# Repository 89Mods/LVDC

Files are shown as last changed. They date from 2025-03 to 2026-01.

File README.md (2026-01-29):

# LVDC
Replica of the [Launch Vehicle Digital Computer](https://www.ibiblio.org/apollo/LVDC.html) using 74-series logic. This projects only aims to keep the CPU Architecture binary-compatible with the original. Implementation details, IO Peripherals and Software are all originally created by me. This is party due to the fact that detailed hardware descriptions (i.e. schematics) are not as abundant for the LVDC as for the AGC, but also because this project doubled as a challenge to myself to implement such an odd instruction set, but using every trick I’ve learned from my years of engineering integrated circuit layouts. It turns out that applying nanoscale engineering tricks to a macroscale discrete logic build can work out quite well. The clock speed of this computer is 2.5MHz, but it can probably go faster.

This LVDC is accurate to the original in the sense that it executes the same instructions that function the exact same, has the same memory layout (including special locations like HOP save and MQ) and can execute snippets of original LVDC code.

The differences are:
  - This computer is parallel and not bit-serial, and is also microcoded
  - It is implemented using 74-series logic and not discrete transistors (I wish to be able to take it with me to events, so it couldn’t get too big)
  - Everything hooked up to the PIO (IO read/write) instruction is my own invention, with the exception of the the interrupt latch clear IO location, which it shares with the original LVDC
  - Instruction cycles times are much faster, probably on an order of magnitude or more
  - The hardware multiply/divide circuitry (as designed so far) does NOT share the inacuracies in low-order bits as the original LVDC, instead always producing the 100% correct result

Infact, I took the most liberties with the IO Card, which contains various modern components hooked into the CPU’s IO Bus. Its mostly a random mashup of things I thought would be cool (there is even a Commodore SID replica in there) to demonstrate the computer with.

The most significant addition is that of a front panel (the original LVDC was an embedded device with no user interface) which is a bit like a DSKY, but stripped down and only capable of displaying in hexadecimal. The panel is optional. I can be safely removed and the computer used as a true embedded device.

Software wise, things are still WiP. Two ROMs provide just enough storage for a small bootloader to initialize the entire SRAM from a flash IC. Sadly, core memory is far too bulky and expensive, so this will have to do. I created a mini-OS for this system that allows a user to control the computer by typing in commands consisting of a Noun and Verb into the keypad.

**Known Issues:**
  - The HOP Save feature is bugged. The Instruction Pointer in the stored value is off by one. Trying to return with it will return execution to the transfer or HOP instruction that started the subroutine call, not the one following it, triggering an infinite loop. Fixed for now in software by modifying the saved value before return.
  - While all schematic files have been updated with fixes to additional problems discovered post-production, the schematic layout for the Control board still need to be redone.
  - The EXM instruction has only been minimally tested because I don’t understand how it is useful (thing takes up half a dozen ICs just to handle weird edge cases caused by it and I’m still left scratching my head on how I’m supposed to use it).
  - The hardware multiply/divide functionality has yet to be physically implemented. In `LVDC.circ` you can see that I have designed it, but I’ve yet to translate this to a PCB design because I couldn’t get it made yet anyways (its the most expensive part of the whole computer).
  - The interrupt logic sometimes does not reset properly and I don’t understand why

# Repository Structure

`LVDC.circ` is where I prototyped the logic design using Logisim Evolution, but it is quite bugged and now far outdated.

`microcode_gen.c` is the C program that spits out the raw binary images for the microcode ROMs from a more high-level description.

`KiCad` is where the schematics and PCB layouts live. Related to this is `CPLD`, which holds the HDL code for the CPLD on the GPIO PCB.

`Bench` is the result of using [KiCadVerilog](https://github.com/89Mods/KiCadVerilog) to automatically extract Verilog netlists out of the KiCad schematic files and using them to build a simulation of the computer for verification purposes before starting physical production. This is quite a novel approach and I used it here for the first time.

`behavioral` contains a Behavioral Verilog model of the LVDC I used as a starting point. It is incredibly inaccurate as I have not updated it in same time.

`Programs` contains the software I’m writing for this computer. Currently just the Bootloader source and the WiP mini-OS mentioned earlier. [My fork of the AS Macroassembler](https://github.com/AvalonSemiconductors/asl-avalonsemi/) has support for the LVDC, and this is used to assemble all LVDC code in this directory.

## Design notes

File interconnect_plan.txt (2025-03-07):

AS2650-2 on FP

Required backplane signals

Bus (26)
INSTR (13)
NC
CLK
RST
VCC
GND

Total: 44

On dedicated ribbon connectors:
From Register to Memory:
INSTR_SECTOR (4)
INSTR_MODULE (3)
INSTR_ADD (8)
DATA_SECTOR (4)
DATA_MODULE (3)
Total: 22

From Registers to ALU:
Accum (26)

Total: 26

Ctrl to ALU:
IS_RSU
ALU_R
ALU_ISS

Total: 3

Ctrl to Registers:
ACCW
R_A
CDS
TRA
INCPC
R_H
HOPW
H_CYC_1
CSYLLABLE
ACCUM_ZERO
ACCUM_NEGATIVE

Total: 11

Ctrl to Memory:
FETCH_CYC
MEM_WR
MEM_RD
irupt
EXM_EXEC_I
EXM_SECTOR (3)
RESIDUAL_I
IS_EXM_I
PQ_ADDR
HOP_INSTE

Total: 12

Ctrl to muldiv:
OUTPUT_PQ
MUL_RST
LDX
LDY
IS_DIV
LDZ
START
IS_ACTIVE

Total: 8

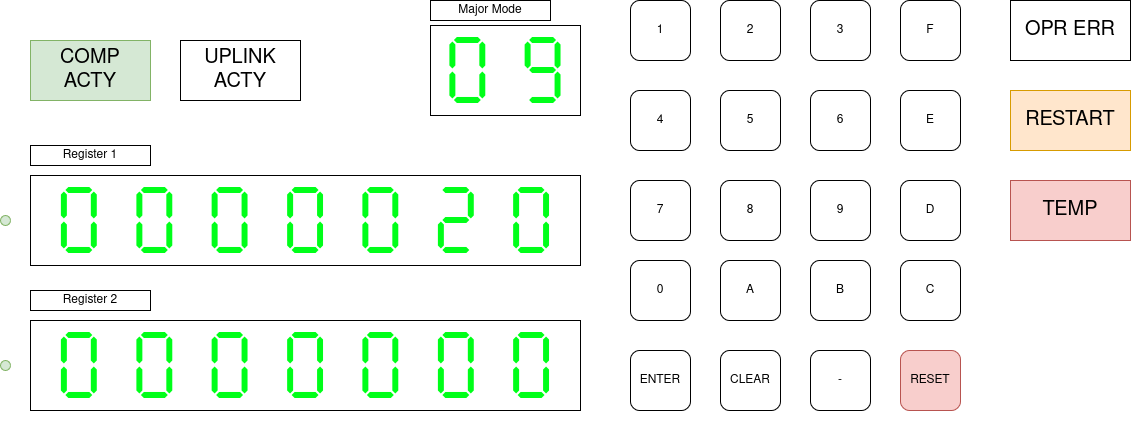
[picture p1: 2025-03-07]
FP_DESIGN.png

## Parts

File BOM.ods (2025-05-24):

Value | Qty | Mouser | Unit Price | Total Price | Comment
74HCT04 | 10 | 771-74HCT04D-Q100118 | 0.386 | 3.86
74HCT157 | 60 | 771-74HCT157D-T | 0.219 | 13.14
74HCT08 | 18 | 771-74HCT08D-T | 0.168 | 3.024
74HCT32 | 15 | 771-74HCT32D-T | 0.168 | 2.52
74HCT153 | 16 | 771-74HCT153D-T | 0.295 | 4.72
74HCT574 | 25 | 771-74HCT574D-T | 0.295 | 7.375
Terminal Block 01x02 | 3 | 651-1548128 | 1.02 | 3.06
Resistor Network | 10 | 652-4609M-1LF-10K | 0.363 | 3.63
74HCT244 | 22 | 771-74HCT244D-Q100 | 0.34 | 7.48
74HCT163 (DIP) | 1 | 595-CD74HCT163E | 0.855 | 0.855
74HCT00 | 5 | 771-74HCT00D-Q100118 | 0.352 | 1.76
74HCT74 | 15 | 771-74HCT74D-Q100118 | 0.217 | 3.255
74HCT138 | 10 | 771-74HCT138D-T | 0.177 | 1.77
MCP1319MT-29LE | 3 | 579-MCP1319MT29LE/OT | 0.817 | 2.451
74LV1T34DCK | 31 | 595-SN74LV1T34DCKR | 0.135 | 4.185
74ALVC164245 | 1 | 972-74ALVC164245PVG | 1.28 | 1.28
LM358 | 1 | 595-LM358P | 0.219 | 0.219
74AHC1G86 | 10 | 621-74AHC1G86W5-7 | 0.141 | 1.41
8MHz can Osc | 1 | 520-TCH800-X | 2.99 | 2.99
74HCT11 | 5 | 771-74HCT11D-Q100J | 0.371 | 1.855
74HCT02 | 5 | 771-74HCT02D-T | 0.228 | 1.14
74HCT245 | 5 | 771-74HCT245DQ100J | 0.713 | 3.565
74HC86 | 10 | 771-74HC86D-Q100118 | 0.144 | 1.44
LM35-LP | 5 | 926-LM35DZ/LFT4 | 1.27 | 6.35
LM397 | 5 | 926-LM397MF/NOPB | 1.14 | 5.7
74LVC573 | 5 | 771-74LVC573APW-T | 0.333 | 1.665
65LV256AL | 3 | 870-65LV256AL-45TLA3 | 3.35 | 10.05
1µF Caps | Many | 810-CGA4J3X7R1H105MS
 |  |  |  | 100.749
Value | Qty |  |  | Total Price | Link
2x15 2.54mm Male | 3 |  |  | 4.19 | https://de.aliexpress.com/item/1005004266492521.html
2x22 2.54mm Male | 6 |  |  | 2.35 | https://de.aliexpress.com/item/1005006240551154.html
2x04 2.54mm Male | 3 |  |  | 2.95 | https://de.aliexpress.com/item/1005004266492521.html
2x06 2.54mm Male | 4 |  |  | 3.05 | https://de.aliexpress.com/item/1005004266492521.html
28C16 | 5 |  |  | 12.99 | https://de.aliexpress.com/item/4001115719545.html
2x25 2.54mm Male | 2 |  |  | 0 | Covered by earlier entry
SM420561 | 16 |  |  | 6.38 | https://de.aliexpress.com/item/1005004362200093.html
2x05 2.54mm Male | 1 |  |  | 2.89 | https://de.aliexpress.com/item/1005004266492521.html
1x04 2.54mm Male | 3 |  |  | 1.59 | https://de.aliexpress.com/item/4000988113226.html
1x04 2.54mm Female | 2 |  |  | 1.35 | https://de.aliexpress.com/item/4001198421663.html
2x22 2.54mm Female | 6 |  |  | 3.19 | https://de.aliexpress.com/item/1005005884302067.html
02x12 2.54mm Male | 2 | N/A | N/A | 0 | Covered by earlier entry
01x03 2.54mm Male | 5 | N/A | N/A | 0 | Covered by earlier entry
2x15 Ribbon Band | 1 |  |  | 3.59 | https://de.aliexpress.com/item/1005004762590129.html
2x04 Ribbon Band | 2 |  |  | 4.78 | https://de.aliexpress.com/item/1005004762590129.html
2x06 Ribbon Band | 2 |  |  | 5.18 | https://de.aliexpress.com/item/1005004762590129.html
2x12 Ribbon Band | 1 |  |  | 3.19 | https://de.aliexpress.com/item/1005004762590129.html
2x25 Ribbon Band (long) | 1 |  |  | 8.49 | https://de.aliexpress.com/item/1005004762590129.html
Shrinkwrap | 1 |  |  | 1.85 | https://de.aliexpress.com/item/1005008146302901.html
65LV256AL |  |  |  | 68.01
 |  |  |  | 168.759
 | 1 |  |  |  | https://de.aliexpress.com/item/32979408725.html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

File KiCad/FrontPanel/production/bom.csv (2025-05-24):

Designator | Footprint | Quantity | Value | LCSC Part #
_6, _5, _4, _3, _2, |  | 6
C1, C3, C4 | 0805 | 3 | 1µF
C2 | 0805 | 1 | 100nF
C5 | CP_Radial_D6.3mm_P2.50mm | 1 | 1000µF
D1, D10, D11, D12, D13, D14, D15, D16, D17, D18, D19, D2, D20, D3, D4, D5, D6, D7, D8, D9 | 1206 | 20 | LED
D21, D22 | LED_D5.0mm | 2 | LED
J1 | PinHeader_2x25_P2.54mm_Vertical | 1 | TO_FP
Q1, Q2, Q3, Q4, Q5 | SOT-23 | 5 | 2N7002
R1, R10, R11, R12, R13, R14, R15, R16, R17, R18, R19, R2, R3, R4, R5, R6, R7, R8, R9 | 1206 | 19 | 1K
R20, R21, R22, R23, R24, R25, R26, R27, R28, R29, R30, R31, R32, R33, R34, R35 | 1206 | 16 | 470
R36, R37, R38, R39, R40, R41, R42 | 1206 | 7 | 330
R43 | 1206 | 1 | 200K
SW1, SW10, SW11, SW12, SW13, SW14, SW15, SW16, SW17, SW18, SW19, SW2, SW20, SW3, SW4, SW5, SW6, SW7, SW8, SW9 | SW_Cherry_MX_1.00u_PCB | 20 | SW_Push
U1, U4, U5 | SO-20_12.8x7.5mm_P1.27mm | 3 | 74HC244
U10, U11, U12, U13, U14, U15, U16, U17, U18, U19, U20, U21, U6, U7, U8, U9 | 7SegmentLED_LTS6760_LTS6780 | 16 | SM420561N
U2, U3 | SO-16_3.9x9.9mm_P1.27mm | 2 | 74HCT138
U22 | SOIC-8_3.9x4.9mm_P1.27mm | 1 | NE555D

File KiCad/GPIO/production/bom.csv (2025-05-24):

Designator | Footprint | Quantity | Value | LCSC Part #
C1 | CP_Radial_D4.0mm_P2.00mm | 1 | 10µF
C10, C11, C12, C13, C14, C15, C16, C17, C18, C2, C3, C4, C5, C6, C7, C8, C9 | 0805 | 17 | 1µF
D1, D2 | 1206 | 2 | LED
J1 | PinHeader_2x05_P2.54mm_Vertical | 1 | JTAG
J10, J3, J4, J5 | PinHeader_1x01_P2.54mm_Vertical | 4 | Conn_01x01
J11 | PinHeader_2x25_P2.54mm_Vertical | 1 | TO_FP
J12, J16, J7, J8 | PinHeader_1x04_P2.54mm_Vertical | 4 | Conn_01x04
J13, J14 | PinHeader_1x08_P2.54mm_Vertical | 2 | Conn_01x08
J15, J9 | PinSocket_1x04_P2.54mm_Vertical | 2 | RADIO_MODULE
J2 | PinHeader_2x22_P2.54mm_Vertical | 1 | TO_BACKPLANE
J6 | TerminalBlock_bornier-2_P5.08mm | 1 | AUDIO_OUT
R1, R10, R11, R13, R14, R16, R17, R2, R20, R21, R22, R23, R24, R25, R26, R27, R28, R29, R3, R30, R31, R32, R33, R34, R35, R36, R37, R39, R4, R5, R6, R7, R8, R9 | 1206 | 34 | 10K
R12 | 1206 | 1 | 330
R15, R18 | 1206 | 2 | 1K
R19 | 1206 | 1 | 33K
R38 | 1206 | 1 | 2K
R40 | 1206 | 1 | 1M
RV1 | Potentiometer_ACP_CA9-V10_Vertical | 1 | 10K
U1 | LQFP-100_14x14mm_P0.5mm | 1 | EPM240T100
U10 | TSSOP-48_6.1x12.5mm_P0.5mm | 1 | SN74ALVC164245DGG
U11, U12, U13, U14, U20, U21, U22, U24, U27, U28, U33, U34, U35, U8, U9 | SOT-23-5 | 15 | SN74LV1T34DCK
U15 | SO-14_3.9x8.65mm_P1.27mm | 1 | 74HC74
U16 | DIP-40_W15.24mm_Socket | 1 | gfmpw1-multi
U17, U18 | DIP-8_W7.62mm | 2 | DAC7611
U19 | DIP-8_W7.62mm | 1 | LM358
U2 | SOT-23-5_HandSoldering | 1 | MCP1319MT-29LE-OT
U23 | DIP-18_W7.62mm | 1 | HT12D
U25, U26, U6 | SO-20_12.8x7.5mm_P1.27mm | 3 | 74HCT244
U29 | SO-14_3.9x8.65mm_P1.27mm | 1 | 74HC32
U3 | DIP-8_W7.62mm_Socket | 1 | W25Q32FVSS
U30, U5 | SO-20_12.8x7.5mm_P1.27mm | 2 | 74HC574
U31 | SOT-23-5_HandSoldering | 1 | 74AHC1G86
U32 | DIP-18_W7.62mm | 1 | HT12E
U4 | SOT-223-3_TabPin2 | 1 | AMS1117-3.3
U7 | SO-14_3.9x8.65mm_P1.27mm | 1 | 74HCT74
X1 | Oscillator_DIP-8 | 1 | CXO_DIP8

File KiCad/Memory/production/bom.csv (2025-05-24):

Designator | Footprint | Quantity | Value | LCSC Part #
C1, C3, C5, C7 | CP_Radial_D4.0mm_P2.00mm | 4 | 10µF
C10, C11, C12, C13, C14, C2, C4, C6, C8, C9 | 0805 | 10 | 100nF
D1 | 1206 | 1 | LED
J1 | PinHeader_2x06_P2.54mm_Vertical | 1 | FROM_CTRL
J2 | PinHeader_2x12_P2.54mm_Vertical | 1 | FROM_REGS
J3 | PinHeader_2x22_P2.54mm_Vertical | 1 | TO_BACKPLANE
R1 | 1206 | 1 | 1K
R10, R2, R3, R4, R5, R6, R7, R8, R9 | 1206 | 9 | 10K
RN1, RN2, RN3 | R_Array_SIP9 | 3 | R_Network08
U1, U5 | SO-14_3.9x8.65mm_P1.27mm | 2 | 74HCT32
U10, U11, U12, U4, U9 | SO-16_3.9x9.9mm_P1.27mm | 5 | 74HCT157
U13 | SO-20_12.8x7.5mm_P1.27mm | 1 | 74HC688
U14, U2, U8 | SO-14_3.9x8.65mm_P1.27mm | 3 | 74HCT08
U15 | SO-14_3.9x8.65mm_P1.27mm | 1 | 74HC32
U16, U17 | DIP-24_W15.24mm | 2 | 28C16
U18 | SO-14_3.9x8.65mm_P1.27mm | 1 | 74HCT00
U19 | SO-14_3.9x8.65mm_P1.27mm | 1 | 74HC02
U20, U21, U22, U23 | SO-20_12.8x7.5mm_P1.27mm | 4 | 74HCT245
U24, U25, U26, U27 | DIP-28_W7.62mm | 4 | IS61C256
U3 | SO-14_3.9x8.65mm_P1.27mm | 1 | 74HCT04
U6, U7 | SO-14_3.9x8.65mm_P1.27mm | 2 | 74HCT11

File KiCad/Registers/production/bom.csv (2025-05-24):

Designator | Footprint | Quantity | Value | LCSC Part #
C1, C10, C11, C13, C14, C15, C3, C6, C8, C9 | 0805 | 10 | 100nF
C12, C16, C17, C2, C4, C5, C7 | CP_Radial_D4.0mm_P2.00mm | 7 | 10µF
D1, D10, D11, D12, D13, D14, D15, D16, D2, D3, D4, D5, D6, D7, D8, D9 | 1206 | 16 | LED
J1 | PinHeader_2x22_P2.54mm_Vertical | 1 | TO_BACKPLANE
J2 | PinHeader_2x15_P2.54mm_Vertical | 1 | ACCUMULATOR_OUT
J3 | PinHeader_2x06_P2.54mm_Vertical | 1 | FROM_CTRL
J4 | PinHeader_2x12_P2.54mm_Vertical | 1 | TO_MEMORY
J5 | PinHeader_2x15_P2.54mm_Vertical | 1 | TO_FP
R1, R2, R3, R4, R5, R6, R8 | 1206 | 7 | 1K
R7, R9 | 1206 | 2 | 4.7K
U1, U11, U16, U17, U18, U33, U34, U35, U36, U7 | SO-20_12.8x7.5mm_P1.27mm | 10 | 74HC574
U10, U13, U2, U20, U21, U22, U23, U24, U25, U26, U3, U41, U42, U43, U44, U45, U5, U6, U9 | SO-16_3.9x9.9mm_P1.27mm | 19 | 74HCT157
U12, U15, U4, U46, U47, U48, U49, U8 | SO-20_12.8x7.5mm_P1.27mm | 8 | 74HC244
U14, U19, U31 | SO-14_3.9x8.65mm_P1.27mm | 3 | 74HC74
U27, U28 | SO-14_3.9x8.65mm_P1.27mm | 2 | 74HC86
U29, U30 | SO-14_3.9x8.65mm_P1.27mm | 2 | 74HC08
U32 | SO-14_3.9x8.65mm_P1.27mm | 1 | 74HCT32
U37, U38, U39, U40 | SO-20_12.8x7.5mm_P1.27mm | 4 | 74HC688
U50 | SOIC-6 | 1 | 74AHC1G04

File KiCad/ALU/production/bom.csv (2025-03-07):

Designator | Footprint | Quantity | Value | LCSC Part #
C1, C10, C11, C12, C13, C14, C15, C16, C17, C18, C19, C20, C4, C6, C8 | 0805 | 15 | 100nF
C2, C21, C22, C3, C5, C7, C9 | CP_Radial_D4.0mm_P2.00mm | 7 | 10µF
D1, D2, D3 | 1206 | 3 | LED
J1 | PinHeader_2x15_P2.54mm_Vertical | 1 | ACCUMULATOR
J2 | PinHeader_2x22_P2.54mm_Vertical | 1 | TO_BACKPLANE
J3 | PinHeader_2x04_P2.54mm_Vertical | 1 | FROM_CTRL
R1, R2, R3, R4 | 1206 | 4 | 1K
TP1 | TestPoint_Pad_1.5x1.5mm | 1 | TestPoint
U1 | SO-14_3.9x8.65mm_P1.27mm | 1 | 74HCT04
U10, U11, U12, U13, U14, U15, U2, U3, U4, U40, U41, U43, U44, U46, U47, U49, U5, U6, U7, U8, U9 | SO-16_3.9x9.9mm_P1.27mm | 21 | 74HCT157
U16, U17, U18, U19, U20, U21, U22 | DIP-24_W15.24mm | 7 | 74LS181
U23, U24 | SO-14_3.9x8.65mm_P1.27mm | 2 | 74HCT08
U25, U27 | SO-14_3.9x8.65mm_P1.27mm | 2 | 74HCT32
U26, U28, U29, U30, U31, U32, U33, U34, U35, U36, U37, U38, U39 | SO-16_3.9x9.9mm_P1.27mm | 13 | 74HCT153
U42, U45, U48, U50 | SO-20_12.8x7.5mm_P1.27mm | 4 | 74HCT574

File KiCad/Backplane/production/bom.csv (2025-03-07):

Designator | Footprint | Quantity | Value | LCSC Part #
_5, _4, _3, _2, |  | 5
C1 | 0805 | 1 | 100nF
C2 | CP_Radial_D4.0mm_P2.00mm | 1 | 10µF
C3 | 0805 | 1 | 1µF
D1, D2 | 1206 | 2 | LED
J1 | PinHeader_2x22_P2.54mm_Vertical | 1 | SLOT1
J2 | PinHeader_2x22_P2.54mm_Vertical | 1 | SLOT2
J3 | PinHeader_2x22_P2.54mm_Vertical | 1 | SLOT3
J4 | PinHeader_2x22_P2.54mm_Vertical | 1 | SLOT4
J5 | PinHeader_2x22_P2.54mm_Vertical | 1 | SLOT5
J6 | PinHeader_2x22_P2.54mm_Vertical | 1 | GPIO
J7, J8 | TerminalBlock_bornier-2_P5.08mm | 2 | Screw_Terminal_01x02
R1, R2, R3, R4, R5, R6, R7 | 1206 | 7 | 2K
RN1, RN2, RN3 | R_Array_SIP9 | 3 | R_Network08
U1 | DIP-14_W7.62mm | 1 | 74HCT04

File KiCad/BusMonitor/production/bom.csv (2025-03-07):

Designator | Footprint | Quantity | Value | LCSC Part #
C1 | 0805 | 1 | 100nF
C2 | CP_Radial_D4.0mm_P2.00mm | 1 | 10µF
D1, D10, D11, D12, D13, D14, D15, D16, D17, D18, D19, D2, D20, D21, D22, D23, D24, D25, D26, D27, D28, D29, D3, D30, D31, D32, D33, D34, D35, D36, D37, D38, D39, D4, D40, D5, D6, D7, D8, D9 | 1206 | 40 | LED
J1 | PinHeader_2x22_P2.54mm_Vertical | 1 | TO_BACKPLANE
R1, R2, R3, R4, R5 | 1206 | 5 | 330
U1, U2, U3, U4, U5 | SO-20_12.8x7.5mm_P1.27mm | 5 | 74HCT244

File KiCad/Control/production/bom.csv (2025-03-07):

Designator | Footprint | Quantity | Value | LCSC Part #
C1, C10, C11, C12, C13, C7, C8, C9 | 0805 | 8 | 100nF
C2, C3, C4, C5, C6 | CP_Radial_D4.0mm_P2.00mm | 5 | 10µF
D1, D2, D3, D4, D5, D6, D7, D8 | 1206 | 8 | LED
J1 | PinHeader_2x22_P2.54mm_Vertical | 1 | TO_BACKPLANE
J2 | PinHeader_2x04_P2.54mm_Vertical | 1 | TO_ALU
J3 | PinHeader_2x06_P2.54mm_Vertical | 1 | TO_MEMORY
J4 | PinHeader_2x06_P2.54mm_Vertical | 1 | TO_REGISTERS
J5 | PinHeader_2x04_P2.54mm_Vertical | 1 | TO_MULDIV
J6, J7, J8 | PinHeader_1x01_P2.54mm_Vertical | 3 | Conn_01x01
R1, R10, R11, R2, R6, R8, R9 | 1206 | 7 | 1K
R3 | 1206 | 1 | 4.7K
R4, R5, R7 | 1206 | 3 | 15K
U1, U7 | SO-20_12.8x7.5mm_P1.27mm | 2 | 74HC574
U10, U16, U22, U29 | SO-14_3.9x8.65mm_P1.27mm | 4 | 74HCT32
U11, U21, U24, U25, U28, U30, U9 | SO-14_3.9x8.65mm_P1.27mm | 7 | 74HCT08
U12, U13 | DIP-24_W15.24mm_Socket | 2 | 28C16
U14 | DIP-16_W7.62mm | 1 | 74HCT163
U15 | SO-14_3.9x8.65mm_P1.27mm | 1 | 74HCT00
U17, U2, U23 | SO-14_3.9x8.65mm_P1.27mm | 3 | 74HCT04
U18, U19, U26, U27 | SO-14_3.9x8.65mm_P1.27mm | 4 | 74HCT74
U20, U3, U36, U37, U38, U39, U4, U5, U6, U8 | SO-16_3.9x9.9mm_P1.27mm | 10 | 74HCT157
U31, U32 | DIP-16_W7.62mm | 2 | 74HC85
U33 | SO-14_3.9x8.65mm_P1.27mm | 1 | 74HC74
U34 | SO-20_12.8x7.5mm_P1.27mm | 1 | 74HC688
U35 | SO-14_3.9x8.65mm_P1.27mm | 1 | 74HC00

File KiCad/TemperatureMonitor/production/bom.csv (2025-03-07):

Designator | Footprint | Quantity | Value | LCSC Part #
C1 | 0805 | 1 | 1µF
D1 | 1206 | 1 | LED
J1 | PinHeader_1x03_P2.54mm_Vertical | 1 | Conn_01x03
R1 | 1206 | 1 | 620
R2 | 1206 | 1 | 2K
R3 | 1206 | 1 | 1K
R4 | 1206 | 1 | 4.7K
U1 | TO-92_Inline | 1 | LM35-LP
U2 | SOT-23-5 | 1 | LM397
U3 | SOT-23-5 | 1 | SN74LV1T34DCK

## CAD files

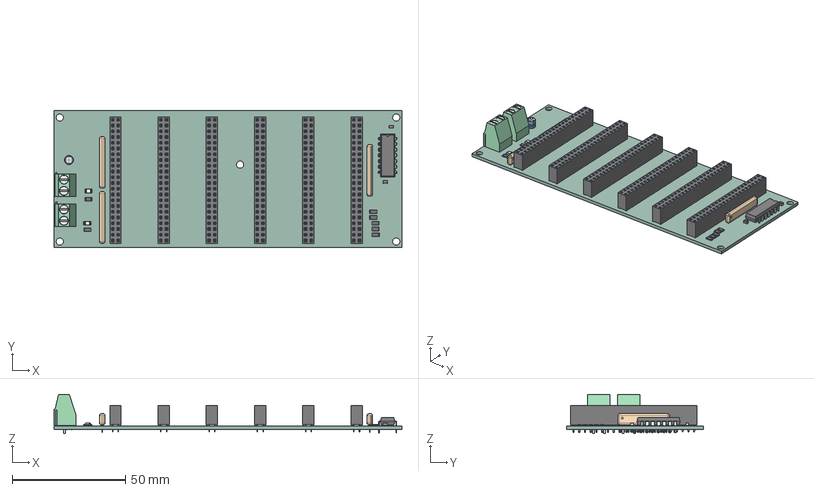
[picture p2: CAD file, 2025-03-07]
KiCad/Backplane/Backplane.step
154.0 x 60.5 x 17.3 mm
R_1206_3216Metric x 7
TerminalBlock_Phoenix_MKDS_15_2_1x02_P500mm_Horizontal x 2
LED_1206_3216Metric x 2
C_0805_2012Metric x 2
DIP-14_W7.62mm
R_Array_SIP9 x 3
CP_Radial_D40mm_P200mm
PinSocket_2x22_P2.54mm_Vertical x 6
Backplane_PCB

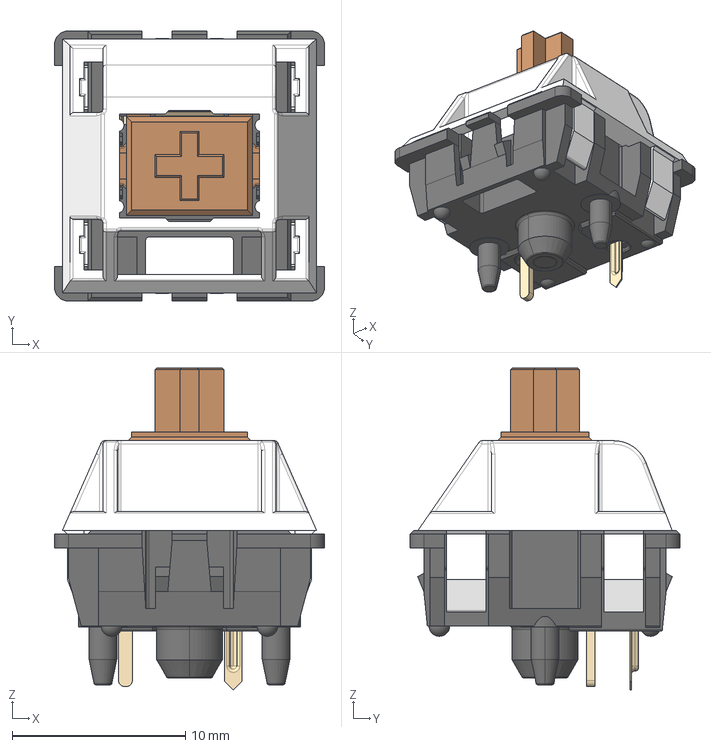
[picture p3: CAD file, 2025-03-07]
KiCad/FrontPanel/SW_Cherry_MX_PCB.stp
15.6 x 15.6 x 18.6 mm

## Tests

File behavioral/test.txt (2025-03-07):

0000006f
0000008f
00000008
00000000
00000001
00000000
00000000
00000000
00000000
00000000
00000000
00000000
00000000
00000000
00000000
00000000
00000000
00000000
00000000
00000000
00000000
00000000
00000000
00000000
00000000
00000000
00000000
00000000
00000000
00000000
00000000
00000000
00000000
00000000
00000000
00000000
00000000
00000000
00000000
00000000
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

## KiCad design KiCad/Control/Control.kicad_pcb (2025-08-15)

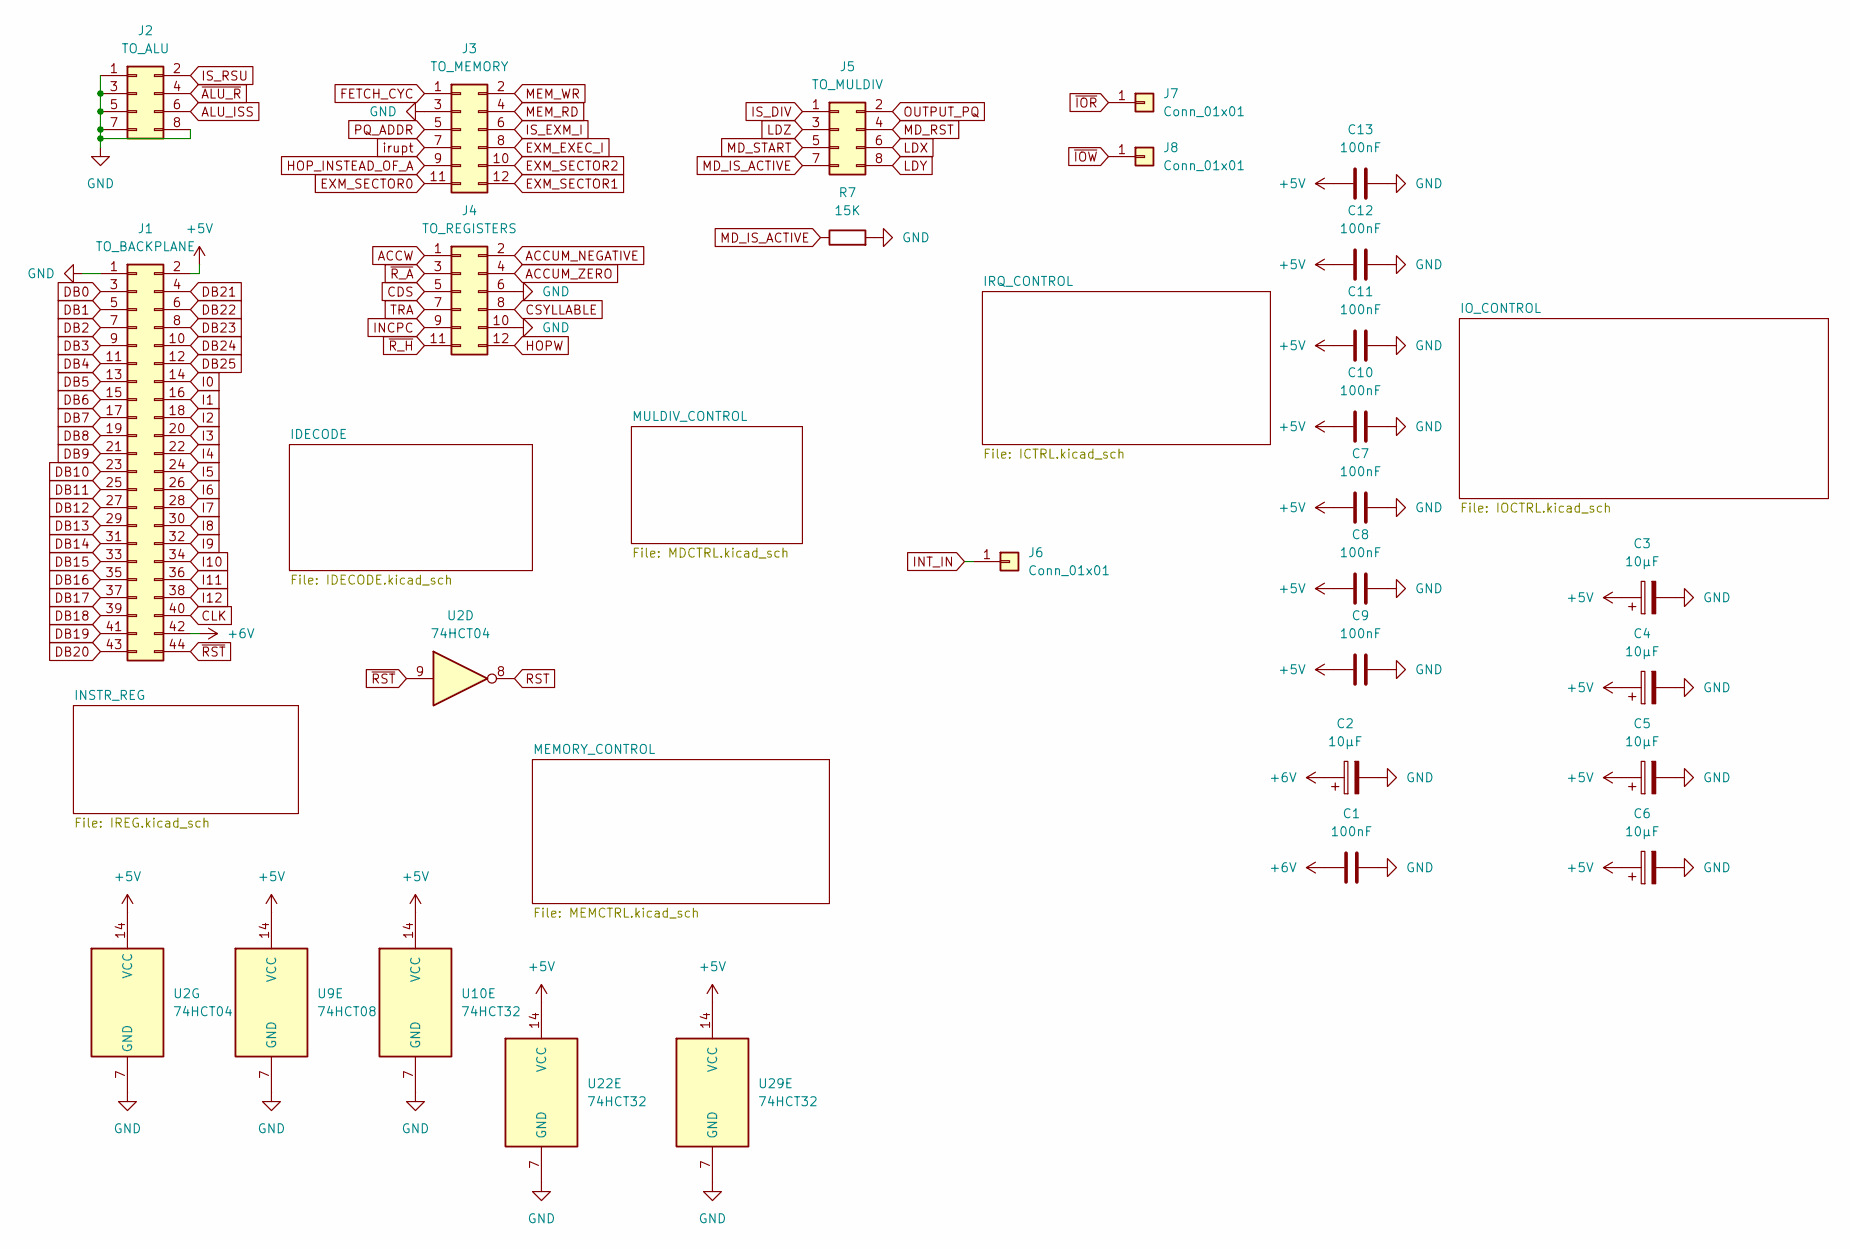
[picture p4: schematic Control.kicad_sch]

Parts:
C1, C7, C8, C9, C10, C11, C12, C13: 100nF; C_0805_2012Metric_Pad1.18x1.45mm_HandSolder
C2, C3, C4, C5, C6: 10µF; CP_Radial_D4.0mm_P2.00mm
J1: TO_BACKPLANE; PinHeader_2x22_P2.54mm_Vertical
J2: TO_ALU; PinHeader_2x04_P2.54mm_Vertical
J3: TO_MEMORY; PinHeader_2x06_P2.54mm_Vertical
J4: TO_REGISTERS; PinHeader_2x06_P2.54mm_Vertical
J5: TO_MULDIV; PinHeader_2x04_P2.54mm_Vertical
J6, J7, J8: Conn_01x01; PinHeader_1x01_P2.54mm_Vertical
R7: 15K; R_1206_3216Metric_Pad1.30x1.75mm_HandSolder
U2: 74HCT04; SO-14_3.9x8.65mm_P1.27mm
U9: 74HCT08; SO-14_3.9x8.65mm_P1.27mm
U10, U22, U29: 74HCT32; SO-14_3.9x8.65mm_P1.27mm

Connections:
+5V: C3.1, C4.1, C5.1, C6.1, C7.1, C8.1, C9.1, C10.1, C11.1, C12.1, C13.1, J1.2, U2.14 (VCC), U9.14 (VCC), U10.14 (VCC), U22.14 (VCC), U29.14 (VCC); also elsewhere on the board
+6V: C1.1, C2.1, J1.42; also elsewhere on the board
ACCUM_NEGATIVE: J4.2; also elsewhere on the board
ACCUM_ZERO: J4.4; also elsewhere on the board
ACCW: J4.1; also elsewhere on the board
ALU_ISS: J2.6; also elsewhere on the board
CDS: J4.5; also elsewhere on the board
CLK: J1.40; also elsewhere on the board
CSYLLABLE: J4.8; also elsewhere on the board
DB0: J1.3; also elsewhere on the board
DB1: J1.5; also elsewhere on the board
DB2: J1.7; also elsewhere on the board
DB3: J1.9; also elsewhere on the board
DB4: J1.11; also elsewhere on the board
DB5: J1.13; also elsewhere on the board
DB6: J1.15; also elsewhere on the board
DB7: J1.17; also elsewhere on the board
DB8: J1.19; also elsewhere on the board
DB9: J1.21; also elsewhere on the board
DB10: J1.23; also elsewhere on the board
DB11: J1.25; also elsewhere on the board
DB12: J1.27; also elsewhere on the board
DB13: J1.29; also elsewhere on the board
DB14: J1.31; also elsewhere on the board
DB15: J1.33; also elsewhere on the board
DB16: J1.35; also elsewhere on the board
DB17: J1.37; also elsewhere on the board
DB18: J1.39; also elsewhere on the board
DB19: J1.41; also elsewhere on the board
DB20: J1.43; also elsewhere on the board
DB21: J1.4; also elsewhere on the board
DB22: J1.6; also elsewhere on the board
DB23: J1.8; also elsewhere on the board
DB24: J1.10; also elsewhere on the board
DB25: J1.12; also elsewhere on the board
EXM_EXEC_I: J3.8; also elsewhere on the board
EXM_SECTOR0: J3.11; also elsewhere on the board
EXM_SECTOR1: J3.12; also elsewhere on the board
EXM_SECTOR2: J3.10; also elsewhere on the board
FETCH_CYC: J3.1; also elsewhere on the board
GND: C1.2, C2.2, C3.2, C4.2, C5.2, C6.2, C7.2, C8.2, C9.2, C10.2, C11.2, C12.2, C13.2, J1.1, J2.1, J2.3, J2.5, J2.7, J2.8, J3.3, J4.6, J4.10, R7.2, U2.7 (GND), U9.7 (GND), U10.7 (GND), U22.7 (GND), U29.7 (GND); also elsewhere on the board
HOPW: J4.12; also elsewhere on the board
HOP_INSTEAD_OF_A: J3.9; also elsewhere on the board
I0: J1.14; also elsewhere on the board
I1: J1.16; also elsewhere on the board
I2: J1.18; also elsewhere on the board
I3: J1.20; also elsewhere on the board
I4: J1.22; also elsewhere on the board
I5: J1.24; also elsewhere on the board
I6: J1.26; also elsewhere on the board
I7: J1.28; also elsewhere on the board
I8: J1.30; also elsewhere on the board
I9: J1.32; also elsewhere on the board
I10: J1.34; also elsewhere on the board
I11: J1.36; also elsewhere on the board
I12: J1.38; also elsewhere on the board
INCPC: J4.9; also elsewhere on the board
INT_IN: J6.1; also elsewhere on the board
IS_DIV: J5.1; also elsewhere on the board
IS_EXM_I: J3.6; also elsewhere on the board
IS_RSU: J2.2; also elsewhere on the board
LDX: J5.6; also elsewhere on the board
LDY: J5.8; also elsewhere on the board
LDZ: J5.3; also elsewhere on the board
MD_IS_ACTIVE: J5.7, R7.1; also elsewhere on the board
MD_RST: J5.4; also elsewhere on the board
MD_START: J5.5; also elsewhere on the board
MEM_RD: J3.4; also elsewhere on the board
MEM_WR: J3.2; also elsewhere on the board
OUTPUT_PQ: J5.2; also elsewhere on the board
PQ_ADDR: J3.5; also elsewhere on the board
RST: U2.8; also elsewhere on the board
TRA: J4.7; also elsewhere on the board
irupt: J3.7; also elsewhere on the board
~ALU_R: J2.4; also elsewhere on the board
~IOR: J7.1; also elsewhere on the board
~IOW: J8.1; also elsewhere on the board
~RST: J1.44, U2.9; also elsewhere on the board
~R_A: J4.3; also elsewhere on the board
~R_H: J4.11; also elsewhere on the board

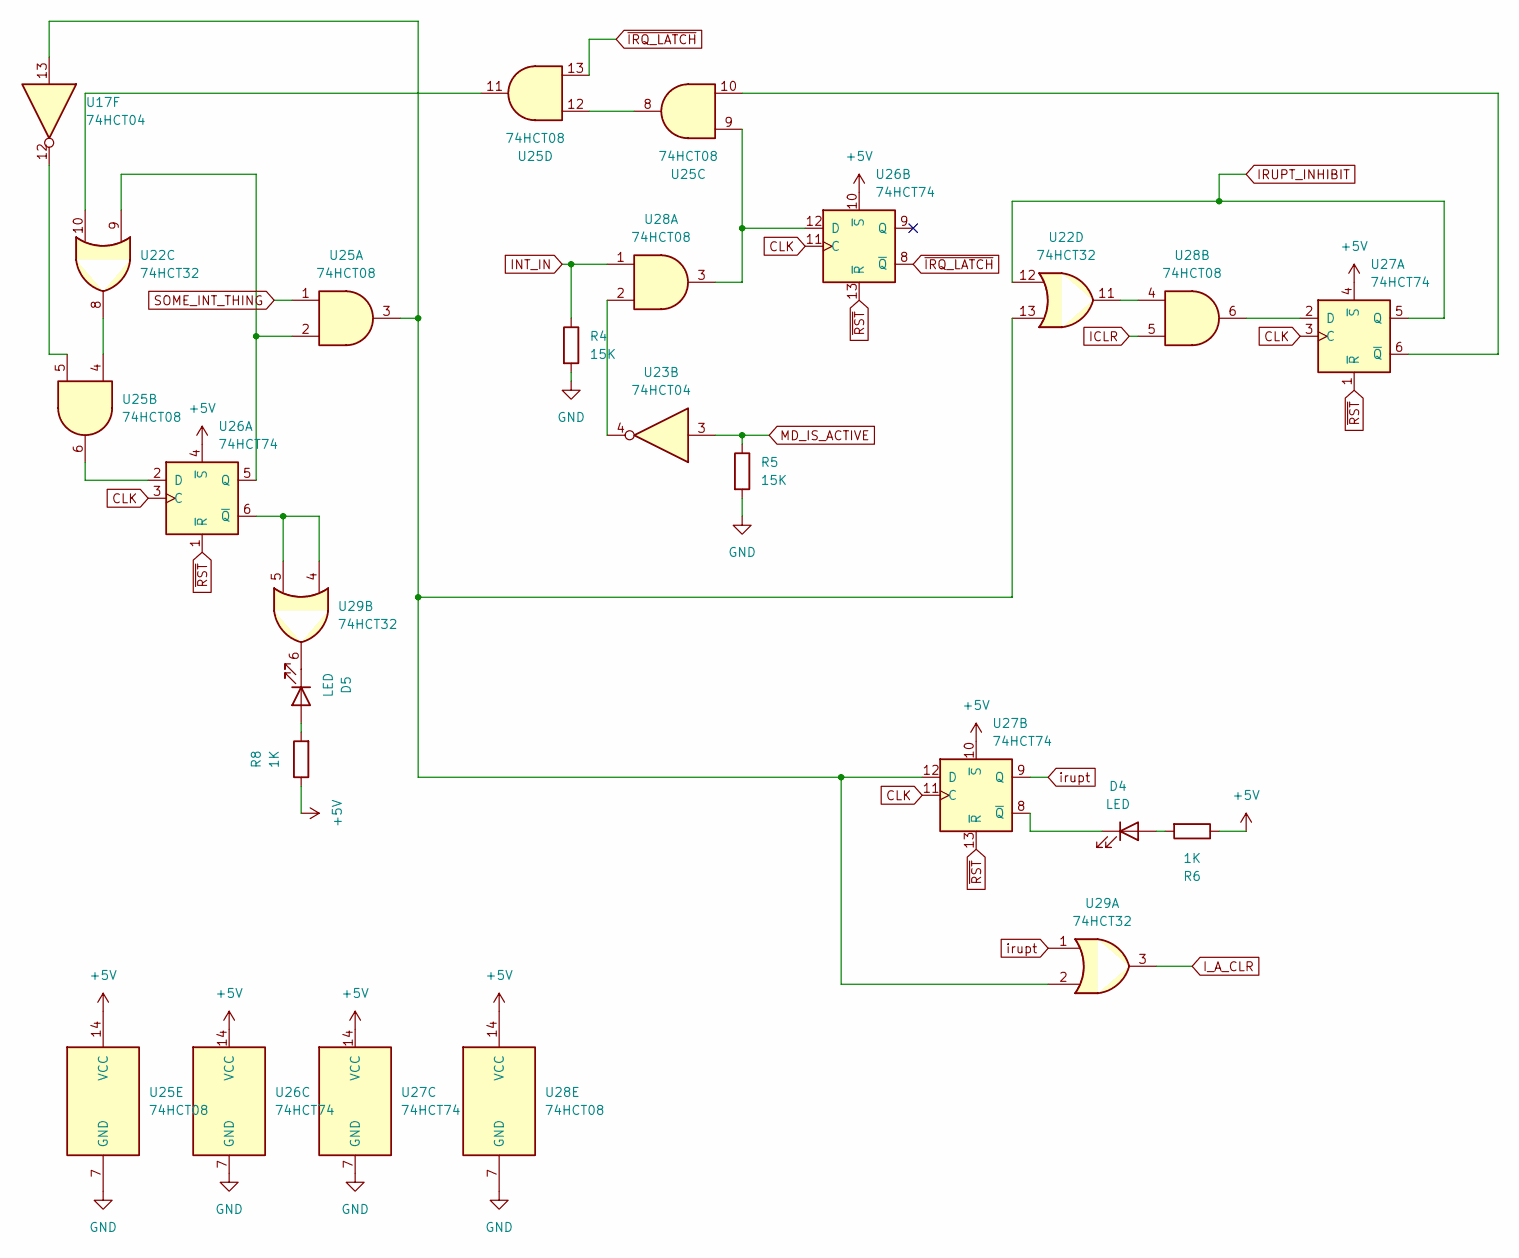
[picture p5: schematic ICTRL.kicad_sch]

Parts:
D4, D5: LED; LED_1206_3216Metric_Pad1.42x1.75mm_HandSolder
R4, R5: 15K; R_1206_3216Metric_Pad1.30x1.75mm_HandSolder
R6, R8: 1K; R_1206_3216Metric_Pad1.30x1.75mm_HandSolder
U17, U23: 74HCT04; SO-14_3.9x8.65mm_P1.27mm
U22, U29: 74HCT32; SO-14_3.9x8.65mm_P1.27mm
U25, U28: 74HCT08; SO-14_3.9x8.65mm_P1.27mm
U26, U27: 74HCT74; SO-14_3.9x8.65mm_P1.27mm

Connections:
+5V: R6.1, R8.1, U25.14 (VCC), U26.4 (~S), U26.10 (~S), U26.14 (VCC), U27.4 (~S), U27.10 (~S), U27.14 (VCC), U28.14 (VCC); also elsewhere on the board
CLK: U26.3 (C), U26.11 (C), U27.3 (C), U27.11 (C); also elsewhere on the board
GND: R4.2, R5.2, U25.7 (GND), U26.7 (GND), U27.7 (GND), U28.7 (GND); also elsewhere on the board
ICLR: U28.5; also elsewhere on the board
INT_IN: R4.1, U28.1; also elsewhere on the board
IRUPT_INHIBIT: U22.12, U27.5 (Q)
I_A_CLR: U29.3; also elsewhere on the board
MD_IS_ACTIVE: R5.1, U23.3; also elsewhere on the board
unnamed: D4.2 (A), R6.2
unnamed: D4.1 (K), U27.8 (~Q)
unnamed: D5.2 (A), R8.2
unnamed: D5.1 (K), U29.6
unnamed: U17.12, U25.5
unnamed: U22.8, U25.4
unnamed: U22.10, U25.11
unnamed: U22.11, U28.4
unnamed: U23.4, U28.2
unnamed: U25.8, U25.12
unnamed: U25.6, U26.2 (D)
unnamed: U22.9, U25.2, U26.5 (Q)
unnamed: U26.6 (~Q), U29.4, U29.5
unnamed: U25.9, U26.12 (D), U28.3
unnamed: U27.2 (D), U28.6
unnamed: U25.10, U27.6 (~Q)
unnamed: U17.13, U22.13, U25.3, U27.12 (D), U29.2
SOME_INT_THING: U25.1; also elsewhere on the board
irupt: U27.9 (Q), U29.1; also elsewhere on the board
~IRQ_LATCH: U25.13, U26.8 (~Q)
~RST: U26.1 (~R), U26.13 (~R), U27.1 (~R), U27.13 (~R); also elsewhere on the board

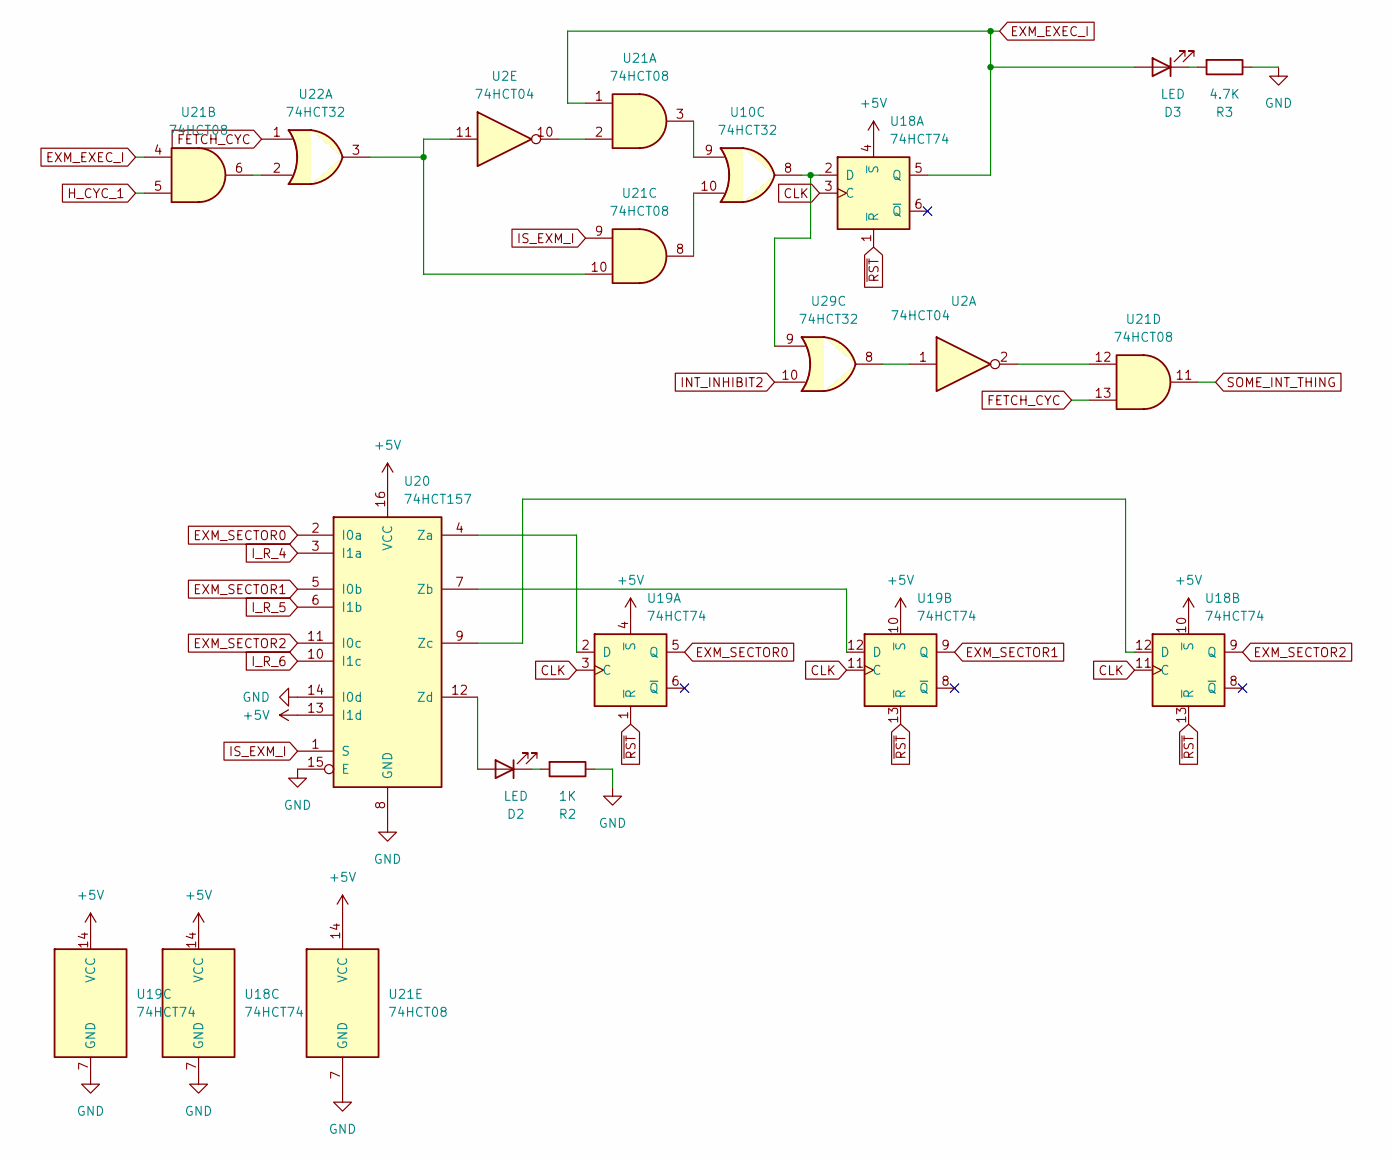
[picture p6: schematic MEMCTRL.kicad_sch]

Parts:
D2, D3: LED; LED_1206_3216Metric_Pad1.42x1.75mm_HandSolder
R2: 1K; R_1206_3216Metric_Pad1.30x1.75mm_HandSolder
R3: 4.7K; R_1206_3216Metric_Pad1.30x1.75mm_HandSolder
U2: 74HCT04; SO-14_3.9x8.65mm_P1.27mm
U10, U22, U29: 74HCT32; SO-14_3.9x8.65mm_P1.27mm
U18, U19: 74HCT74; SO-14_3.9x8.65mm_P1.27mm
U20: 74HCT157; SO-16_3.9x9.9mm_P1.27mm
U21: 74HCT08; SO-14_3.9x8.65mm_P1.27mm

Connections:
+5V: U18.4 (~S), U18.10 (~S), U18.14 (VCC), U19.4 (~S), U19.10 (~S), U19.14 (VCC), U20.13 (I1d), U20.16 (VCC), U21.14 (VCC); also elsewhere on the board
CLK: U18.3 (C), U18.11 (C), U19.3 (C), U19.11 (C); also elsewhere on the board
EXM_EXEC_I: D3.2 (A), U18.5 (Q), U21.1, U21.4; also elsewhere on the board
EXM_SECTOR0: U19.5 (Q), U20.2 (I0a); also elsewhere on the board
EXM_SECTOR1: U19.9 (Q), U20.5 (I0b); also elsewhere on the board
EXM_SECTOR2: U18.9 (Q), U20.11 (I0c); also elsewhere on the board
FETCH_CYC: U21.13, U22.1; also elsewhere on the board
GND: R2.1, R3.1, U18.7 (GND), U19.7 (GND), U20.8 (GND), U20.14 (I0d), U20.15 (E), U21.7 (GND); also elsewhere on the board
H_CYC_1: U21.5; also elsewhere on the board
INT_INHIBIT2: U29.10; also elsewhere on the board
IS_EXM_I: U20.1 (S), U21.9; also elsewhere on the board
I_R_4: U20.3 (I1a); also elsewhere on the board
I_R_5: U20.6 (I1b); also elsewhere on the board
I_R_6: U20.10 (I1c); also elsewhere on the board
unnamed: D2.2 (A), U20.12 (Zd)
unnamed: D2.1 (K), R2.2
unnamed: D3.1 (K), R3.2
unnamed: U2.1, U29.8
unnamed: U2.2, U21.12
unnamed: U2.10, U21.2
unnamed: U2.11, U21.10, U22.3
unnamed: U10.9, U21.3
unnamed: U10.10, U21.8
unnamed: U10.8, U18.2 (D), U29.9
unnamed: U18.12 (D), U20.9 (Zc)
unnamed: U19.2 (D), U20.4 (Za)
unnamed: U19.12 (D), U20.7 (Zb)
unnamed: U21.6, U22.2
SOME_INT_THING: U21.11; also elsewhere on the board
~RST: U18.1 (~R), U18.13 (~R), U19.1 (~R), U19.13 (~R); also elsewhere on the board

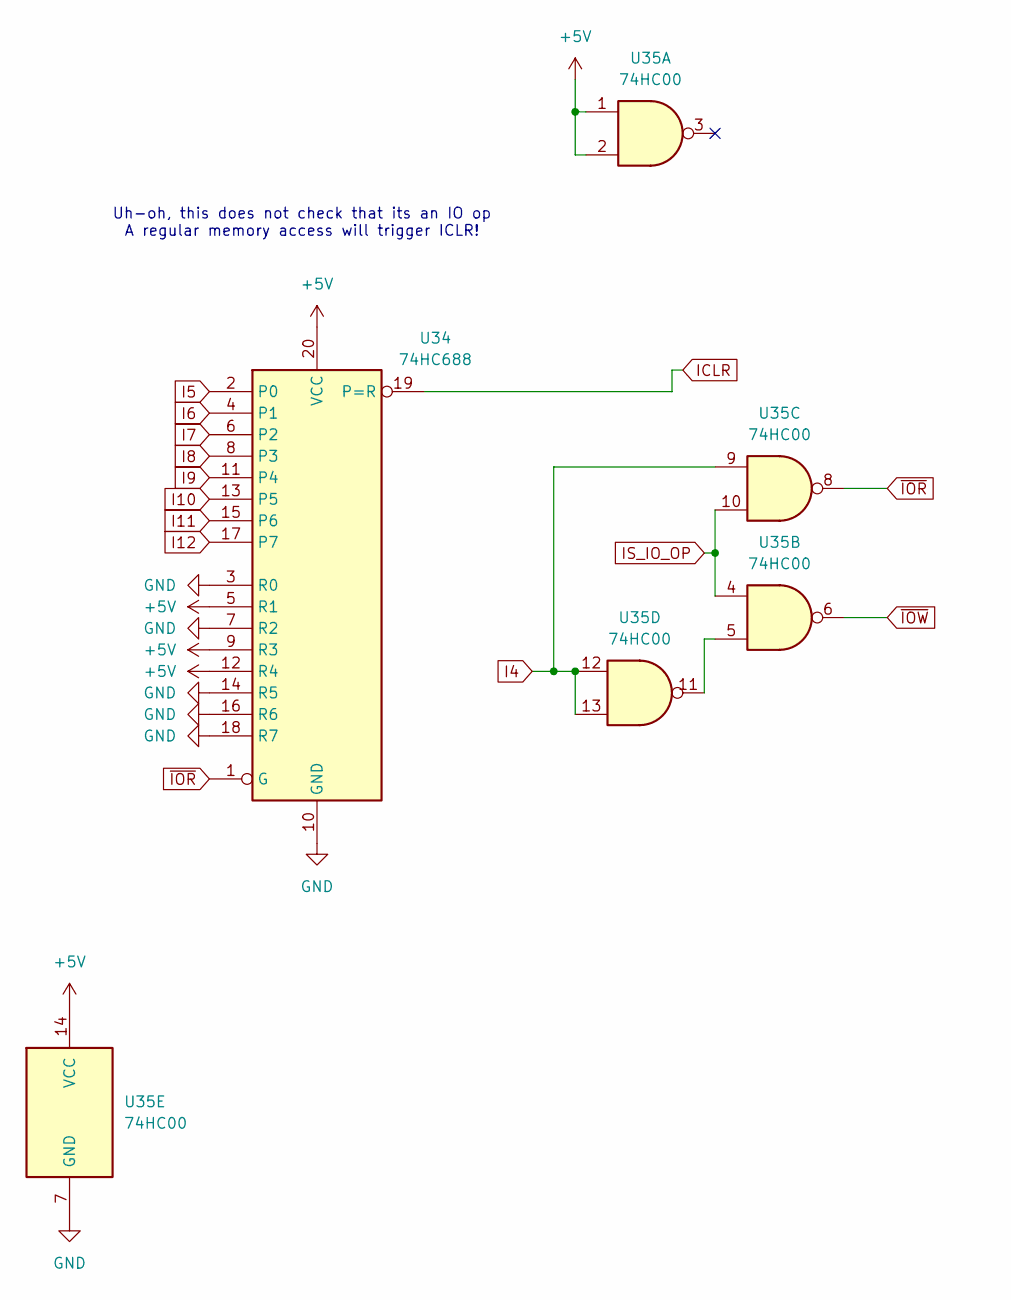
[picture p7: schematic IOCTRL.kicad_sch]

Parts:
U34: 74HC688; SO-20_12.8x7.5mm_P1.27mm
U35: 74HC00; SO-14_3.9x8.65mm_P1.27mm

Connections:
+5V: U34.5 (R1), U34.9 (R3), U34.12 (R4), U34.20 (VCC), U35.1, U35.2, U35.14 (VCC); also elsewhere on the board
GND: U34.3 (R0), U34.7 (R2), U34.10 (GND), U34.14 (R5), U34.16 (R6), U34.18 (R7), U35.7 (GND); also elsewhere on the board
I4: U35.9, U35.12, U35.13; also elsewhere on the board
I5: U34.2 (P0); also elsewhere on the board
I6: U34.4 (P1); also elsewhere on the board
I7: U34.6 (P2); also elsewhere on the board
I8: U34.8 (P3); also elsewhere on the board
I9: U34.11 (P4); also elsewhere on the board
I10: U34.13 (P5); also elsewhere on the board
I11: U34.15 (P6); also elsewhere on the board
I12: U34.17 (P7); also elsewhere on the board
ICLR: U34.19 (P=R); also elsewhere on the board
IS_IO_OP: U35.4, U35.10; also elsewhere on the board
unnamed: U35.5, U35.11
~IOR: U34.1 (G), U35.8; also elsewhere on the board
~IOW: U35.6; also elsewhere on the board

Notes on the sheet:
Uh-oh, this does not check that its an IO op A regular memory access will trigger ICLR!

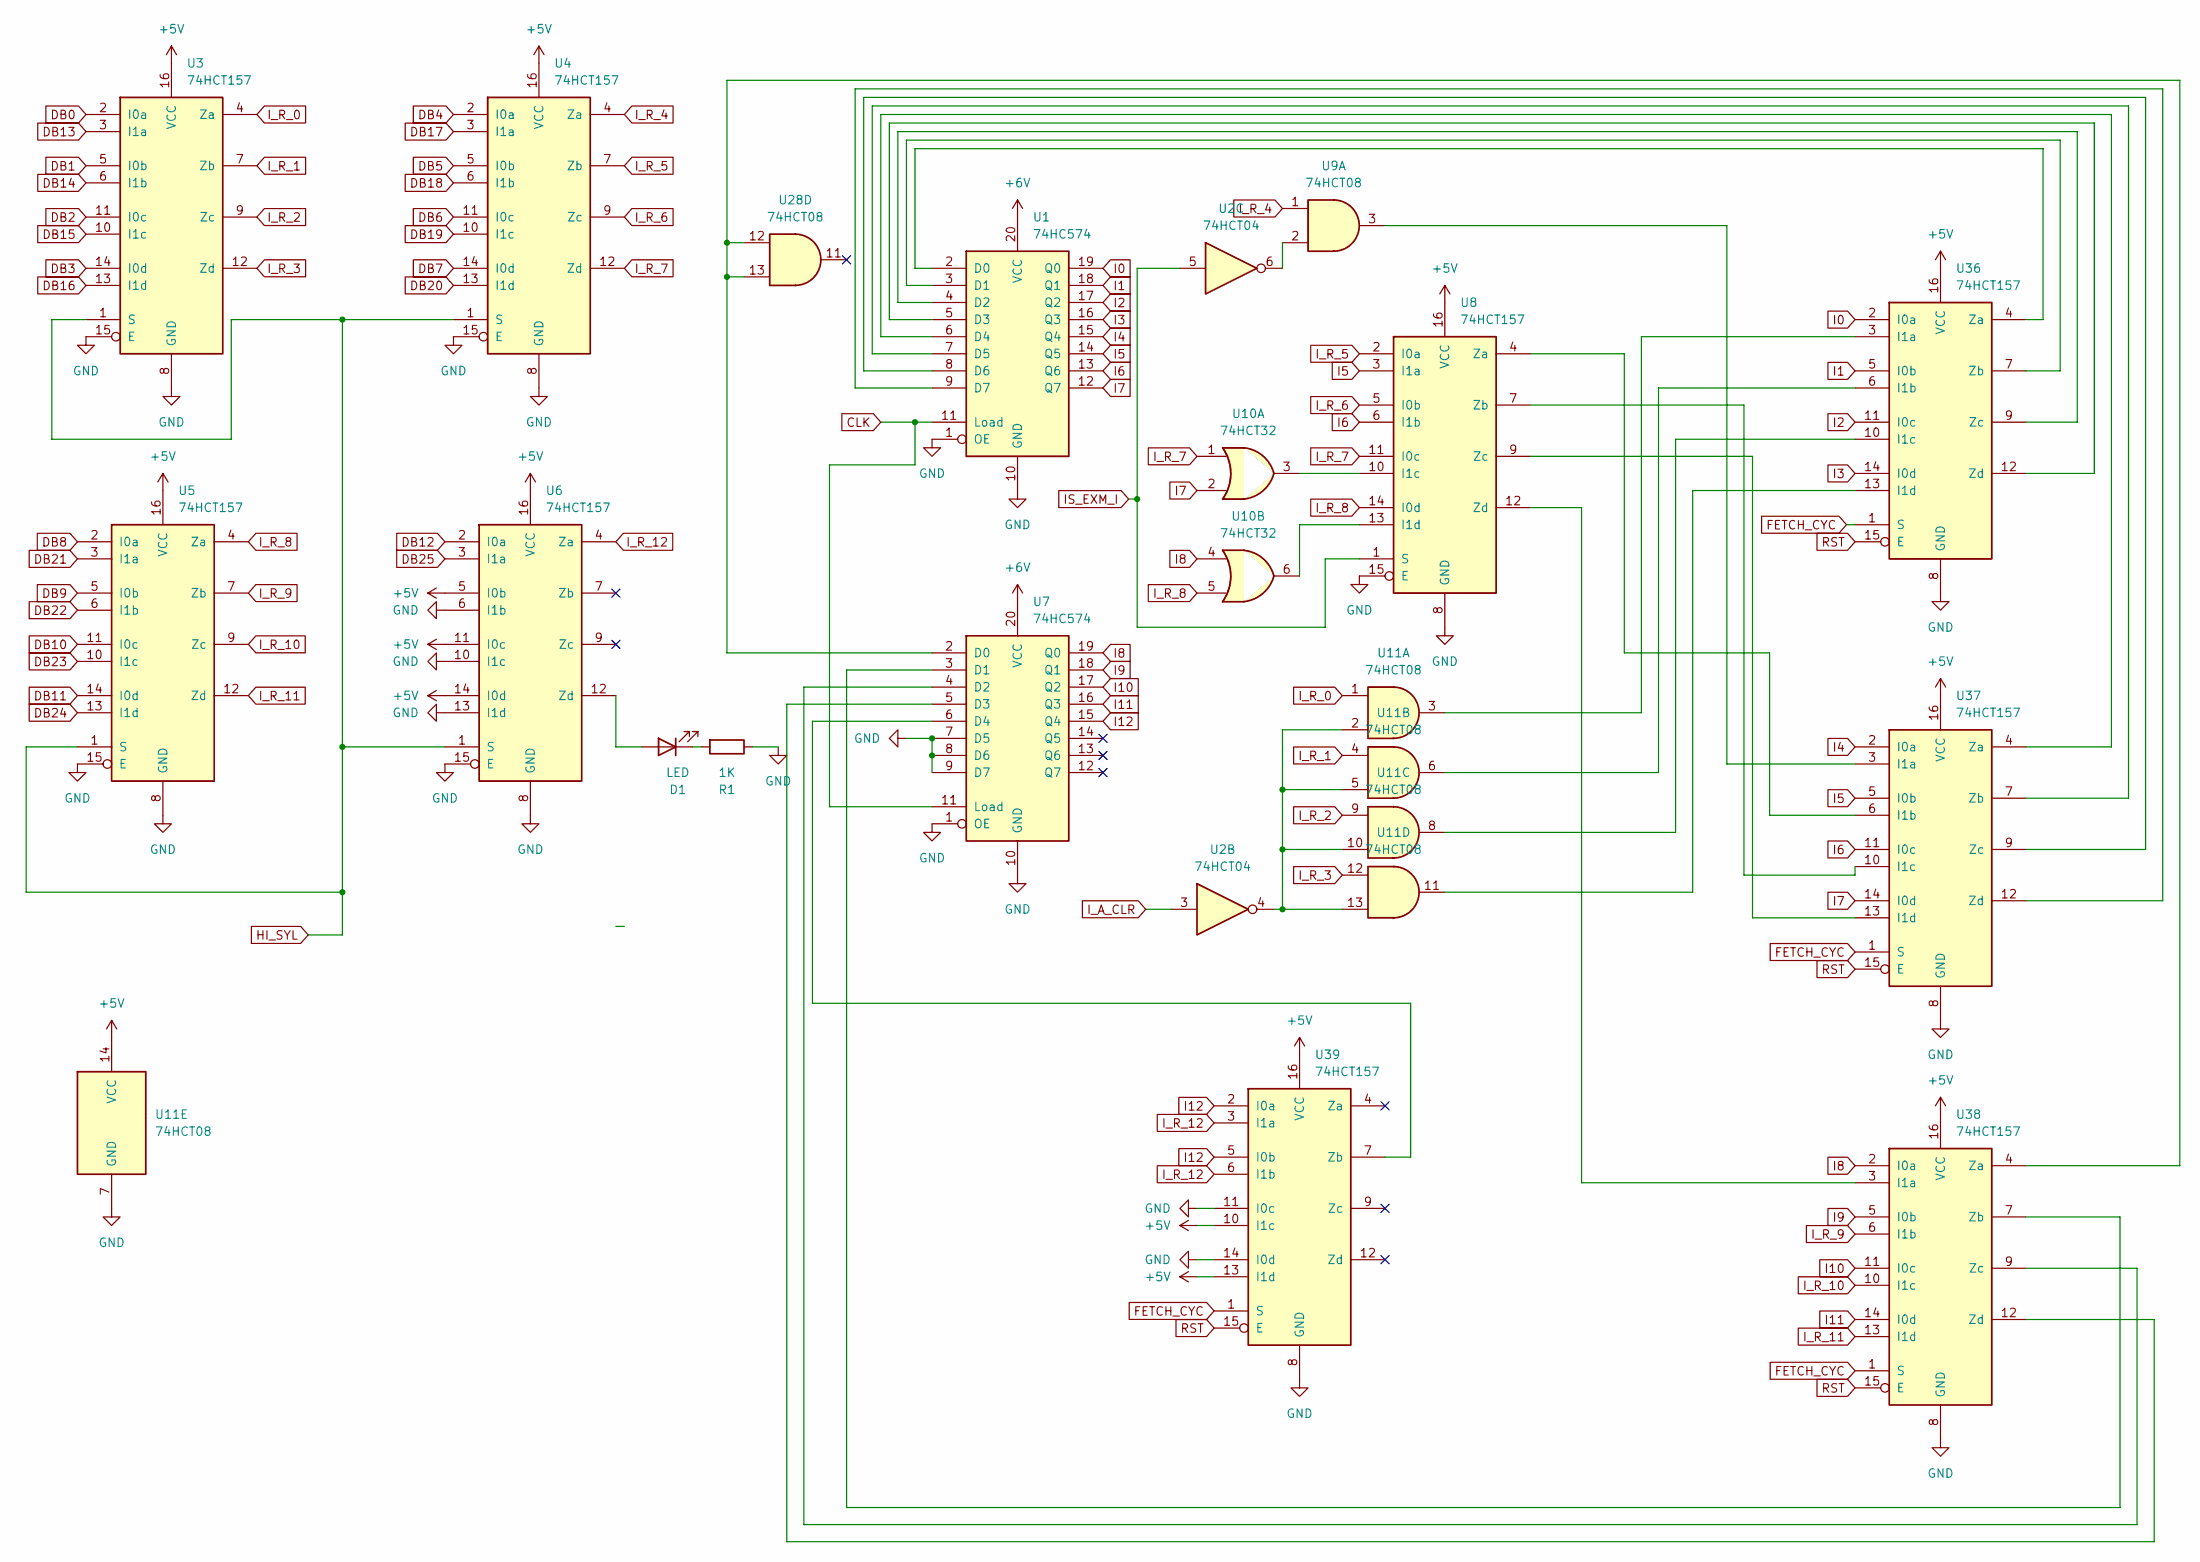
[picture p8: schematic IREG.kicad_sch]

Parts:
D1: LED; LED_1206_3216Metric_Pad1.42x1.75mm_HandSolder
R1: 1K; R_1206_3216Metric_Pad1.30x1.75mm_HandSolder
U1, U7: 74HC574; SO-20_12.8x7.5mm_P1.27mm
U2: 74HCT04; SO-14_3.9x8.65mm_P1.27mm
U3, U4, U5, U6, U8, U36, U37, U38, U39: 74HCT157; SO-16_3.9x9.9mm_P1.27mm
U9, U11, U28: 74HCT08; SO-14_3.9x8.65mm_P1.27mm
U10: 74HCT32; SO-14_3.9x8.65mm_P1.27mm

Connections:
+5V: U3.16 (VCC), U4.16 (VCC), U5.16 (VCC), U6.5 (I0b), U6.11 (I0c), U6.14 (I0d), U6.16 (VCC), U8.16 (VCC), U11.14 (VCC), U36.16 (VCC), U37.16 (VCC), U38.16 (VCC), U39.10 (I1c), U39.13 (I1d), U39.16 (VCC); also elsewhere on the board
+6V: U1.20 (VCC), U7.20 (VCC); also elsewhere on the board
CLK: U1.11 (Load), U7.11 (Load); also elsewhere on the board
DB0: U3.2 (I0a); also elsewhere on the board
DB1: U3.5 (I0b); also elsewhere on the board
DB2: U3.11 (I0c); also elsewhere on the board
DB3: U3.14 (I0d); also elsewhere on the board
DB4: U4.2 (I0a); also elsewhere on the board
DB5: U4.5 (I0b); also elsewhere on the board
DB6: U4.11 (I0c); also elsewhere on the board
DB7: U4.14 (I0d); also elsewhere on the board
DB8: U5.2 (I0a); also elsewhere on the board
DB9: U5.5 (I0b); also elsewhere on the board
DB10: U5.11 (I0c); also elsewhere on the board
DB11: U5.14 (I0d); also elsewhere on the board
DB12: U6.2 (I0a); also elsewhere on the board
DB13: U3.3 (I1a); also elsewhere on the board
DB14: U3.6 (I1b); also elsewhere on the board
DB15: U3.10 (I1c); also elsewhere on the board
DB16: U3.13 (I1d); also elsewhere on the board
DB17: U4.3 (I1a); also elsewhere on the board
DB18: U4.6 (I1b); also elsewhere on the board
DB19: U4.10 (I1c); also elsewhere on the board
DB20: U4.13 (I1d); also elsewhere on the board
DB21: U5.3 (I1a); also elsewhere on the board
DB22: U5.6 (I1b); also elsewhere on the board
DB23: U5.10 (I1c); also elsewhere on the board
DB24: U5.13 (I1d); also elsewhere on the board
DB25: U6.3 (I1a); also elsewhere on the board
FETCH_CYC: U36.1 (S), U37.1 (S), U38.1 (S), U39.1 (S); also elsewhere on the board
GND: R1.1, U1.1 (OE), U1.10 (GND), U3.8 (GND), U3.15 (E), U4.8 (GND), U4.15 (E), U5.8 (GND), U5.15 (E), U6.6 (I1b), U6.8 (GND), U6.10 (I1c), U6.13 (I1d), U6.15 (E), U7.1 (OE), U7.7 (D5), U7.8 (D6), U7.9 (D7), U7.10 (GND), U8.8 (GND), U8.15 (E), U11.7 (GND), U36.8 (GND), U37.8 (GND), U38.8 (GND), U39.8 (GND), U39.11 (I0c), U39.14 (I0d); also elsewhere on the board
HI_SYL: U3.1 (S), U4.1 (S), U5.1 (S), U6.1 (S); also elsewhere on the board
I0: U1.19 (Q0), U36.2 (I0a); also elsewhere on the board
I1: U1.18 (Q1), U36.5 (I0b); also elsewhere on the board
I2: U1.17 (Q2), U36.11 (I0c); also elsewhere on the board
I3: U1.16 (Q3), U36.14 (I0d); also elsewhere on the board
I4: U1.15 (Q4), U37.2 (I0a); also elsewhere on the board
I5: U1.14 (Q5), U8.3 (I1a), U37.5 (I0b); also elsewhere on the board
I6: U1.13 (Q6), U8.6 (I1b), U37.11 (I0c); also elsewhere on the board
I7: U1.12 (Q7), U10.2, U37.14 (I0d); also elsewhere on the board
I8: U7.19 (Q0), U10.4, U38.2 (I0a); also elsewhere on the board
I9: U7.18 (Q1), U38.5 (I0b); also elsewhere on the board
I10: U7.17 (Q2), U38.11 (I0c); also elsewhere on the board
I11: U7.16 (Q3), U38.14 (I0d); also elsewhere on the board
I12: U7.15 (Q4), U39.2 (I0a), U39.5 (I0b); also elsewhere on the board
IS_EXM_I: U2.5, U8.1 (S); also elsewhere on the board
I_A_CLR: U2.3; also elsewhere on the board
I_R_0: U3.4 (Za), U11.1
I_R_1: U3.7 (Zb), U11.4
I_R_2: U3.9 (Zc), U11.9
I_R_3: U3.12 (Zd), U11.12
I_R_4: U4.4 (Za), U9.1; also elsewhere on the board
I_R_5: U4.7 (Zb), U8.2 (I0a); also elsewhere on the board
I_R_6: U4.9 (Zc), U8.5 (I0b); also elsewhere on the board
I_R_7: U4.12 (Zd), U8.11 (I0c), U10.1
I_R_8: U5.4 (Za), U8.14 (I0d), U10.5
I_R_9: U5.7 (Zb), U38.6 (I1b)
I_R_10: U5.9 (Zc), U38.10 (I1c)
I_R_11: U5.12 (Zd), U38.13 (I1d)
I_R_12: U6.4 (Za), U39.3 (I1a), U39.6 (I1b)
unnamed: D1.2 (A), U6.12 (Zd)
unnamed: D1.1 (K), R1.2
unnamed: U1.2 (D0), U36.4 (Za)
unnamed: U1.3 (D1), U36.7 (Zb)
unnamed: U1.4 (D2), U36.9 (Zc)
unnamed: U1.5 (D3), U36.12 (Zd)
unnamed: U1.6 (D4), U37.4 (Za)
unnamed: U1.7 (D5), U37.7 (Zb)
unnamed: U1.8 (D6), U37.9 (Zc)
unnamed: U1.9 (D7), U37.12 (Zd)
unnamed: U2.6, U9.2
unnamed: U8.10 (I1c), U10.3
unnamed: U8.13 (I1d), U10.6
unnamed: U2.4, U11.2, U11.5, U11.10, U11.13
unnamed: U11.3, U36.3 (I1a)
unnamed: U11.6, U36.6 (I1b)
unnamed: U11.8, U36.10 (I1c)
unnamed: U11.11, U36.13 (I1d)
unnamed: U9.3, U37.3 (I1a)
unnamed: U8.4 (Za), U37.6 (I1b)
unnamed: U8.7 (Zb), U37.10 (I1c)
unnamed: U8.9 (Zc), U37.13 (I1d)
unnamed: U8.12 (Zd), U38.3 (I1a)
unnamed: U7.2 (D0), U28.12, U28.13, U38.4 (Za)
unnamed: U7.3 (D1), U38.7 (Zb)
unnamed: U7.4 (D2), U38.9 (Zc)
unnamed: U7.5 (D3), U38.12 (Zd)
unnamed: U7.6 (D4), U39.7 (Zb)
RST: U36.15 (E), U37.15 (E), U38.15 (E), U39.15 (E); also elsewhere on the board

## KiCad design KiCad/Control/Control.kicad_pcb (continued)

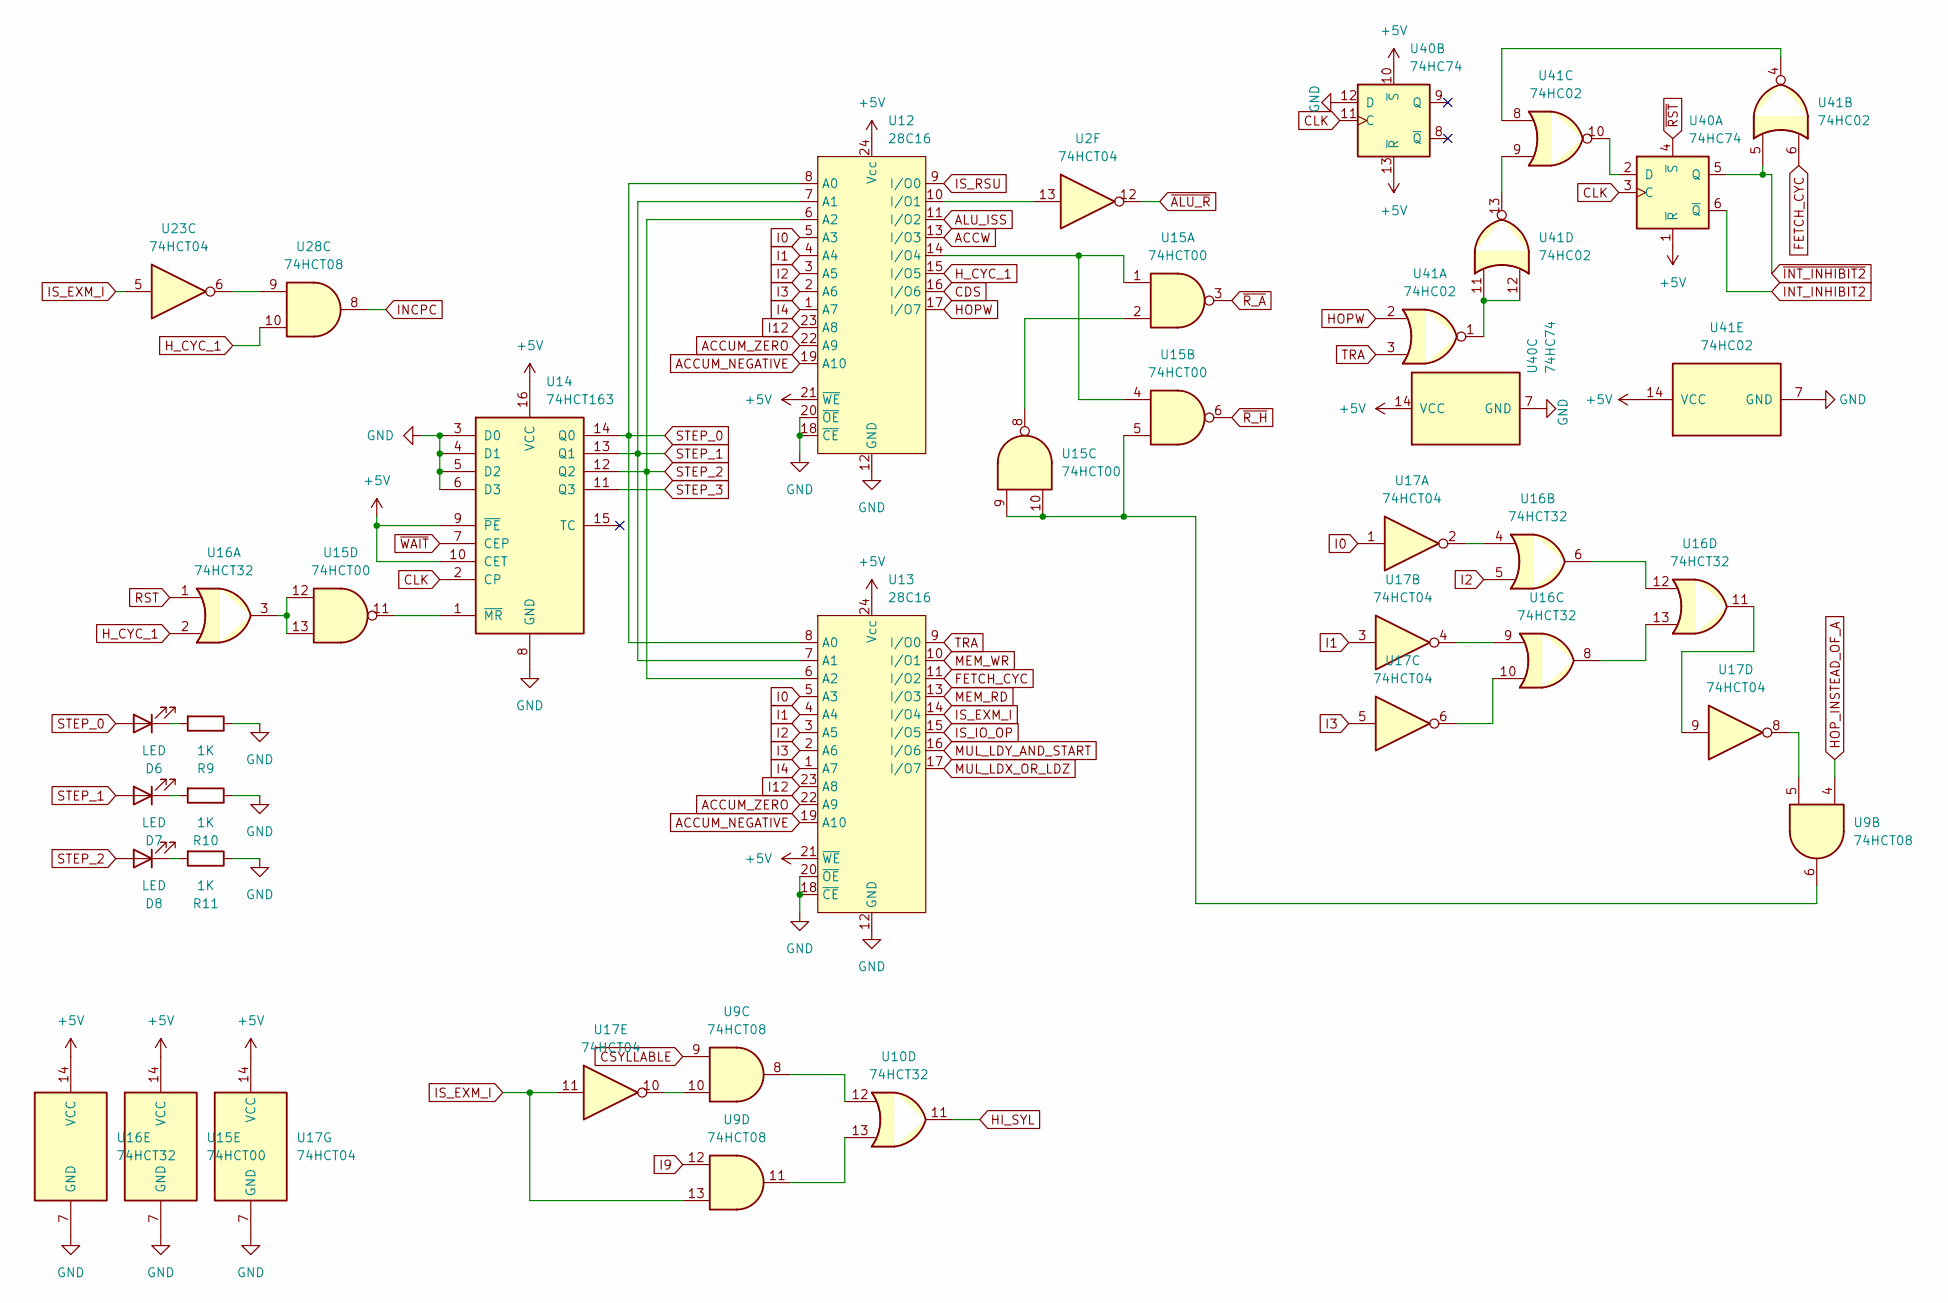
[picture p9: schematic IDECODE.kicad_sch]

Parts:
D6, D7, D8: LED; LED_1206_3216Metric_Pad1.42x1.75mm_HandSolder
R9, R10, R11: 1K; R_1206_3216Metric_Pad1.30x1.75mm_HandSolder
U2, U17, U23: 74HCT04; SO-14_3.9x8.65mm_P1.27mm
U9, U28: 74HCT08; SO-14_3.9x8.65mm_P1.27mm
U10, U16: 74HCT32; SO-14_3.9x8.65mm_P1.27mm
U12, U13: 28C16; DIP-24_W15.24mm_Socket
U14: 74HCT163; DIP-16_W7.62mm
U15: 74HCT00; SO-14_3.9x8.65mm_P1.27mm
U40: 74HC74; SO-14_3.9x8.65mm_P1.27mm
U41: 74HC02; SO-14_3.9x8.65mm_P1.27mm

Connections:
+5V: U12.21 (~WE), U12.24 (Vcc), U13.21 (~WE), U13.24 (Vcc), U14.9 (~PE), U14.10 (CET), U14.16 (VCC), U15.14 (VCC), U16.14 (VCC), U17.14 (VCC), U40.1 (~R), U40.10 (~S), U40.13 (~R), U40.14 (VCC), U41.14 (VCC); also elsewhere on the board
ACCUM_NEGATIVE: U12.19 (A10), U13.19 (A10); also elsewhere on the board
ACCUM_ZERO: U12.22 (A9), U13.22 (A9); also elsewhere on the board
ACCW: U12.13 (I/O3); also elsewhere on the board
ALU_ISS: U12.11 (I/O2); also elsewhere on the board
CDS: U12.16 (I/O6); also elsewhere on the board
CLK: U14.2 (CP), U40.3 (C), U40.11 (C); also elsewhere on the board
CSYLLABLE: U9.9; also elsewhere on the board
FETCH_CYC: U13.11 (I/O2), U41.6; also elsewhere on the board
GND: R9.1, R10.1, R11.1, U12.12 (GND), U12.18 (~CE), U12.20 (~OE), U13.12 (GND), U13.18 (~CE), U13.20 (~OE), U14.3 (D0), U14.4 (D1), U14.5 (D2), U14.6 (D3), U14.8 (GND), U15.7 (GND), U16.7 (GND), U17.7 (GND), U40.7 (GND), U40.12 (D), U41.7 (GND); also elsewhere on the board
HI_SYL: U10.11; also elsewhere on the board
HOPW: U12.17 (I/O7), U41.2; also elsewhere on the board
HOP_INSTEAD_OF_A: U9.4; also elsewhere on the board
H_CYC_1: U12.15 (I/O5), U16.2, U28.10; also elsewhere on the board
I0: U12.5 (A3), U13.5 (A3), U17.1; also elsewhere on the board
I1: U12.4 (A4), U13.4 (A4), U17.3; also elsewhere on the board
I2: U12.3 (A5), U13.3 (A5), U16.5; also elsewhere on the board
I3: U12.2 (A6), U13.2 (A6), U17.5; also elsewhere on the board
I4: U12.1 (A7), U13.1 (A7); also elsewhere on the board
I9: U9.12; also elsewhere on the board
I12: U12.23 (A8), U13.23 (A8); also elsewhere on the board
INCPC: U28.8; also elsewhere on the board
INT_INHIBIT2: U40.6 (~Q); also elsewhere on the board
IS_EXM_I: U9.13, U13.14 (I/O4), U17.11, U23.5; also elsewhere on the board
IS_IO_OP: U13.15 (I/O5); also elsewhere on the board
IS_RSU: U12.9 (I/O0); also elsewhere on the board
MEM_RD: U13.13 (I/O3); also elsewhere on the board
MEM_WR: U13.10 (I/O1); also elsewhere on the board
MUL_LDX_OR_LDZ: U13.17 (I/O7); also elsewhere on the board
MUL_LDY_AND_START: U13.16 (I/O6); also elsewhere on the board
unnamed: D6.1 (K), R9.2
unnamed: D7.1 (K), R10.2
unnamed: D8.1 (K), R11.2
unnamed: U9.8, U10.12
unnamed: U9.11, U10.13
unnamed: U2.13, U12.10 (I/O1)
unnamed: U12.14 (I/O4), U15.1, U15.4
unnamed: U14.1 (~MR), U15.11
unnamed: U15.2, U15.8
unnamed: U9.6, U15.5, U15.9, U15.10
unnamed: U15.12, U15.13, U16.3
unnamed: U16.4, U17.2
unnamed: U16.9, U17.4
unnamed: U16.10, U17.6
unnamed: U16.11, U17.9
unnamed: U16.6, U16.12
unnamed: U16.8, U16.13
unnamed: U9.5, U17.8
unnamed: U9.10, U17.10
unnamed: U23.6, U28.9
unnamed: U40.2 (D), U41.10
unnamed: U41.1, U41.11, U41.12
unnamed: U41.4, U41.8
unnamed: U41.9, U41.13
RST: U16.1; also elsewhere on the board
STEP_0: D6.2 (A), U12.8 (A0), U13.8 (A0), U14.14 (Q0)
STEP_1: D7.2 (A), U12.7 (A1), U13.7 (A1), U14.13 (Q1)
STEP_2: D8.2 (A), U12.6 (A2), U13.6 (A2), U14.12 (Q2); also elsewhere on the board
STEP_3: U14.11 (Q3)
TRA: U13.9 (I/O0), U41.3; also elsewhere on the board
~ALU_R: U2.12; also elsewhere on the board
~INT_INHIBIT2: U40.5 (Q), U41.5
~RST: U40.4 (~S); also elsewhere on the board
~R_A: U15.3; also elsewhere on the board
~R_H: U15.6; also elsewhere on the board
~WAIT: U14.7 (CEP); also elsewhere on the board

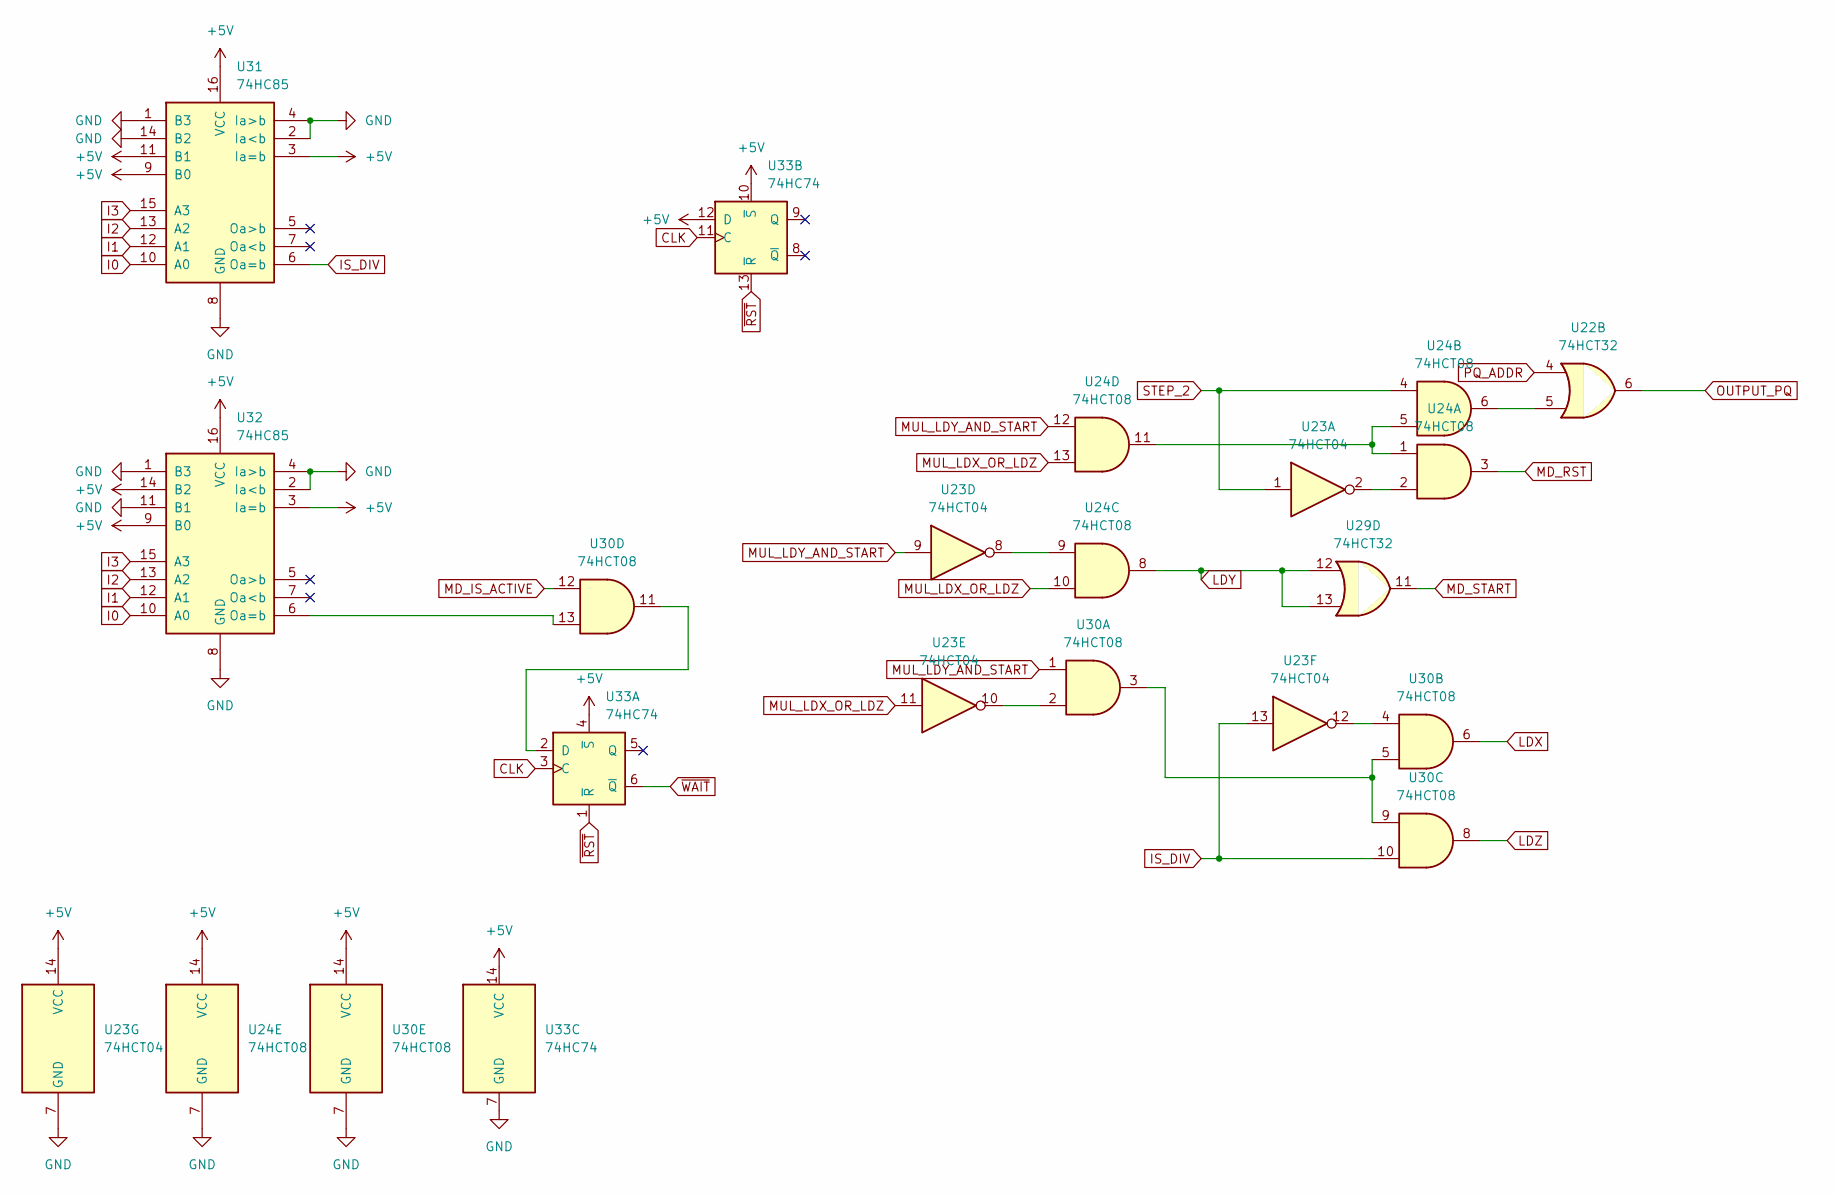
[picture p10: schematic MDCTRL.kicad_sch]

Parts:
U22, U29: 74HCT32; SO-14_3.9x8.65mm_P1.27mm
U23: 74HCT04; SO-14_3.9x8.65mm_P1.27mm
U24, U30: 74HCT08; SO-14_3.9x8.65mm_P1.27mm
U31, U32: 74HC85; DIP-16_W7.62mm
U33: 74HC74; SO-14_3.9x8.65mm_P1.27mm

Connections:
+5V: U23.14 (VCC), U24.14 (VCC), U30.14 (VCC), U31.3 (Ia=b), U31.9 (B0), U31.11 (B1), U31.16 (VCC), U32.3 (Ia=b), U32.9 (B0), U32.14 (B2), U32.16 (VCC), U33.4 (~S), U33.10 (~S), U33.12 (D), U33.14 (VCC); also elsewhere on the board
CLK: U33.3 (C), U33.11 (C); also elsewhere on the board
GND: U23.7 (GND), U24.7 (GND), U30.7 (GND), U31.1 (B3), U31.2 (Ia<b), U31.4 (Ia>b), U31.8 (GND), U31.14 (B2), U32.1 (B3), U32.2 (Ia<b), U32.4 (Ia>b), U32.8 (GND), U32.11 (B1), U33.7 (GND); also elsewhere on the board
I0: U31.10 (A0), U32.10 (A0); also elsewhere on the board
I1: U31.12 (A1), U32.12 (A1); also elsewhere on the board
I2: U31.13 (A2), U32.13 (A2); also elsewhere on the board
I3: U31.15 (A3), U32.15 (A3); also elsewhere on the board
IS_DIV: U23.13, U30.10, U31.6 (Oa=b); also elsewhere on the board
LDX: U30.6; also elsewhere on the board
LDY: U24.8, U29.12, U29.13; also elsewhere on the board
LDZ: U30.8; also elsewhere on the board
MD_IS_ACTIVE: U30.12; also elsewhere on the board
MD_RST: U24.3; also elsewhere on the board
MD_START: U29.11; also elsewhere on the board
MUL_LDX_OR_LDZ: U23.11, U24.10, U24.13; also elsewhere on the board
MUL_LDY_AND_START: U23.9, U24.12, U30.1; also elsewhere on the board
unnamed: U22.5, U24.6
unnamed: U23.2, U24.2
unnamed: U23.8, U24.9
unnamed: U23.10, U30.2
unnamed: U23.12, U30.4
unnamed: U24.1, U24.5, U24.11
unnamed: U30.3, U30.5, U30.9
unnamed: U30.13, U32.6 (Oa=b)
unnamed: U30.11, U33.2 (D)
OUTPUT_PQ: U22.6; also elsewhere on the board
PQ_ADDR: U22.4; also elsewhere on the board
STEP_2: U23.1, U24.4; also elsewhere on the board
~RST: U33.1 (~R), U33.13 (~R); also elsewhere on the board
~WAIT: U33.6 (~Q); also elsewhere on the board

Board: 4 copper layers, 81 parts (0 on the bottom side), 202 nets, no tracks yet.

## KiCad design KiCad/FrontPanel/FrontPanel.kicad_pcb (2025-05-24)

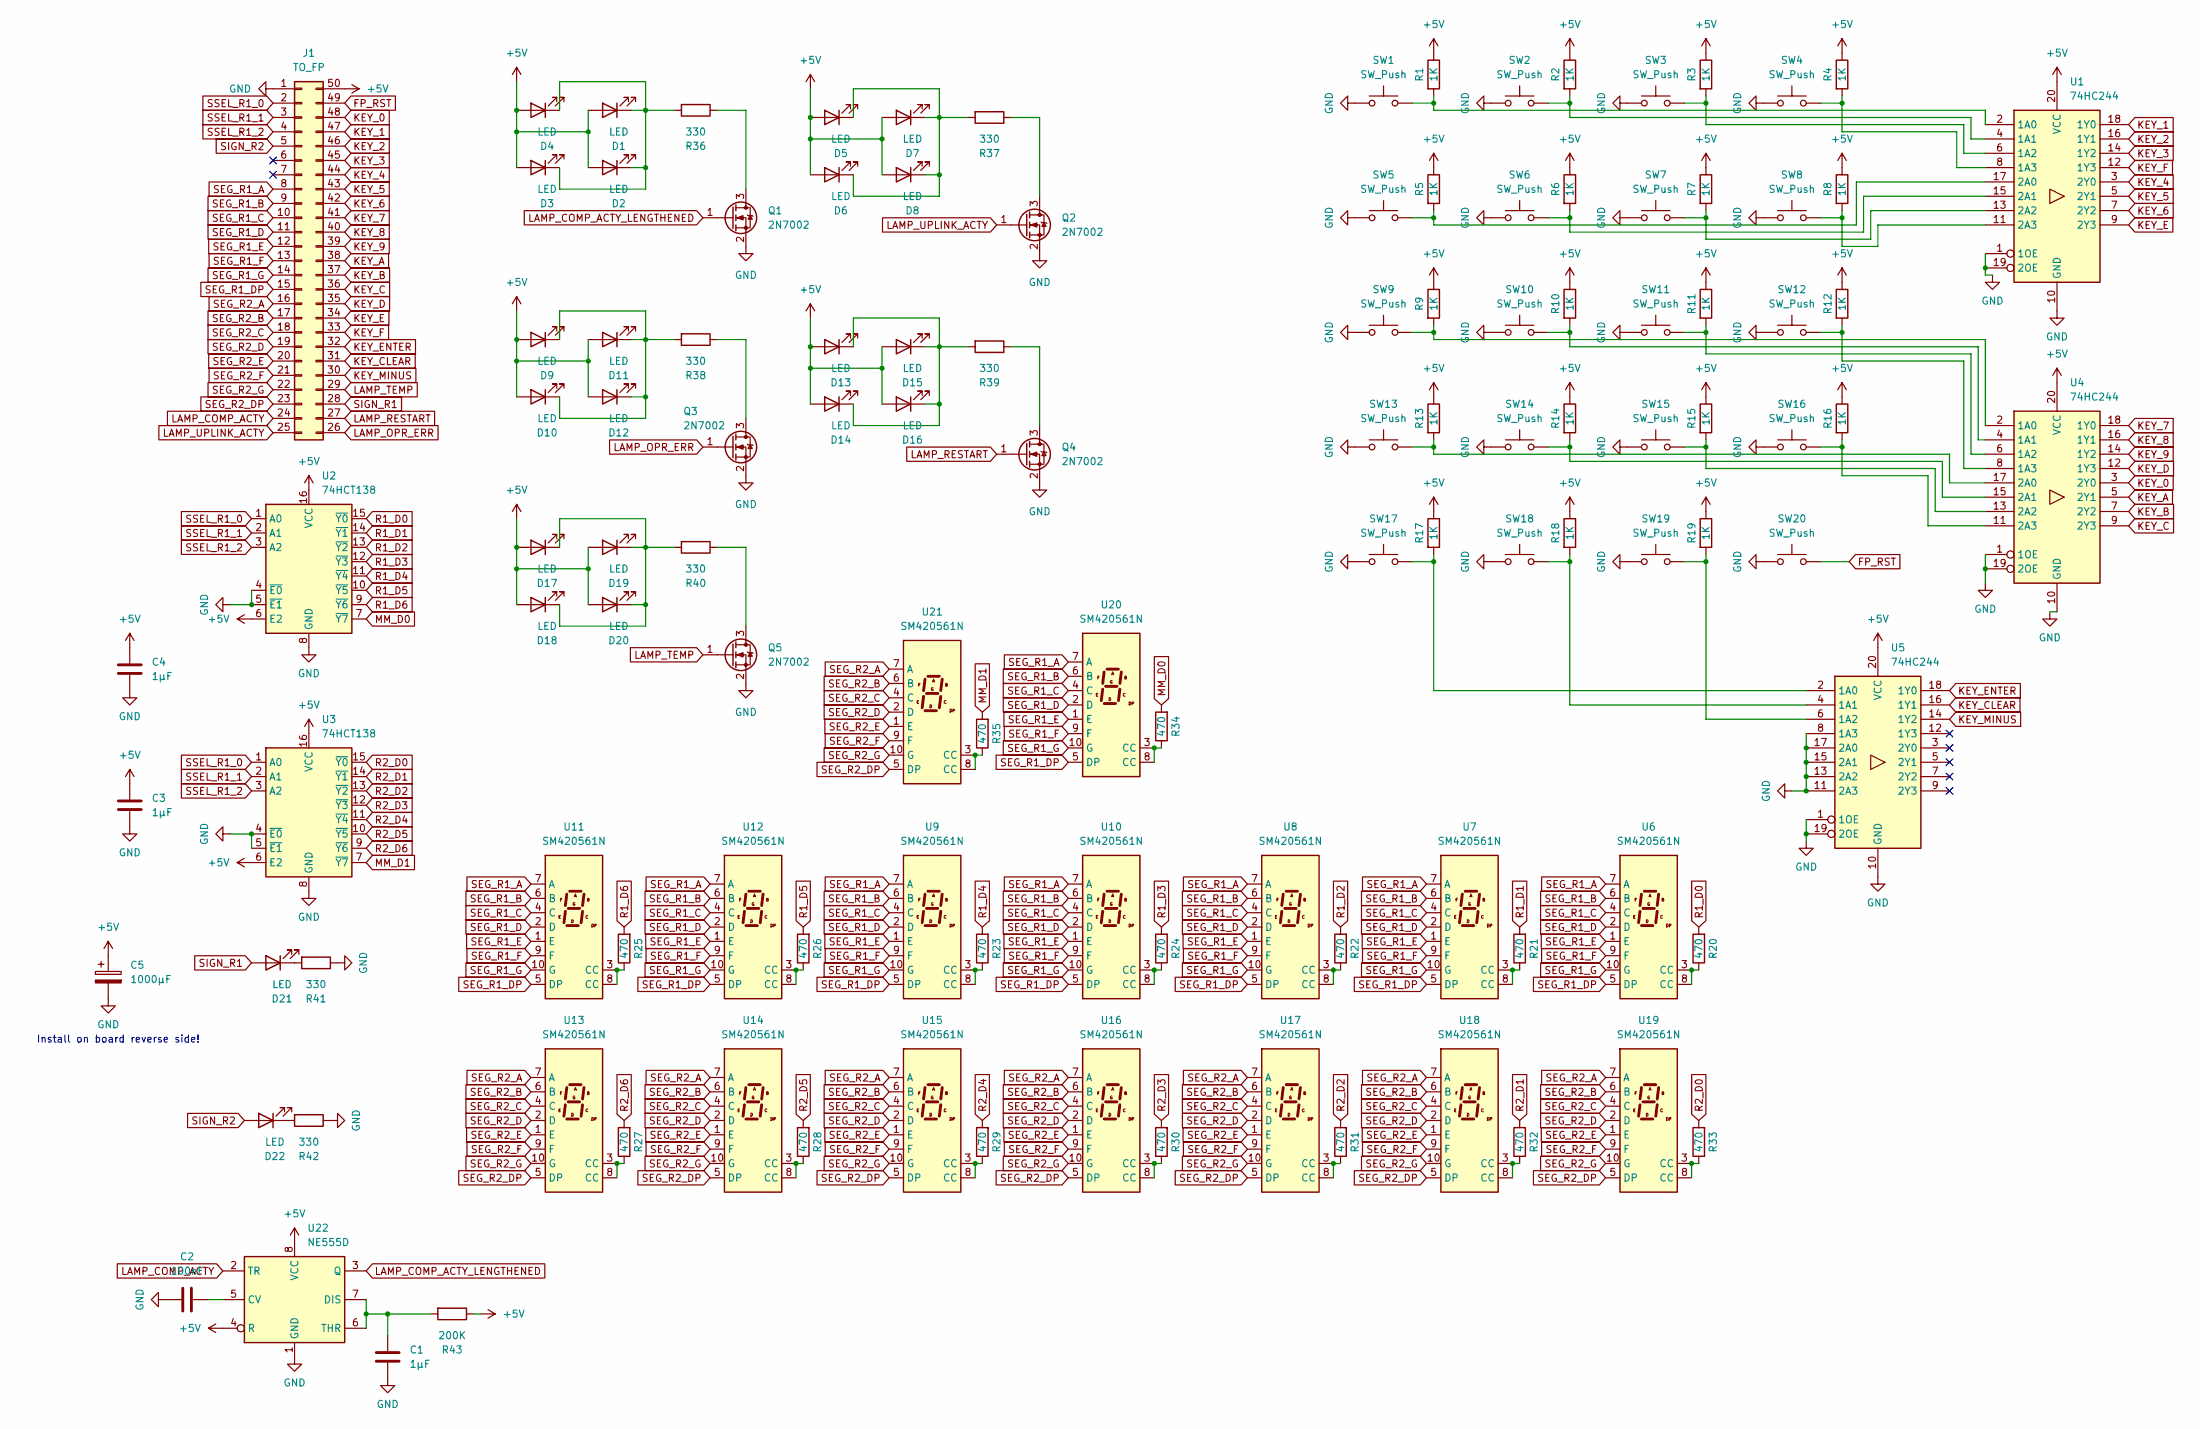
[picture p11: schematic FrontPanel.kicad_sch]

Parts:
C1, C3, C4: 1µF; C_0805_2012Metric_Pad1.18x1.45mm_HandSolder
C2: 100nF; C_0805_2012Metric_Pad1.18x1.45mm_HandSolder
C5: 1000µF; CP_Radial_D6.3mm_P2.50mm
D1, D2, D3, D4, D5, D6, D7, D8, D9, D10, D11, D12, D13, D14, D15, D16, D17, D18, D19, D20: LED; LED_1206_3216Metric_Pad1.42x1.75mm_HandSolder
D21, D22: LED; LED_D5.0mm
J1: TO_FP; PinHeader_2x25_P2.54mm_Vertical
Q1, Q2, Q3, Q4, Q5: 2N7002; SOT-23
R1, R2, R3, R4, R5, R6, R7, R8, R9, R10, R11, R12, R13, R14, R15, R16, R17, R18, R19: 1K; R_1206_3216Metric_Pad1.30x1.75mm_HandSolder
R20, R21, R22, R23, R24, R25, R26, R27, R28, R29, R30, R31, R32, R33, R34, R35: 470; R_1206_3216Metric_Pad1.30x1.75mm_HandSolder
R36, R37, R38, R39, R40, R41, R42: 330; R_1206_3216Metric_Pad1.30x1.75mm_HandSolder
R43: 200K; R_1206_3216Metric_Pad1.30x1.75mm_HandSolder
SW1, SW2, SW3, SW4, SW5, SW6, SW7, SW8, SW9, SW10, SW11, SW12, SW13, SW14, SW15, SW16, SW17, SW18, SW19, SW20: SW_Push; SW_Cherry_MX_1.00u_PCB
U1, U4, U5: 74HC244; SO-20_12.8x7.5mm_P1.27mm
U2, U3: 74HCT138; SO-16_3.9x9.9mm_P1.27mm
U6, U7, U8, U9, U10, U11, U12, U13, U14, U15, U16, U17, U18, U19, U20, U21: SM420561N; 7SegmentLED_LTS6760_LTS6780
U22: NE555D; SOIC-8_3.9x4.9mm_P1.27mm

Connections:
+5V: C3.2, C4.2, C5.1, D1.2 (A), D2.2 (A), D3.2 (A), D4.2 (A), D5.2 (A), D6.2 (A), D7.2 (A), D8.2 (A), D9.2 (A), D10.2 (A), D11.2 (A), D12.2 (A), D13.2 (A), D14.2 (A), D15.2 (A), D16.2 (A), D17.2 (A), D18.2 (A), D19.2 (A), D20.2 (A), J1.50, R1.1, R2.1, R3.1, R4.1, R5.1, R6.1, R7.1, R8.1, R9.1, R10.1, R11.1, R12.1, R13.1, R14.1, R15.1, R16.1, R17.1, R18.1, R19.1, R43.1, U1.20 (VCC), U2.6 (E2), U2.16 (VCC), U3.6 (E2), U3.16 (VCC), U4.20 (VCC), U5.20 (VCC), U22.4 (R), U22.8 (VCC)
FP_RST: J1.49, SW20.2
GND: C1.1, C2.2, C3.1, C4.1, C5.2, J1.1, Q1.2 (S), Q2.2 (S), Q3.2 (S), Q4.2 (S), Q5.2 (S), R41.1, R42.1, SW1.1, SW2.1, SW3.1, SW4.1, SW5.1, SW6.1, SW7.1, SW8.1, SW9.1, SW10.1, SW11.1, SW12.1, SW13.1, SW14.1, SW15.1, SW16.1, SW17.1, SW18.1, SW19.1, SW20.1, U1.1 (1OE), U1.10 (GND), U1.19 (2OE), U2.4 (~E0), U2.5 (~E1), U2.8 (GND), U3.4 (~E0), U3.5 (~E1), U3.8 (GND), U4.1 (1OE), U4.10 (GND), U4.19 (2OE), U5.1 (1OE), U5.8 (1A3), U5.10 (GND), U5.11 (2A3), U5.13 (2A2), U5.15 (2A1), U5.17 (2A0), U5.19 (2OE), U22.1 (GND)
KEY_0: J1.48, U4.3 (2Y0)
KEY_1: J1.47, U1.18 (1Y0)
KEY_2: J1.46, U1.16 (1Y1)
KEY_3: J1.45, U1.14 (1Y2)
KEY_4: J1.44, U1.3 (2Y0)
KEY_5: J1.43, U1.5 (2Y1)
KEY_6: J1.42, U1.7 (2Y2)
KEY_7: J1.41, U4.18 (1Y0)
KEY_8: J1.40, U4.16 (1Y1)
KEY_9: J1.39, U4.14 (1Y2)
KEY_A: J1.38, U4.5 (2Y1)
KEY_B: J1.37, U4.7 (2Y2)
KEY_C: J1.36, U4.9 (2Y3)
KEY_CLEAR: J1.31, U5.16 (1Y1)
KEY_D: J1.35, U4.12 (1Y3)
KEY_E: J1.34, U1.9 (2Y3)
KEY_ENTER: J1.32, U5.18 (1Y0)
KEY_F: J1.33, U1.12 (1Y3)
KEY_MINUS: J1.30, U5.14 (1Y2)
LAMP_COMP_ACTY: J1.24, U22.2 (TR)
LAMP_COMP_ACTY_LENGTHENED: Q1.1 (G), U22.3 (Q)
LAMP_OPR_ERR: J1.26, Q3.1 (G)
LAMP_RESTART: J1.27, Q4.1 (G)
LAMP_TEMP: J1.29, Q5.1 (G)
LAMP_UPLINK_ACTY: J1.25, Q2.1 (G)
MM_D0: R34.2, U2.7 (~Y7)
MM_D1: R35.2, U3.7 (~Y7)
unnamed: D1.1 (K), D2.1 (K), D3.1 (K), D4.1 (K), R36.2
unnamed: D5.1 (K), D6.1 (K), D7.1 (K), D8.1 (K), R37.2
unnamed: D9.1 (K), D10.1 (K), D11.1 (K), D12.1 (K), R38.2
unnamed: D13.1 (K), D14.1 (K), D15.1 (K), D16.1 (K), R39.2
unnamed: D17.1 (K), D18.1 (K), D19.1 (K), D20.1 (K), R40.2
unnamed: D21.1 (K), R41.2
unnamed: D22.1 (K), R42.2
unnamed: Q1.3 (D), R36.1
unnamed: Q2.3 (D), R37.1
unnamed: Q3.3 (D), R38.1
unnamed: Q4.3 (D), R39.1
unnamed: Q5.3 (D), R40.1
unnamed: R20.1, U6.3 (CC), U6.8 (CC)
unnamed: R21.1, U7.3 (CC), U7.8 (CC)
unnamed: R22.1, U8.3 (CC), U8.8 (CC)
unnamed: R23.1, U9.3 (CC), U9.8 (CC)
unnamed: R24.1, U10.3 (CC), U10.8 (CC)
unnamed: R25.1, U11.3 (CC), U11.8 (CC)
unnamed: R26.1, U12.3 (CC), U12.8 (CC)
unnamed: R27.1, U13.3 (CC), U13.8 (CC)
unnamed: R28.1, U14.3 (CC), U14.8 (CC)
unnamed: R29.1, U15.3 (CC), U15.8 (CC)
unnamed: R30.1, U16.3 (CC), U16.8 (CC)
unnamed: R31.1, U17.3 (CC), U17.8 (CC)
unnamed: R32.1, U18.3 (CC), U18.8 (CC)
unnamed: R33.1, U19.3 (CC), U19.8 (CC)
unnamed: R34.1, U20.3 (CC), U20.8 (CC)
unnamed: R35.1, U21.3 (CC), U21.8 (CC)
unnamed: R1.2, SW1.2, U1.2 (1A0)
unnamed: R2.2, SW2.2, U1.4 (1A1)
unnamed: R3.2, SW3.2, U1.6 (1A2)
unnamed: R4.2, SW4.2, U1.8 (1A3)
unnamed: R5.2, SW5.2, U1.17 (2A0)
unnamed: R6.2, SW6.2, U1.15 (2A1)
unnamed: R7.2, SW7.2, U1.13 (2A2)
unnamed: R8.2, SW8.2, U1.11 (2A3)
unnamed: R9.2, SW9.2, U4.2 (1A0)
unnamed: R10.2, SW10.2, U4.4 (1A1)
unnamed: R11.2, SW11.2, U4.6 (1A2)
unnamed: R12.2, SW12.2, U4.8 (1A3)
unnamed: R13.2, SW13.2, U4.17 (2A0)
unnamed: R14.2, SW14.2, U4.15 (2A1)
unnamed: R15.2, SW15.2, U4.13 (2A2)
unnamed: R16.2, SW16.2, U4.11 (2A3)
unnamed: R17.2, SW17.2, U5.2 (1A0)
unnamed: R18.2, SW18.2, U5.4 (1A1)
unnamed: R19.2, SW19.2, U5.6 (1A2)
unnamed: C2.1, U22.5 (CV)
unnamed: C1.2, R43.2, U22.6 (THR), U22.7 (DIS)
R1_D0: R20.2, U2.15 (~Y0)
R1_D1: R21.2, U2.14 (~Y1)
R1_D2: R22.2, U2.13 (~Y2)
R1_D3: R24.2, U2.12 (~Y3)
R1_D4: R23.2, U2.11 (~Y4)
R1_D5: R26.2, U2.10 (~Y5)
R1_D6: R25.2, U2.9 (~Y6)
R2_D0: R33.2, U3.15 (~Y0)
R2_D1: R32.2, U3.14 (~Y1)
R2_D2: R31.2, U3.13 (~Y2)
R2_D3: R30.2, U3.12 (~Y3)
R2_D4: R29.2, U3.11 (~Y4)
R2_D5: R28.2, U3.10 (~Y5)
R2_D6: R27.2, U3.9 (~Y6)
SEG_R1_A: J1.8, U6.7 (A), U7.7 (A), U8.7 (A), U9.7 (A), U10.7 (A), U11.7 (A), U12.7 (A), U20.7 (A)
SEG_R1_B: J1.9, U6.6 (B), U7.6 (B), U8.6 (B), U9.6 (B), U10.6 (B), U11.6 (B), U12.6 (B), U20.6 (B)
SEG_R1_C: J1.10, U6.4 (C), U7.4 (C), U8.4 (C), U9.4 (C), U10.4 (C), U11.4 (C), U12.4 (C), U20.4 (C)
SEG_R1_D: J1.11, U6.2 (D), U7.2 (D), U8.2 (D), U9.2 (D), U10.2 (D), U11.2 (D), U12.2 (D), U20.2 (D)
SEG_R1_DP: J1.15, U6.5 (DP), U7.5 (DP), U8.5 (DP), U9.5 (DP), U10.5 (DP), U11.5 (DP), U12.5 (DP), U20.5 (DP)
SEG_R1_E: J1.12, U6.1 (E), U7.1 (E), U8.1 (E), U9.1 (E), U10.1 (E), U11.1 (E), U12.1 (E), U20.1 (E)
SEG_R1_F: J1.13, U6.9 (F), U7.9 (F), U8.9 (F), U9.9 (F), U10.9 (F), U11.9 (F), U12.9 (F), U20.9 (F)
SEG_R1_G: J1.14, U6.10 (G), U7.10 (G), U8.10 (G), U9.10 (G), U10.10 (G), U11.10 (G), U12.10 (G), U20.10 (G)
SEG_R2_A: J1.16, U13.7 (A), U14.7 (A), U15.7 (A), U16.7 (A), U17.7 (A), U18.7 (A), U19.7 (A), U21.7 (A)
SEG_R2_B: J1.17, U13.6 (B), U14.6 (B), U15.6 (B), U16.6 (B), U17.6 (B), U18.6 (B), U19.6 (B), U21.6 (B)
SEG_R2_C: J1.18, U13.4 (C), U14.4 (C), U15.4 (C), U16.4 (C), U17.4 (C), U18.4 (C), U19.4 (C), U21.4 (C)
SEG_R2_D: J1.19, U13.2 (D), U14.2 (D), U15.2 (D), U16.2 (D), U17.2 (D), U18.2 (D), U19.2 (D), U21.2 (D)
SEG_R2_DP: J1.23, U13.5 (DP), U14.5 (DP), U15.5 (DP), U16.5 (DP), U17.5 (DP), U18.5 (DP), U19.5 (DP), U21.5 (DP)
SEG_R2_E: J1.20, U13.1 (E), U14.1 (E), U15.1 (E), U16.1 (E), U17.1 (E), U18.1 (E), U19.1 (E), U21.1 (E)
SEG_R2_F: J1.21, U13.9 (F), U14.9 (F), U15.9 (F), U16.9 (F), U17.9 (F), U18.9 (F), U19.9 (F), U21.9 (F)
SEG_R2_G: J1.22, U13.10 (G), U14.10 (G), U15.10 (G), U16.10 (G), U17.10 (G), U18.10 (G), U19.10 (G), U21.10 (G)
SIGN_R1: D21.2 (A), J1.28
SIGN_R2: D22.2 (A), J1.5
SSEL_R1_0: J1.2, U2.1 (A0), U3.1 (A0)
SSEL_R1_1: J1.3, U2.2 (A1), U3.2 (A1)
SSEL_R1_2: J1.4, U2.3 (A2), U3.3 (A2)

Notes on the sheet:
Install on board reverse side!

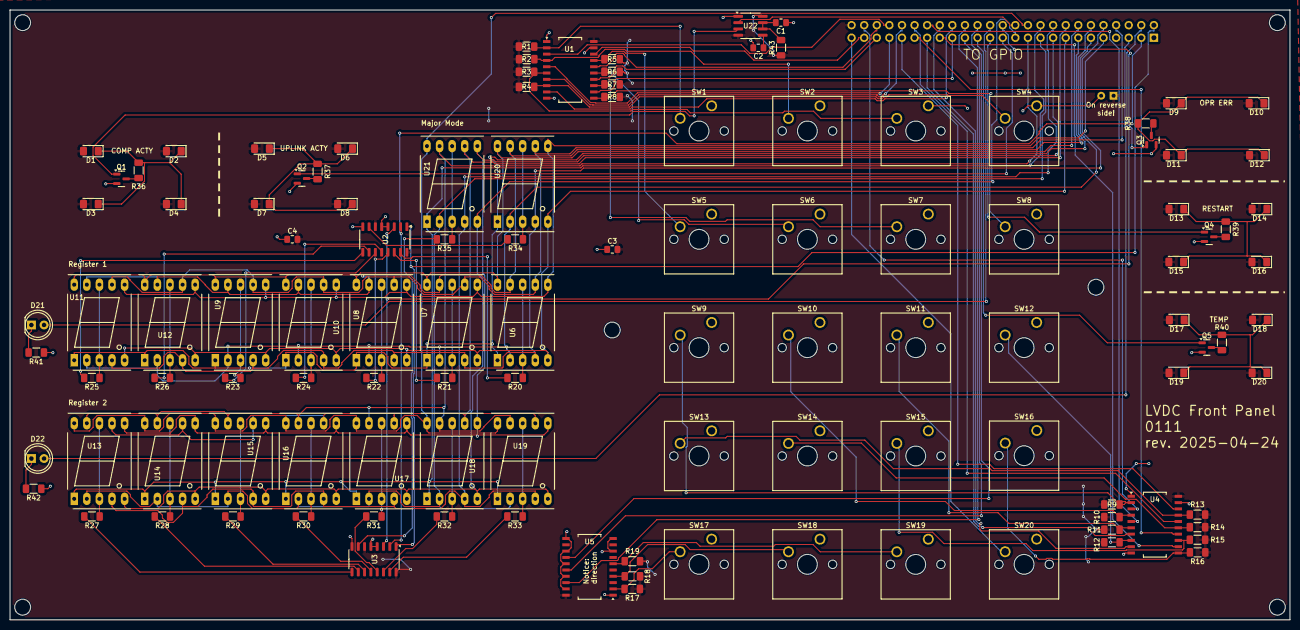
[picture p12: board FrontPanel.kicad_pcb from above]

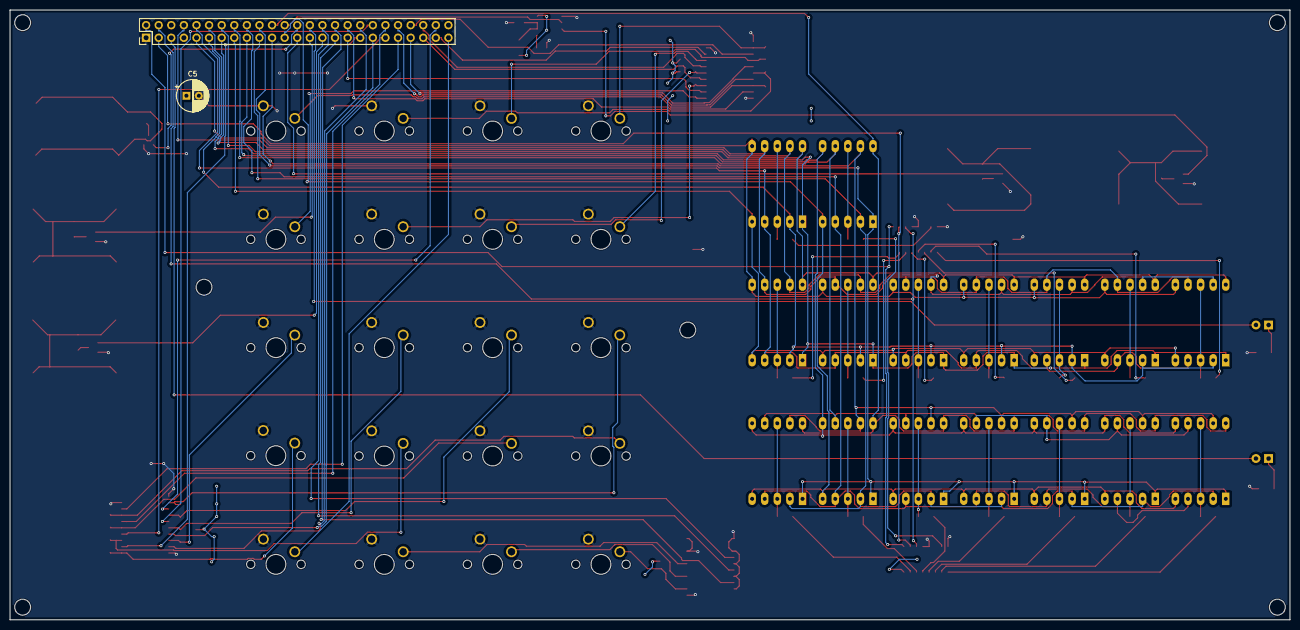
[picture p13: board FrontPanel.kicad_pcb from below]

Board: 2 copper layers, 258.1 x 122.9 mm, 118 parts (2 on the bottom side), 114 nets.

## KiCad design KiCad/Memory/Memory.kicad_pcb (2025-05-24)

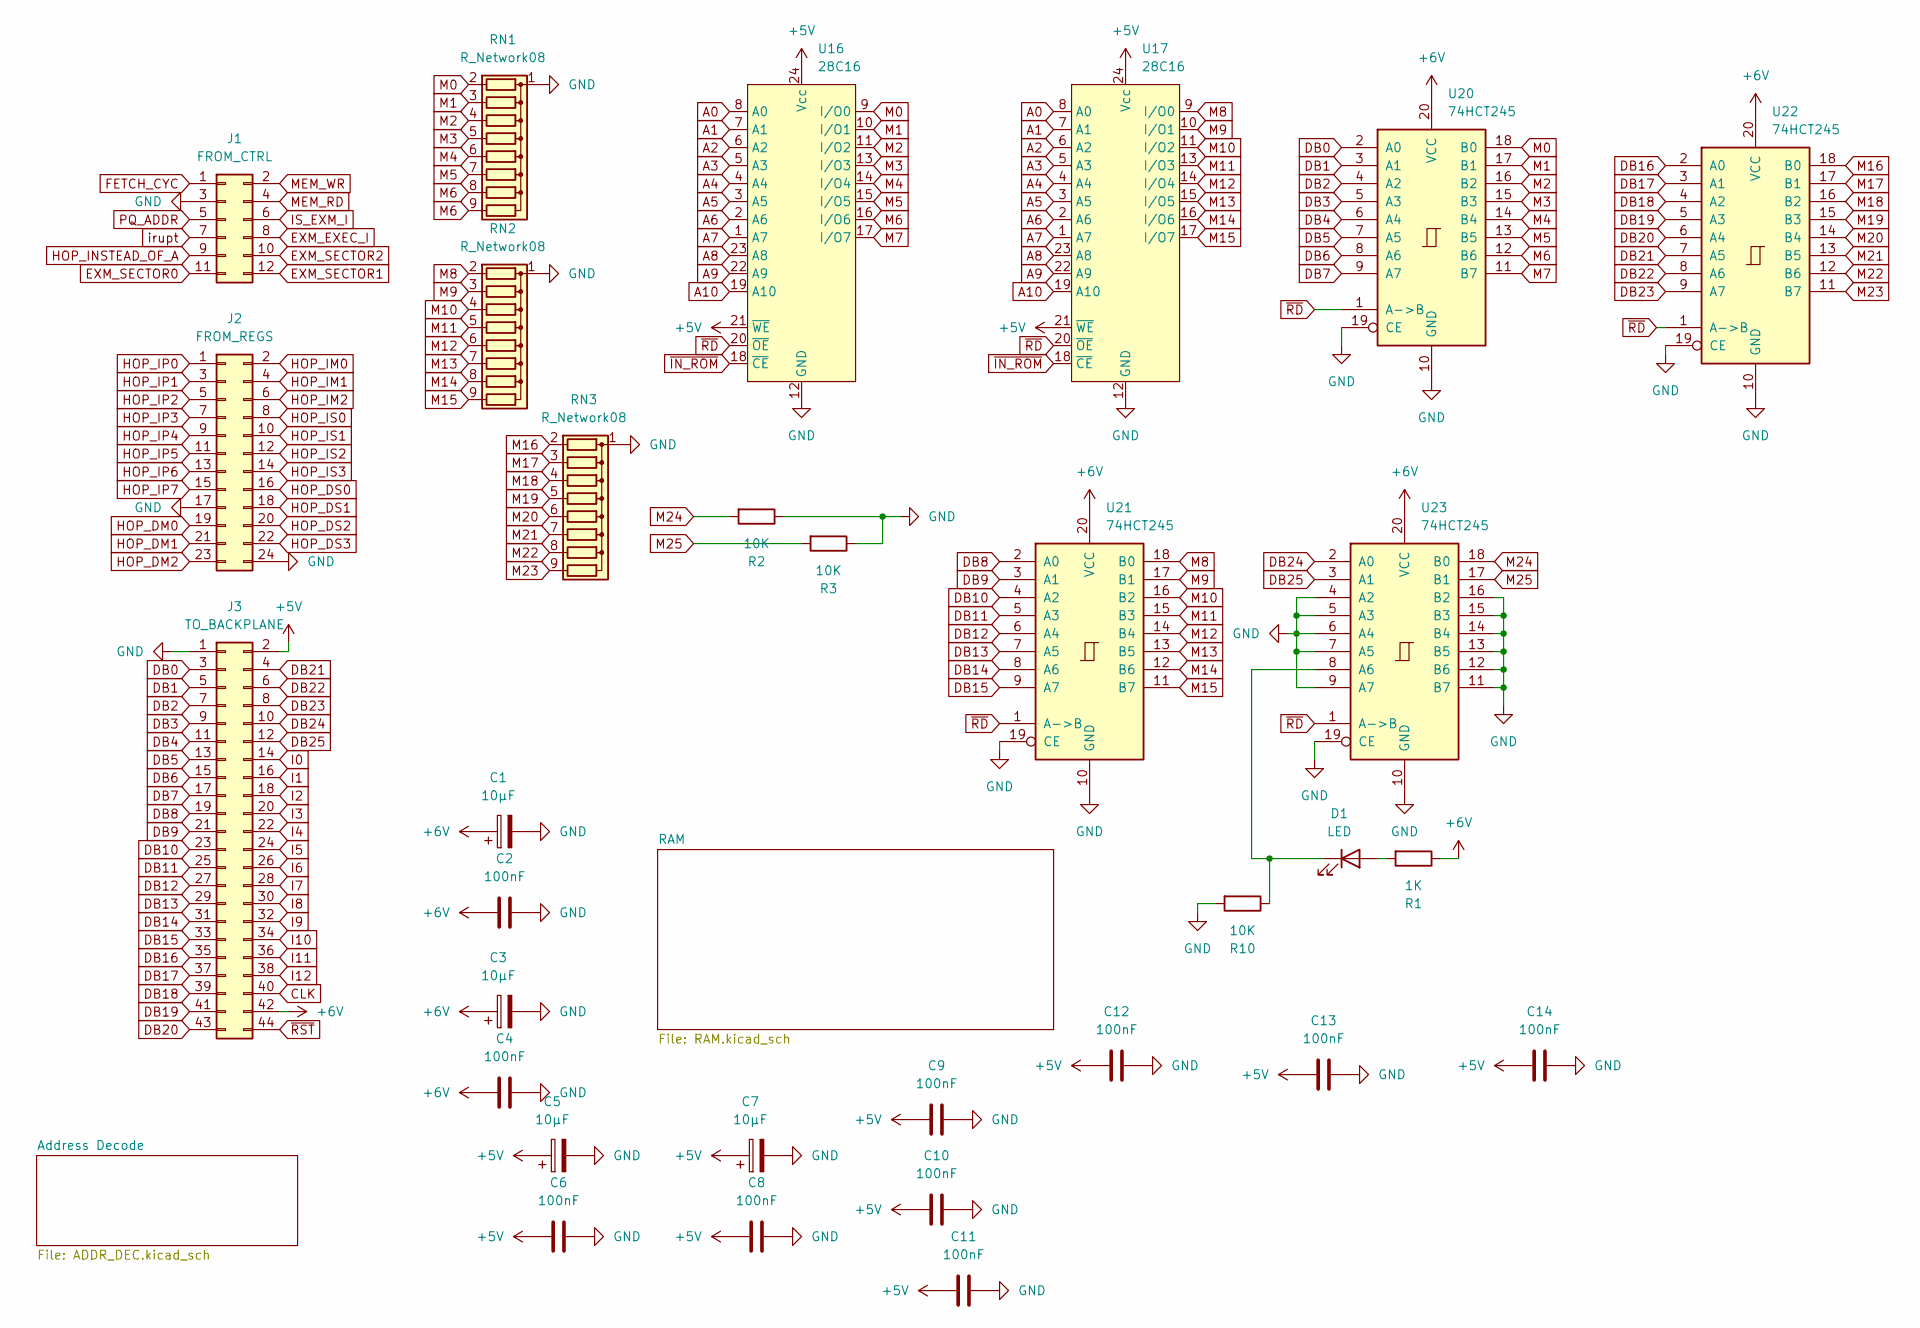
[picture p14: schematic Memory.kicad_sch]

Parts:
C1, C3, C5, C7: 10µF; CP_Radial_D4.0mm_P2.00mm
C2, C4, C6, C8, C9, C10, C11, C12, C13, C14: 100nF; C_0805_2012Metric_Pad1.18x1.45mm_HandSolder
D1: LED; LED_1206_3216Metric_Pad1.42x1.75mm_HandSolder
J1: FROM_CTRL; PinHeader_2x06_P2.54mm_Vertical
J2: FROM_REGS; PinHeader_2x12_P2.54mm_Vertical
J3: TO_BACKPLANE; PinHeader_2x22_P2.54mm_Vertical
R1: 1K; R_1206_3216Metric_Pad1.30x1.75mm_HandSolder
R2, R3, R10: 10K; R_1206_3216Metric_Pad1.30x1.75mm_HandSolder
RN1, RN2, RN3: R_Network08; R_Array_SIP9
U16, U17: 28C16; DIP-24_W15.24mm
U20, U21, U22, U23: 74HCT245; SO-20_12.8x7.5mm_P1.27mm

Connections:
+5V: C5.1, C6.1, C7.1, C8.1, C9.1, C10.1, C11.1, C12.1, C13.1, C14.1, J3.2, U16.21 (~WE), U16.24 (Vcc), U17.21 (~WE), U17.24 (Vcc); also elsewhere on the board
+6V: C1.1, C2.1, C3.1, C4.1, J3.42, R1.1, U20.20 (VCC), U21.20 (VCC), U22.20 (VCC), U23.20 (VCC)
A0: U16.8 (A0), U17.8 (A0); also elsewhere on the board
A1: U16.7 (A1), U17.7 (A1); also elsewhere on the board
A2: U16.6 (A2), U17.6 (A2); also elsewhere on the board
A3: U16.5 (A3), U17.5 (A3); also elsewhere on the board
A4: U16.4 (A4), U17.4 (A4); also elsewhere on the board
A5: U16.3 (A5), U17.3 (A5); also elsewhere on the board
A6: U16.2 (A6), U17.2 (A6); also elsewhere on the board
A7: U16.1 (A7), U17.1 (A7); also elsewhere on the board
A8: U16.23 (A8), U17.23 (A8); also elsewhere on the board
A9: U16.22 (A9), U17.22 (A9); also elsewhere on the board
A10: U16.19 (A10), U17.19 (A10); also elsewhere on the board
CLK: J3.40
DB0: J3.3, U20.2 (A0)
DB1: J3.5, U20.3 (A1)
DB2: J3.7, U20.4 (A2)
DB3: J3.9, U20.5 (A3)
DB4: J3.11, U20.6 (A4)
DB5: J3.13, U20.7 (A5)
DB6: J3.15, U20.8 (A6)
DB7: J3.17, U20.9 (A7)
DB8: J3.19, U21.2 (A0)
DB9: J3.21, U21.3 (A1)
DB10: J3.23, U21.4 (A2)
DB11: J3.25, U21.5 (A3)
DB12: J3.27, U21.6 (A4)
DB13: J3.29, U21.7 (A5)
DB14: J3.31, U21.8 (A6)
DB15: J3.33, U21.9 (A7)
DB16: J3.35, U22.2 (A0)
DB17: J3.37, U22.3 (A1)
DB18: J3.39, U22.4 (A2)
DB19: J3.41, U22.5 (A3)
DB20: J3.43, U22.6 (A4)
DB21: J3.4, U22.7 (A5)
DB22: J3.6, U22.8 (A6)
DB23: J3.8, U22.9 (A7)
DB24: J3.10, U23.2 (A0)
DB25: J3.12, U23.3 (A1)
EXM_EXEC_I: J1.8; also elsewhere on the board
EXM_SECTOR0: J1.11; also elsewhere on the board
EXM_SECTOR1: J1.12; also elsewhere on the board
EXM_SECTOR2: J1.10; also elsewhere on the board
FETCH_CYC: J1.1; also elsewhere on the board
GND: C1.2, C2.2, C3.2, C4.2, C5.2, C6.2, C7.2, C8.2, C9.2, C10.2, C11.2, C12.2, C13.2, C14.2, J1.3, J2.17, J2.24, J3.1, R2.1, R3.1, R10.2, RN1.1 (common), RN2.1 (common), RN3.1 (common), U16.12 (GND), U17.12 (GND), U20.10 (GND), U20.19 (CE), U21.10 (GND), U21.19 (CE), U22.10 (GND), U22.19 (CE), U23.4 (A2), U23.5 (A3), U23.6 (A4), U23.7 (A5), U23.9 (A7), U23.10 (GND), U23.11 (B7), U23.12 (B6), U23.13 (B5), U23.14 (B4), U23.15 (B3), U23.16 (B2), U23.19 (CE); also elsewhere on the board
HOP_DM0: J2.19; also elsewhere on the board
HOP_DM1: J2.21; also elsewhere on the board
HOP_DM2: J2.23; also elsewhere on the board
HOP_DS0: J2.16; also elsewhere on the board
HOP_DS1: J2.18; also elsewhere on the board
HOP_DS2: J2.20; also elsewhere on the board
HOP_DS3: J2.22; also elsewhere on the board
HOP_IM0: J2.2; also elsewhere on the board
HOP_IM1: J2.4; also elsewhere on the board
HOP_IM2: J2.6; also elsewhere on the board
HOP_INSTEAD_OF_A: J1.9; also elsewhere on the board
HOP_IP0: J2.1; also elsewhere on the board
HOP_IP1: J2.3; also elsewhere on the board
HOP_IP2: J2.5; also elsewhere on the board
HOP_IP3: J2.7; also elsewhere on the board
HOP_IP4: J2.9; also elsewhere on the board
HOP_IP5: J2.11; also elsewhere on the board
HOP_IP6: J2.13; also elsewhere on the board
HOP_IP7: J2.15; also elsewhere on the board
HOP_IS0: J2.8; also elsewhere on the board
HOP_IS1: J2.10; also elsewhere on the board
HOP_IS2: J2.12; also elsewhere on the board
HOP_IS3: J2.14; also elsewhere on the board
I0: J3.14
I1: J3.16
I2: J3.18
I3: J3.20
I4: J3.22; also elsewhere on the board
I5: J3.24; also elsewhere on the board
I6: J3.26; also elsewhere on the board
I7: J3.28; also elsewhere on the board
I8: J3.30; also elsewhere on the board
I9: J3.32; also elsewhere on the board
I10: J3.34; also elsewhere on the board
I11: J3.36; also elsewhere on the board
I12: J3.38; also elsewhere on the board
IS_EXM_I: J1.6; also elsewhere on the board
M0: RN1.2 (R1), U16.9 (I/O0), U20.18 (B0); also elsewhere on the board
M1: RN1.3 (R2), U16.10 (I/O1), U20.17 (B1); also elsewhere on the board
M2: RN1.4 (R3), U16.11 (I/O2), U20.16 (B2); also elsewhere on the board
M3: RN1.5 (R4), U16.13 (I/O3), U20.15 (B3); also elsewhere on the board
M4: RN1.6 (R5), U16.14 (I/O4), U20.14 (B4); also elsewhere on the board
M5: RN1.7 (R6), U16.15 (I/O5), U20.13 (B5); also elsewhere on the board
M6: RN1.8 (R7), RN1.9 (R8), U16.16 (I/O6), U20.12 (B6); also elsewhere on the board
M7: U16.17 (I/O7), U20.11 (B7); also elsewhere on the board
M8: RN2.2 (R1), U17.9 (I/O0), U21.18 (B0); also elsewhere on the board
M9: RN2.3 (R2), U17.10 (I/O1), U21.17 (B1); also elsewhere on the board
M10: RN2.4 (R3), U17.11 (I/O2), U21.16 (B2); also elsewhere on the board
M11: RN2.5 (R4), U17.13 (I/O3), U21.15 (B3); also elsewhere on the board
M12: RN2.6 (R5), U17.14 (I/O4), U21.14 (B4); also elsewhere on the board
M13: RN2.7 (R6), U17.15 (I/O5), U21.13 (B5); also elsewhere on the board
M14: RN2.8 (R7), U17.16 (I/O6), U21.12 (B6); also elsewhere on the board
M15: RN2.9 (R8), U17.17 (I/O7), U21.11 (B7); also elsewhere on the board
M16: RN3.2 (R1), U22.18 (B0); also elsewhere on the board
M17: RN3.3 (R2), U22.17 (B1); also elsewhere on the board
M18: RN3.4 (R3), U22.16 (B2); also elsewhere on the board
M19: RN3.5 (R4), U22.15 (B3); also elsewhere on the board
M20: RN3.6 (R5), U22.14 (B4); also elsewhere on the board
M21: RN3.7 (R6), U22.13 (B5); also elsewhere on the board
M22: RN3.8 (R7), U22.12 (B6); also elsewhere on the board
M23: RN3.9 (R8), U22.11 (B7); also elsewhere on the board
M24: R2.2, U23.18 (B0); also elsewhere on the board
M25: R3.2, U23.17 (B1); also elsewhere on the board
MEM_RD: J1.4; also elsewhere on the board
MEM_WR: J1.2; also elsewhere on the board
unnamed: D1.2 (A), R1.2
unnamed: D1.1 (K), R10.1, U23.8 (A6)
PQ_ADDR: J1.5; also elsewhere on the board
irupt: J1.7; also elsewhere on the board
~IN_ROM: U16.18 (~CE), U17.18 (~CE); also elsewhere on the board
~RD: U16.20 (~OE), U17.20 (~OE), U20.1 (A->B), U21.1 (A->B), U22.1 (A->B), U23.1 (A->B); also elsewhere on the board
~RST: J3.44

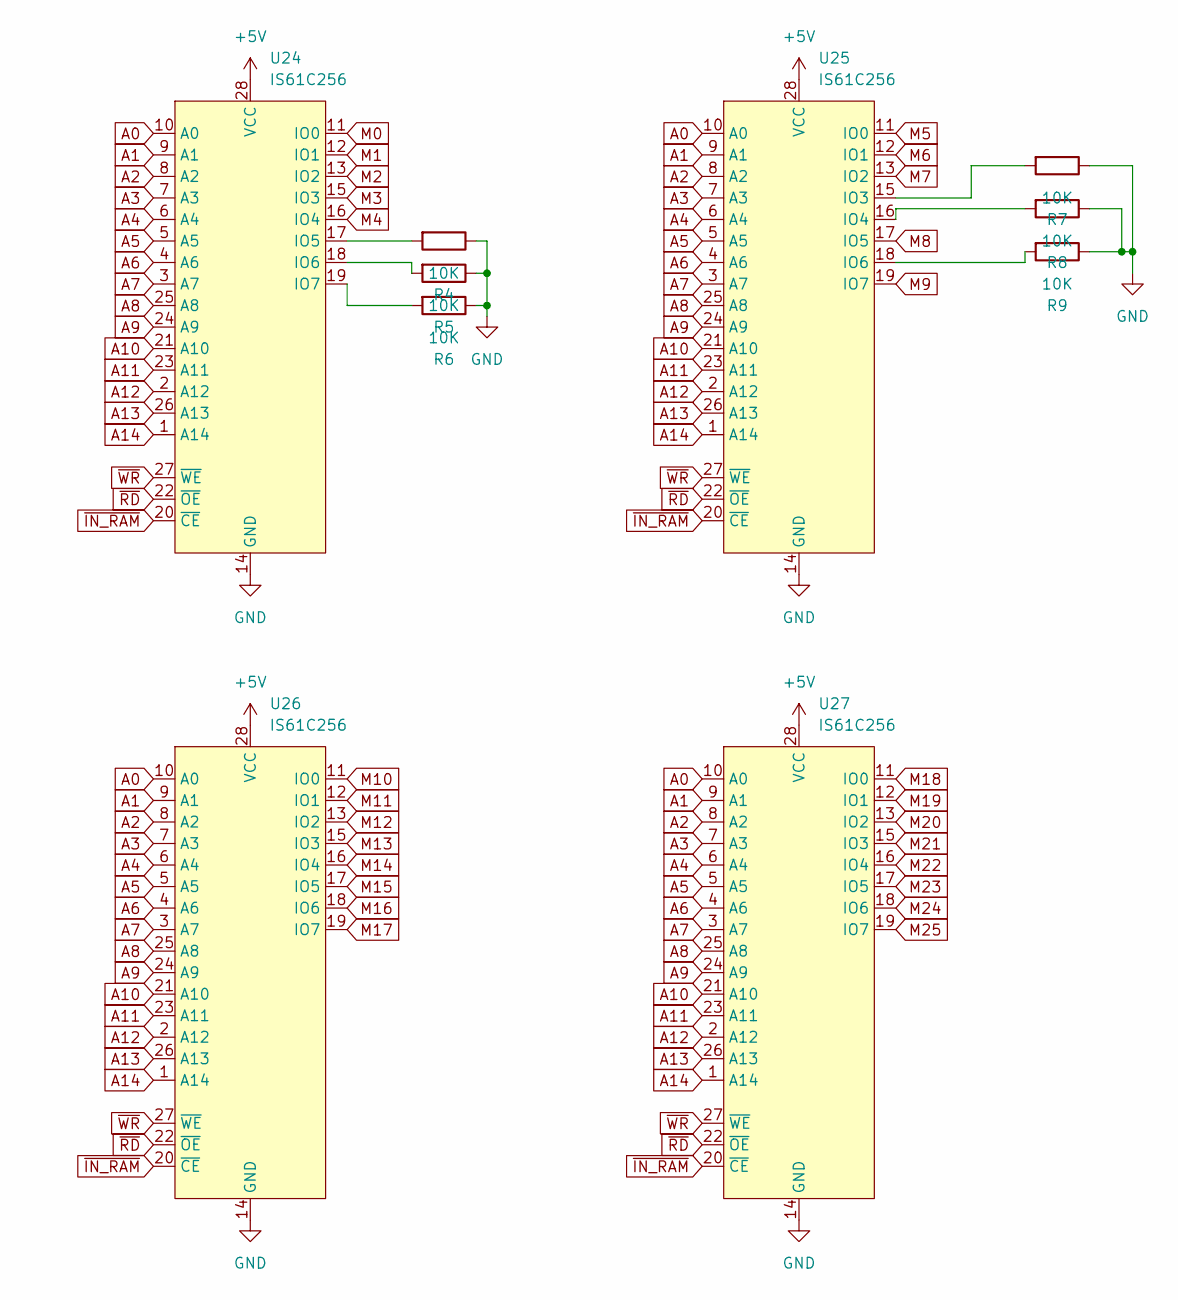
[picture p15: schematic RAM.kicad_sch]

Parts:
R4, R5, R6, R7, R8, R9: 10K; R_1206_3216Metric_Pad1.30x1.75mm_HandSolder
U24, U25, U26, U27: IS61C256; DIP-28_W7.62mm

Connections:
+5V: U24.28 (VCC), U25.28 (VCC), U26.28 (VCC), U27.28 (VCC); also elsewhere on the board
A0: U24.10 (A0), U25.10 (A0), U26.10 (A0), U27.10 (A0); also elsewhere on the board
A1: U24.9 (A1), U25.9 (A1), U26.9 (A1), U27.9 (A1); also elsewhere on the board
A2: U24.8 (A2), U25.8 (A2), U26.8 (A2), U27.8 (A2); also elsewhere on the board
A3: U24.7 (A3), U25.7 (A3), U26.7 (A3), U27.7 (A3); also elsewhere on the board
A4: U24.6 (A4), U25.6 (A4), U26.6 (A4), U27.6 (A4); also elsewhere on the board
A5: U24.5 (A5), U25.5 (A5), U26.5 (A5), U27.5 (A5); also elsewhere on the board
A6: U24.4 (A6), U25.4 (A6), U26.4 (A6), U27.4 (A6); also elsewhere on the board
A7: U24.3 (A7), U25.3 (A7), U26.3 (A7), U27.3 (A7); also elsewhere on the board
A8: U24.25 (A8), U25.25 (A8), U26.25 (A8), U27.25 (A8); also elsewhere on the board
A9: U24.24 (A9), U25.24 (A9), U26.24 (A9), U27.24 (A9); also elsewhere on the board
A10: U24.21 (A10), U25.21 (A10), U26.21 (A10), U27.21 (A10); also elsewhere on the board
A11: U24.23 (A11), U25.23 (A11), U26.23 (A11), U27.23 (A11); also elsewhere on the board
A12: U24.2 (A12), U25.2 (A12), U26.2 (A12), U27.2 (A12); also elsewhere on the board
A13: U24.26 (A13), U25.26 (A13), U26.26 (A13), U27.26 (A13); also elsewhere on the board
A14: U24.1 (A14), U25.1 (A14), U26.1 (A14), U27.1 (A14); also elsewhere on the board
GND: R4.1, R5.1, R6.1, R7.1, R8.1, R9.1, U24.14 (GND), U25.14 (GND), U26.14 (GND), U27.14 (GND); also elsewhere on the board
M0: U24.11 (IO0); also elsewhere on the board
M1: U24.12 (IO1); also elsewhere on the board
M2: U24.13 (IO2); also elsewhere on the board
M3: U24.15 (IO3); also elsewhere on the board
M4: U24.16 (IO4); also elsewhere on the board
M5: U25.11 (IO0); also elsewhere on the board
M6: U25.12 (IO1); also elsewhere on the board
M7: U25.13 (IO2); also elsewhere on the board
M8: U25.17 (IO5); also elsewhere on the board
M9: U25.19 (IO7); also elsewhere on the board
M10: U26.11 (IO0); also elsewhere on the board
M11: U26.12 (IO1); also elsewhere on the board
M12: U26.13 (IO2); also elsewhere on the board
M13: U26.15 (IO3); also elsewhere on the board
M14: U26.16 (IO4); also elsewhere on the board
M15: U26.17 (IO5); also elsewhere on the board
M16: U26.18 (IO6); also elsewhere on the board
M17: U26.19 (IO7); also elsewhere on the board
M18: U27.11 (IO0); also elsewhere on the board
M19: U27.12 (IO1); also elsewhere on the board
M20: U27.13 (IO2); also elsewhere on the board
M21: U27.15 (IO3); also elsewhere on the board
M22: U27.16 (IO4); also elsewhere on the board
M23: U27.17 (IO5); also elsewhere on the board
M24: U27.18 (IO6); also elsewhere on the board
M25: U27.19 (IO7); also elsewhere on the board
unnamed: R4.2, U24.17 (IO5)
unnamed: R5.2, U24.18 (IO6)
unnamed: R6.2, U24.19 (IO7)
unnamed: R7.2, U25.15 (IO3)
unnamed: R8.2, U25.16 (IO4)
unnamed: R9.2, U25.18 (IO6)
~IN_RAM: U24.20 (~CE), U25.20 (~CE), U26.20 (~CE), U27.20 (~CE); also elsewhere on the board
~RD: U24.22 (~OE), U25.22 (~OE), U26.22 (~OE), U27.22 (~OE); also elsewhere on the board
~WR: U24.27 (~WE), U25.27 (~WE), U26.27 (~WE), U27.27 (~WE); also elsewhere on the board


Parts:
U1, U5: 74HCT32; SO-14_3.9x8.65mm_P1.27mm
U2, U8, U14: 74HCT08; SO-14_3.9x8.65mm_P1.27mm
U3: 74HCT04; SO-14_3.9x8.65mm_P1.27mm
U4, U9, U10, U11, U12: 74HCT157; SO-16_3.9x9.9mm_P1.27mm
U6, U7: 74HCT11; SO-14_3.9x8.65mm_P1.27mm
U13: 74HC688; SO-20_12.8x7.5mm_P1.27mm
U15: 74HC32; SO-14_3.9x8.65mm_P1.27mm
U18: 74HCT00; SO-14_3.9x8.65mm_P1.27mm
U19: 74HC02; SO-14_3.9x8.65mm_P1.27mm

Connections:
+5V: U1.14 (VCC), U2.14 (VCC), U3.14 (VCC), U4.10 (I1c), U4.16 (VCC), U5.14 (VCC), U6.14 (VCC), U7.14 (VCC), U8.14 (VCC), U9.16 (VCC), U10.16 (VCC), U11.16 (VCC), U12.13 (I1d), U12.16 (VCC), U13.3 (R0), U13.5 (R1), U13.7 (R2), U13.9 (R3), U13.12 (R4), U13.14 (R5), U13.16 (R6), U13.18 (R7), U13.20 (VCC), U14.14 (VCC), U15.14 (VCC), U18.14 (VCC), U19.14 (VCC); also elsewhere on the board
A0: U9.4 (Za); also elsewhere on the board
A1: U9.7 (Zb); also elsewhere on the board
A2: U9.9 (Zc); also elsewhere on the board
A3: U9.12 (Zd); also elsewhere on the board
A4: U10.4 (Za); also elsewhere on the board
A5: U10.7 (Zb); also elsewhere on the board
A6: U10.9 (Zc); also elsewhere on the board
A7: U10.12 (Zd); also elsewhere on the board
A8: U11.4 (Za); also elsewhere on the board
A9: U11.7 (Zb); also elsewhere on the board
A10: U11.9 (Zc), U15.2; also elsewhere on the board
A11: U11.12 (Zd), U15.9; also elsewhere on the board
A12: U12.4 (Za), U15.10; also elsewhere on the board
A13: U12.7 (Zb), U15.1; also elsewhere on the board
A14: U1.13, U12.9 (Zc); also elsewhere on the board
D_ADDR0: U6.12, U9.2 (I0a), U14.12
D_ADDR1: U3.11, U6.6, U9.5 (I0b), U14.2
D_ADDR2: U6.8, U9.11 (I0c), U13.6 (P2)
D_ADDR3: U7.12, U9.14 (I0d), U13.8 (P3)
D_ADDR4: U7.6, U10.2 (I0a), U13.11 (P4)
D_ADDR5: U8.3, U10.5 (I0b), U13.13 (P5)
D_ADDR6: U8.6, U10.11 (I0c), U13.15 (P6)
D_ADDR7: U8.8, U10.14 (I0d), U13.17 (P7)
D_ADDR8: U5.3, U11.2 (I0a), U13.2 (P0)
D_ADDR9: U5.6, U11.5 (I0b), U13.4 (P1)
D_ADDR10: U5.8, U7.10, U11.11 (I0c)
D_ADDR11: U5.11, U7.11, U11.14 (I0d)
EXM_EXEC_I: U3.3, U4.1 (S); also elsewhere on the board
EXM_SECTOR0: U4.13 (I1d); also elsewhere on the board
EXM_SECTOR1: U4.3 (I1a); also elsewhere on the board
EXM_SECTOR2: U4.6 (I1b); also elsewhere on the board
FETCH_CYC: U3.13, U8.12, U19.6; also elsewhere on the board
GND: U1.7 (GND), U1.12, U2.7 (GND), U3.7 (GND), U4.8 (GND), U4.15 (E), U5.7 (GND), U6.7 (GND), U7.7 (GND), U8.7 (GND), U9.8 (GND), U9.15 (E), U10.8 (GND), U10.15 (E), U11.8 (GND), U11.15 (E), U12.8 (GND), U12.14 (I0d), U12.15 (E), U13.1 (G), U13.10 (GND), U14.7 (GND), U15.7 (GND), U18.7 (GND), U19.7 (GND); also elsewhere on the board
HOP_DM0: U12.2 (I0a); also elsewhere on the board
HOP_DM1: U12.5 (I0b); also elsewhere on the board
HOP_DM2: U12.11 (I0c); also elsewhere on the board
HOP_DS0: U1.2; also elsewhere on the board
HOP_DS1: U2.2; also elsewhere on the board
HOP_DS2: U2.5; also elsewhere on the board
HOP_DS3: U2.10; also elsewhere on the board
HOP_IM0: U12.3 (I1a); also elsewhere on the board
HOP_IM1: U12.6 (I1b); also elsewhere on the board
HOP_IM2: U12.10 (I1c); also elsewhere on the board
HOP_INSTEAD_OF_A: U14.3; also elsewhere on the board
HOP_IP0: U9.3 (I1a); also elsewhere on the board
HOP_IP1: U9.6 (I1b); also elsewhere on the board
HOP_IP2: U9.10 (I1c); also elsewhere on the board
HOP_IP3: U9.13 (I1d); also elsewhere on the board
HOP_IP4: U10.3 (I1a); also elsewhere on the board
HOP_IP5: U10.6 (I1b); also elsewhere on the board
HOP_IP6: U10.10 (I1c); also elsewhere on the board
HOP_IP7: U10.13 (I1d); also elsewhere on the board
HOP_IS0: U11.3 (I1a); also elsewhere on the board
HOP_IS1: U11.6 (I1b); also elsewhere on the board
HOP_IS2: U11.10 (I1c); also elsewhere on the board
HOP_IS3: U11.13 (I1d); also elsewhere on the board
I4: U1.4; also elsewhere on the board
I5: U6.1; also elsewhere on the board
I6: U6.3; also elsewhere on the board
I7: U6.9; also elsewhere on the board
I8: U7.1; also elsewhere on the board
I9: U7.3; also elsewhere on the board
I10: U8.1; also elsewhere on the board
I11: U8.4; also elsewhere on the board
I12: U1.9; also elsewhere on the board
IS_EXM_I: U1.5, U1.10, U3.5; also elsewhere on the board
IS_SPECIAL_ADDR: U7.8, U14.1, U14.4
MEM_RD: U18.13; also elsewhere on the board
MEM_WR: U18.4; also elsewhere on the board
unnamed: U1.6, U2.13
unnamed: U1.8, U8.9
unnamed: U1.11, U15.13
unnamed: U2.12, U3.4
unnamed: U3.8, U7.9
unnamed: U1.3, U4.2 (I0a)
unnamed: U2.3, U4.5 (I0b)
unnamed: U2.6, U4.11 (I0c)
unnamed: U2.8, U4.14 (I0d)
unnamed: U4.4 (Za), U5.1
unnamed: U4.7 (Zb), U5.4
unnamed: U4.9 (Zc), U5.9
unnamed: U4.12 (Zd), U5.12
unnamed: U8.11, U9.1 (S), U10.1 (S), U11.1 (S), U12.1 (S)
unnamed: U3.9, U13.19 (P=R)
unnamed: U3.10, U14.5
unnamed: U14.6, U14.9
unnamed: U14.10, U14.11
unnamed: U3.12, U14.13
unnamed: U15.3, U15.4
unnamed: U15.5, U15.8
unnamed: U15.6, U15.12
unnamed: U18.8, U19.11, U19.12
unnamed: U2.11, U18.9
unnamed: U18.11, U19.2, U19.3
unnamed: U18.3, U18.5, U18.12
unnamed: U19.1, U19.5
unnamed: U5.2, U5.5, U5.10, U5.13, U19.13
PQ_ADDR: U14.8, U18.1, U18.2; also elsewhere on the board
irupt: U1.1, U3.1; also elsewhere on the board
~IN_RAM: U19.10; also elsewhere on the board
~IN_ROM: U15.11, U19.8, U19.9; also elsewhere on the board
~IS_EXM_I: U3.6, U6.2, U6.4, U6.10, U7.2, U7.4, U8.13
~RD: U19.4; also elsewhere on the board
~WR: U18.6; also elsewhere on the board
~irupt: U2.1, U2.4, U2.9, U3.2, U6.5, U6.11, U6.13, U7.5, U7.13, U8.2, U8.5, U8.10, U18.10


Board: 4 copper layers, 209.5 x 108.5 mm, 58 parts (0 on the bottom side), 167 nets.

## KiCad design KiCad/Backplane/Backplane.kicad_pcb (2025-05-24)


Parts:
C1: 100nF; C_0805_2012Metric_Pad1.18x1.45mm_HandSolder
C2: 10µF; CP_Radial_D4.0mm_P2.00mm
C3: 1µF; C_0805_2012Metric_Pad1.18x1.45mm_HandSolder
D1, D2: LED; LED_1206_3216Metric_Pad1.42x1.75mm_HandSolder
J1: SLOT1; PinHeader_2x22_P2.54mm_Vertical
J2: SLOT2; PinHeader_2x22_P2.54mm_Vertical
J3: SLOT3; PinHeader_2x22_P2.54mm_Vertical
J4: SLOT4; PinHeader_2x22_P2.54mm_Vertical
J5: SLOT5; PinHeader_2x22_P2.54mm_Vertical
J6: GPIO; PinHeader_2x22_P2.54mm_Vertical
J7, J8: Screw_Terminal_01x02; TerminalBlock_bornier-2_P5.08mm
R1, R2, R3, R4, R5, R6, R7: 2K; R_1206_3216Metric_Pad1.30x1.75mm_HandSolder
RN1, RN2, RN3: R_Network08; R_Array_SIP9
U1: 74HCT04; DIP-14_W7.62mm

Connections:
+5V: C1.1, C2.1, C3.1, D1.2 (A), J1.2, J2.2, J3.2, J4.2, J5.2, J6.2, J7.1, U1.14 (VCC)
+6V: D2.2 (A), J1.42, J2.42, J3.42, J4.42, J5.42, J6.42, J8.1
DB0: J1.3, J2.3, J3.3, J4.3, J5.3, J6.3, RN1.2 (R1)
DB1: J1.5, J2.5, J3.5, J4.5, J5.5, J6.5, RN1.3 (R2)
DB2: J1.7, J2.7, J3.7, J4.7, J5.7, J6.7, RN1.4 (R3)
DB3: J1.9, J2.9, J3.9, J4.9, J5.9, J6.9, RN1.5 (R4)
DB4: J1.11, J2.11, J3.11, J4.11, J5.11, J6.11, RN1.6 (R5)
DB5: J1.13, J2.13, J3.13, J4.13, J5.13, J6.13, RN1.7 (R6)
DB6: J1.15, J2.15, J3.15, J4.15, J5.15, J6.15, RN1.8 (R7)
DB7: J1.17, J2.17, J3.17, J4.17, J5.17, J6.17, RN1.9 (R8)
DB8: J1.19, J2.19, J3.19, J4.19, J5.19, J6.19, RN2.2 (R1)
DB9: J1.21, J2.21, J3.21, J4.21, J5.21, J6.21, RN2.3 (R2)
DB10: J1.23, J2.23, J3.23, J4.23, J5.23, J6.23, RN2.4 (R3)
DB11: J1.25, J2.25, J3.25, J4.25, J5.25, J6.25, RN2.5 (R4)
DB12: J1.27, J2.27, J3.27, J4.27, J5.27, J6.27, RN2.6 (R5)
DB13: J1.29, J2.29, J3.29, J4.29, J5.29, J6.29, RN2.7 (R6)
DB14: J1.31, J2.31, J3.31, J4.31, J5.31, J6.31, RN2.8 (R7)
DB15: J1.33, J2.33, J3.33, J4.33, J5.33, J6.33, RN2.9 (R8)
DB16: J1.35, J2.35, J3.35, J4.35, J5.35, J6.35, RN3.2 (R1)
DB17: J1.37, J2.37, J3.37, J4.37, J5.37, J6.37, RN3.3 (R2)
DB18: J1.39, J2.39, J3.39, J4.39, J5.39, J6.39, RN3.4 (R3)
DB19: J1.41, J2.41, J3.41, J4.41, J5.41, J6.41, RN3.5 (R4)
DB20: J1.43, J2.43, J3.43, J4.43, J5.43, J6.43, RN3.6 (R5)
DB21: J1.4, J2.4, J3.4, J4.4, J5.4, J6.4, R5.2
DB22: J1.6, J2.6, J3.6, J4.6, J5.6, J6.6, R6.2
DB23: J1.8, J2.8, J3.8, J4.8, J5.8, J6.8, R7.2
DB24: J1.10, J2.10, J3.10, J4.10, J5.10, J6.10, R3.2
DB25: J1.12, J2.12, J3.12, J4.12, J5.12, J6.12, R4.2
GND: C1.2, C2.2, C3.2, J1.1, J2.1, J3.1, J4.1, J5.1, J6.1, J7.2, R1.1, R2.1, R3.1, R4.1, R5.1, R6.1, R7.1, RN1.1 (common), RN2.1 (common), RN3.1 (common), U1.7 (GND)
I0: J1.14, J2.14, J3.14, J4.14, J5.14, J6.14
I1: J1.16, J2.16, J3.16, J4.16, J5.16, J6.16
I2: J1.18, J2.18, J3.18, J4.18, J5.18, J6.18
I3: J1.20, J2.20, J3.20, J4.20, J5.20, J6.20
I4: J1.22, J2.22, J3.22, J4.22, J5.22, J6.22
I5: J1.24, J2.24, J3.24, J4.24, J5.24, J6.24
I6: J1.26, J2.26, J3.26, J4.26, J5.26, J6.26
I7: J1.28, J2.28, J3.28, J4.28, J5.28, J6.28
I8: J1.30, J2.30, J3.30, J4.30, J5.30, J6.30
I9: J1.32, J2.32, J3.32, J4.32, J5.32, J6.32
I10: J1.34, J2.34, J3.34, J4.34, J5.34, J6.34
I11: J1.36, J2.36, J3.36, J4.36, J5.36, J6.36
I12: J1.38, J2.38, J3.38, J4.38, J5.38, J6.38
unnamed: D1.1 (K), R1.2
unnamed: D2.1 (K), R2.2
unnamed: J1.40, U1.12
unnamed: J2.40, U1.10
unnamed: J3.40, U1.8
unnamed: J4.40, U1.6
unnamed: J5.40, U1.4
unnamed: J6.40, U1.1
unnamed: U1.2, U1.3, U1.5, U1.9, U1.11, U1.13
~RST: J1.44, J2.44, J3.44, J4.44, J5.44, J6.44



Board: 4 copper layers, 153.9 x 60.5 mm, 24 parts (6 on the bottom side), 52 nets.

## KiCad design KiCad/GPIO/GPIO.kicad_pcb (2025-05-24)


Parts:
C1: 10µF; CP_Radial_D4.0mm_P2.00mm
C2, C3, C7, C8, C10, C11: 1µF; C_0805_2012Metric_Pad1.18x1.45mm_HandSolder
D1: LED; LED_1206_3216Metric_Pad1.42x1.75mm_HandSolder
J1: JTAG; PinHeader_2x05_P2.54mm_Vertical
J2: TO_BACKPLANE; PinHeader_2x22_P2.54mm_Vertical
J3, J4, J5, J10: Conn_01x01; PinHeader_1x01_P2.54mm_Vertical
J7, J8, J16: Conn_01x04; PinHeader_1x04_P2.54mm_Vertical
J11: TO_FP; PinHeader_2x25_P2.54mm_Vertical
J13, J14: Conn_01x08; PinHeader_1x08_P2.54mm_Vertical
R1, R2, R3, R4, R5, R6, R7, R8, R9, R10, R11, R28, R29, R30, R31, R32, R33: 10K; R_1206_3216Metric_Pad1.30x1.75mm_HandSolder
R12: 330; R_1206_3216Metric_Pad1.30x1.75mm_HandSolder
U1: EPM240T100; LQFP-100_14x14mm_P0.5mm
U2: MCP1319MT-29LE-OT; SOT-23-5_HandSoldering
U3: W25Q32FVSS; DIP-8_W7.62mm_Socket; Part # W25Q32JVSSIQ
U4: AMS1117-3.3; SOT-223-3_TabPin2
U5, U30: 74HC574; SO-20_12.8x7.5mm_P1.27mm
U6, U25, U26: 74HCT244; SO-20_12.8x7.5mm_P1.27mm
U7: 74HCT74; SO-14_3.9x8.65mm_P1.27mm
U8, U9, U11, U12, U13, U14, U20, U21, U22, U24, U27, U28: SN74LV1T34DCK; SOT-23-5
U10: SN74ALVC164245DGG; TSSOP-48_6.1x12.5mm_P0.5mm

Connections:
+3V3: C2.2, C3.2, J1.4, R1.2, R3.2, R4.2, R5.2, R6.2, R7.1, R31.1, U1.9 (VCCIO1), U1.13 (VCCINT), U1.31 (VCCIO1), U1.45 (VCCIO1), U1.59 (VCCIO2), U1.63 (VCCINT), U1.80 (VCCIO2), U1.94 (VCCIO2), U2.5 (VDD), U3.8 (VCC), U4.2 (VO), U8.5 (VCC), U10.31 (V_{CC(A)}), U10.42 (V_{CC(A)}), U11.5 (VCC), U12.5 (VCC), U13.5 (VCC), U14.5 (VCC), U27.5 (VCC), U28.5 (VCC); also elsewhere on the board
+5V: C1.1, C7.2, C8.2, J2.2, J7.3, J8.3, J11.50, J16.3, U4.3 (VI), U5.20 (VCC), U7.1 (~R), U7.4 (~S), U7.10 (~S), U7.13 (~R), U9.5 (VCC), U10.7 (V_{CC(B)}), U10.18 (V_{CC(B)}), U20.5 (VCC), U21.5 (VCC), U22.5 (VCC), U24.5 (VCC), U30.20 (VCC); also elsewhere on the board
+6V: C10.2, C11.2, J2.42, U6.20 (VCC), U7.14 (VCC), U25.20 (VCC), U26.20 (VCC)
BDIR: R11.2, U1.14 (IO1_14/GCLK1), U10.1 (1DIR), U10.24 (2DIR)
CLK: J2.40, U7.9 (Q)
CLKIN: J5.1, U7.3 (C), U8.2 (A)
CLOCK_3V: U1.12 (IO1_12/GCLK0), U8.4 (Y)
DB0: J2.3, U5.2 (D0), U6.18 (1Y0), U10.23 (2B7), U25.18 (1Y0), U26.18 (1Y0); also elsewhere on the board
DB1: J2.5, U5.3 (D1), U6.16 (1Y1), U10.22 (2B6), U25.16 (1Y1), U26.16 (1Y1); also elsewhere on the board
DB2: J2.7, U5.4 (D2), U6.14 (1Y2), U10.20 (2B5), U25.14 (1Y2), U26.14 (1Y2); also elsewhere on the board
DB3: J2.9, U5.5 (D3), U6.12 (1Y3), U10.19 (2B4), U25.12 (1Y3), U26.12 (1Y3); also elsewhere on the board
DB4: J2.11, U5.6 (D4), U6.3 (2Y0), U10.17 (2B3), U25.3 (2Y0), U26.3 (2Y0); also elsewhere on the board
DB5: J2.13, U5.7 (D5), U6.5 (2Y1), U10.16 (2B2), U25.5 (2Y1), U26.5 (2Y1); also elsewhere on the board
DB6: J2.15, U5.8 (D6), U6.7 (2Y2), U10.14 (2B1), U25.7 (2Y2), U26.7 (2Y2); also elsewhere on the board
DB7: J2.17, U5.9 (D7), U6.9 (2Y3), U10.13 (2B0), U25.9 (2Y3), U26.9 (2Y3); also elsewhere on the board
DB8: J2.19, U10.12 (1B7), U30.2 (D0); also elsewhere on the board
DB9: J2.21, U10.11 (1B6), U30.3 (D1); also elsewhere on the board
DB10: J2.23, U10.9 (1B5), U30.4 (D2); also elsewhere on the board
DB11: J2.25, U10.8 (1B4), U30.5 (D3); also elsewhere on the board
DB12: J2.27, U10.6 (1B3), U30.6 (D4); also elsewhere on the board
DB13: J2.29, U10.5 (1B2), U30.7 (D5); also elsewhere on the board
DB14: J2.31, U10.3 (1B1), U30.8 (D6)
DB15: J2.33, U10.2 (1B0), U30.9 (D7)
DB16: J2.35
DB17: J2.37
DB18: J2.39
DB19: J2.41
DB20: J2.43
DB21: J2.4
DB22: J2.6
DB23: J2.8
DB24: J2.10
DB25: J2.12
FP_RST: J11.49, R1.1, U2.4 (~MR)
FP_U_ACTY: J11.25; also elsewhere on the board
GND: C1.2, C2.1, C3.1, C7.1, C8.1, C10.1, C11.1, J1.2, J1.10, J2.1, J7.4, J8.4, J11.1, J16.4, R2.2, R8.2, R10.2, R11.1, R12.1, R28.2, R30.2, R33.2, U1.10 (GNDIO), U1.11 (GNDINT), U1.32 (GNDIO), U1.46 (GNDIO), U1.60 (GNDIO), U1.65 (GNDINT), U1.79 (GNDIO), U1.93 (GNDIO), U2.2 (VSS), U3.4 (GND), U4.1 (GND), U5.1 (OE), U5.10 (GND), U6.10 (GND), U7.7 (GND), U8.3 (GND), U9.3 (GND), U10.4 (GND), U10.10 (GND), U10.15 (GND), U10.21 (GND), U10.25 (2~OE), U10.28 (GND), U10.34 (GND), U10.39 (GND), U10.45 (GND), U10.48 (1~OE), U11.3 (GND), U12.3 (GND), U13.3 (GND), U14.3 (GND), U20.3 (GND), U21.3 (GND), U22.3 (GND), U24.3 (GND), U25.10 (GND), U26.10 (GND), U27.3 (GND), U28.3 (GND), U30.1 (OE), U30.10 (GND); also elsewhere on the board
GPI0: J14.1, U26.8 (1A3)
GPI1: J14.2, U26.17 (2A0)
GPI2: J14.3, U26.15 (2A1)
GPI3: J14.4, U26.13 (2A2)
GPI4: J14.5, U26.11 (2A3)
GPIO_LOAD: U1.38 (IO1_38), U5.11 (Load), U30.11 (Load)
I0: J2.14
I1: J2.16
I2: J2.18
I3: J2.20
I4: J2.22
I5: J2.24, U11.2 (A)
I6: J2.26, U12.2 (A)
I7: J2.28, U13.2 (A)
I8: J2.30, U14.2 (A)
I9: J2.32
I10: J2.34
I11: J2.36
I12: J2.38
INT_INHIBIT: R32.2, U5.13 (Q6)
INT_OUT: J10.1, U24.4 (Y)
KEY_0: J11.48, U6.2 (1A0)
KEY_1: J11.47, U6.4 (1A1)
KEY_2: J11.46, U6.6 (1A2)
KEY_3: J11.45, U6.8 (1A3)
KEY_4: J11.44, U6.17 (2A0)
KEY_5: J11.43, U6.15 (2A1)
KEY_6: J11.42, U6.13 (2A2)
KEY_7: J11.41, U6.11 (2A3)
KEY_8: J11.40, U25.2 (1A0)
KEY_9: J11.39, U25.4 (1A1)
KEY_A: J11.38, U25.6 (1A2)
KEY_B: J11.37, U25.8 (1A3)
KEY_C: J11.36, U25.17 (2A0)
KEY_CLEAR: J11.31, R29.2, U26.4 (1A1)
KEY_D: J11.35, U25.15 (2A1)
KEY_E: J11.34, U25.13 (2A2)
KEY_ENTER: J11.32, U26.2 (1A0)
KEY_F: J11.33, U25.11 (2A3)
KEY_MINUS: J11.30, U26.6 (1A2)
LAMP_COMP_ACTY: J11.24, U5.14 (Q5)
LAMP_OPR_ERR: J11.26, U5.15 (Q4)
LAMP_RESTART: J11.27, U5.16 (Q3)
LAMP_TEMP: J11.29, U5.18 (Q1)
unnamed: D1.2 (A), U1.86 (IO2_86)
unnamed: D1.1 (K), R12.2
unnamed: J1.1, R2.1, U1.24 (TCK)
unnamed: J1.3, R3.1, U1.25 (TDO)
unnamed: J1.5, R4.1, U1.22 (TMS)
unnamed: J1.9, R5.1, U1.23 (TDI)
unnamed: J2.44, U9.4 (Y)
unnamed: J7.1, U20.4 (Y)
unnamed: J7.2, J8.2, U21.4 (Y)
unnamed: J8.1, U22.4 (Y)
unnamed: J13.1, U30.19 (Q0)
unnamed: J13.2, U30.18 (Q1)
unnamed: J13.3, U30.17 (Q2)
unnamed: J13.4, U30.16 (Q3)
unnamed: J13.5, U30.15 (Q4)
unnamed: J13.6, U30.14 (Q5)
unnamed: J13.7, U30.13 (Q6)
unnamed: J13.8, U30.12 (Q7)
unnamed: J16.1, U1.90 (IO2_90)
unnamed: J16.2, U1.91 (IO2_91)
unnamed: U1.2 (IO1_2), U27.4 (Y)
unnamed: U1.3 (IO1_3), U28.4 (Y)
unnamed: R29.1, R30.1, U1.37 (IO1_37)
unnamed: R32.1, R33.1, U1.40 (IO1_40)
unnamed: R28.1, U1.95 (IO2_95), U24.2 (A)
unnamed: U1.96 (IO2_96), U20.2 (A)
unnamed: U1.97 (IO2_97), U22.2 (A)
unnamed: R7.2, U3.7 (~HOLD(D3))
unnamed: R6.1, U3.3 (~WP(D2))
unnamed: R9.1, U5.12 (Q7)
unnamed: U7.2 (D), U7.6 (~Q)
unnamed: U7.5 (Q), U7.11 (C)
unnamed: U7.8 (~Q), U7.12 (D)
RCHECK: U1.8 (IO1_8); also elsewhere on the board
RD0: U1.6 (IO1_6); also elsewhere on the board
RD0_OUT: U1.57 (IO2_57); also elsewhere on the board
RD1: U1.7 (IO1_7); also elsewhere on the board
RD1_OUT: U1.55 (IO2_55); also elsewhere on the board
RPULSE: U1.5 (IO1_5); also elsewhere on the board
RPULSE_OUT: U1.82 (IO2_82); also elsewhere on the board
SCK: J14.8, U1.100 (IO2_100), U3.6 (SCK)
SDI: J14.7, R8.1, U1.99 (IO2_99), U3.2 (SO(D1))
SDO: J14.6, U1.98 (IO2_98), U3.5 (SI(D0)), U21.2 (A)
SEG_R1_A: J11.8, U1.58 (IO2_58)
SEG_R1_B: J11.9, U1.61 (IO2_61)
SEG_R1_C: J11.10, U1.62 (IO2_62/GCLK2)
SEG_R1_D: J11.11, U1.64 (IO2_64/GCLK3)
SEG_R1_DP: J11.15, U1.69 (IO2_69)
SEG_R1_E: J11.12, U1.66 (IO2_66)
SEG_R1_F: J11.13, U1.67 (IO2_67)
SEG_R1_G: J11.14, U1.68 (IO2_68)
SEG_R2_A: J11.16, U1.70 (IO2_70)
SEG_R2_B: J11.17, U1.71 (IO2_71)
SEG_R2_C: J11.18, U1.72 (IO2_72)
SEG_R2_D: J11.19, U1.73 (IO2_73)
SEG_R2_DP: J11.23, U1.77 (IO2_77)
SEG_R2_E: J11.20, U1.74 (IO2_74)
SEG_R2_F: J11.21, U1.75 (IO2_75)
SEG_R2_G: J11.22, U1.76 (IO2_76)
SIGN_R1: J11.28, U5.17 (Q2)
SIGN_R2: J11.5, U5.19 (Q0)
SSEL_R1_0: J11.2, U1.52 (IO2_52)
SSEL_R1_1: J11.3, U1.53 (IO2_53)
SSEL_R1_2: J11.4, U1.54 (IO2_54)
TEMP: U1.83 (IO2_83); also elsewhere on the board
V3_DB0: U1.36 (IO1_36), U10.26 (2A7)
V3_DB1: U1.35 (IO1_35), U10.27 (2A6)
V3_DB2: U1.34 (IO1_34), U10.29 (2A5)
V3_DB3: U1.33 (IO1_33), U10.30 (2A4)
V3_DB4: U1.30 (IO1_30), U10.32 (2A3)
V3_DB5: U1.29 (IO1_29), U10.33 (2A2)
V3_DB6: U1.28 (IO1_28), U10.35 (2A1)
V3_DB7: U1.27 (IO1_27), U10.36 (2A0)
V3_DB8: U1.26 (IO1_26), U10.37 (1A7)
V3_DB9: U1.21 (IO1_21), U10.38 (1A6)
V3_DB10: U1.20 (IO1_20), U10.40 (1A5)
V3_DB11: U1.19 (IO1_19), U10.41 (1A4)
V3_DB12: U1.18 (IO1_18), U10.43 (1A3)
V3_DB13: U1.17 (IO1_17), U10.44 (1A2)
V3_DB14: U1.16 (IO1_16), U10.46 (1A1)
V3_DB15: U1.15 (IO1_15), U10.47 (1A0)
V3_I5: U1.47 (IO1_47), U11.4 (Y)
V3_I6: U1.48 (IO1_48), U12.4 (Y)
V3_I7: U1.49 (IO1_49), U13.4 (Y)
V3_I8: U1.50 (IO1_50), U14.4 (Y)
~FLASH_CS: R9.2, R10.1, U3.1 (~CS)
~GPIO_READ: R31.2, U1.39 (IO1_39), U6.1 (1OE), U6.19 (2OE), U25.1 (1OE), U25.19 (2OE), U26.1 (1OE), U26.19 (2OE)
~IOR: J3.1, U27.2 (A)
~IOW: J4.1, U28.2 (A); also elsewhere on the board
~RST: U1.44 (IO1_44/DEV_CLRn), U2.1 (~RST), U9.2 (A)
~SID_CE: U1.1 (IO2_1), U1.88 (IO2_88); also elsewhere on the board

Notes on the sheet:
To LED strips


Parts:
J12: Conn_01x04; PinHeader_1x04_P2.54mm_Vertical
R34, R35, R36, R37: 10K; R_1206_3216Metric_Pad1.30x1.75mm_HandSolder
U29: 74HC32; SO-14_3.9x8.65mm_P1.27mm

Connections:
+3V3: R34.2, R35.2, R36.2, R37.2, U29.14 (VCC); also elsewhere on the board
GND: U29.7 (GND), U29.12; also elsewhere on the board
unnamed: U29.3, U29.4
unnamed: U29.5, U29.8
unnamed: U29.6, U29.13
T0: J12.4, R34.1, U29.1
T1: J12.3, R35.1, U29.2
T2: J12.2, R36.1, U29.9
TBAT: J12.1, R37.1, U29.10
TEMP: U29.11; also elsewhere on the board

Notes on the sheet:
Must be HC


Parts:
C9, C12, C13, C14, C15, C16, C17, C18: 1µF; C_0805_2012Metric_Pad1.18x1.45mm_HandSolder
D2: LED; LED_1206_3216Metric_Pad1.42x1.75mm_HandSolder
J9, J15: RADIO_MODULE; PinSocket_1x04_P2.54mm_Vertical
R19: 33K; R_1206_3216Metric_Pad1.30x1.75mm_HandSolder
R20, R21, R22, R23, R24, R25, R26, R27, R39: 10K; R_1206_3216Metric_Pad1.30x1.75mm_HandSolder
R38: 2K; R_1206_3216Metric_Pad1.30x1.75mm_HandSolder
R40: 1M; R_1206_3216Metric_Pad1.30x1.75mm_HandSolder
U23: HT12D; DIP-18_W7.62mm
U31: 74AHC1G86; SOT-23-5_HandSoldering
U32: HT12E; DIP-18_W7.62mm
U33, U34, U35: SN74LV1T34DCK; SOT-23-5

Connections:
+3V3: C15.2, C16.2, C17.2, J15.2, R39.2; also elsewhere on the board
+5V: C9.2, C12.2, C13.2, C14.2, C18.2, J9.1, U23.18 (VDD), U31.5 (VCC), U32.18 (VDD), U33.5 (VCC), U34.5 (VCC), U35.5 (VCC); also elsewhere on the board
FP_U_ACTY: R20.1, U23.10 (D8); also elsewhere on the board
GND: C9.1, C12.1, C13.1, C14.1, C15.1, C16.1, C17.1, C18.1, J9.4, J15.1, R24.1, R25.1, R26.1, R27.1, R38.1, U23.1 (A0), U23.7 (A6), U23.9 (VSS), U31.3 (GND), U32.1 (A0), U32.2 (A1), U32.7 (A6), U32.9 (VSS), U33.3 (GND), U34.3 (GND), U35.3 (GND); also elsewhere on the board
unnamed: D2.2 (A), U23.17 (VT)
unnamed: D2.1 (K), R38.2
unnamed: J9.2, U23.14 (DIN)
unnamed: J15.3, R39.1, U32.17 (DOUT)
unnamed: R21.1, U23.11 (D9)
unnamed: R22.1, U23.12 (D10)
unnamed: R23.1, U23.13 (D11)
unnamed: R19.1, U23.16 (OSC1)
unnamed: R19.2, U23.15 (OSC2)
unnamed: U32.10 (D8), U33.4 (Y)
unnamed: U31.1, U32.11 (D9), U34.4 (Y)
unnamed: U31.2, U32.12 (D10), U35.4 (Y)
unnamed: U31.4, U32.13 (D11)
unnamed: R40.1, U32.16 (X1)
unnamed: R40.2, U32.15 (X2)
RCHECK: R23.2, R24.2; also elsewhere on the board
RD0: R21.2, R26.2; also elsewhere on the board
RD0_OUT: U34.2 (A); also elsewhere on the board
RD1: R22.2, R25.2; also elsewhere on the board
RD1_OUT: U35.2 (A); also elsewhere on the board
RPULSE: R20.2, R27.2; also elsewhere on the board
RPULSE_OUT: U33.2 (A); also elsewhere on the board


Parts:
C4, C5, C6: 1µF; C_0805_2012Metric_Pad1.18x1.45mm_HandSolder
J6: AUDIO_OUT; TerminalBlock_bornier-2_P5.08mm
R13, R14, R16, R17: 10K; R_1206_3216Metric_Pad1.30x1.75mm_HandSolder
R15, R18: 1K; R_1206_3216Metric_Pad1.30x1.75mm_HandSolder
RV1: 10K; Potentiometer_ACP_CA9-V10_Vertical
U15: 74HC74; SO-14_3.9x8.65mm_P1.27mm
U16: gfmpw1-multi; DIP-40_W15.24mm_Socket
U17, U18: DAC7611; DIP-8_W7.62mm
U19: LM358; DIP-8_W7.62mm
X1: CXO_DIP8; Oscillator_DIP-8

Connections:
+2V5: C5.2, U19.1, U19.2 (-), U19.5 (+)
+5V: R13.1, U15.1 (~R), U15.4 (~S), U15.10 (~S), U15.13 (~R), U15.14 (VCC), U16.17 (IO20), U16.40 (5V), U17.1 (Vdd), U17.6 (~CLR), U18.1 (Vdd), U18.6 (~CLR), U19.8 (V+), X1.8 (Vcc); also elsewhere on the board
DB0: U16.2 (IO5); also elsewhere on the board
DB1: U16.3 (IO6); also elsewhere on the board
DB2: U16.4 (IO7); also elsewhere on the board
DB3: U16.5 (IO8); also elsewhere on the board
DB4: U16.6 (IO9); also elsewhere on the board
DB5: U16.7 (IO10); also elsewhere on the board
DB6: U16.8 (IO11); also elsewhere on the board
DB7: U16.9 (IO12); also elsewhere on the board
DB8: U16.10 (IO13); also elsewhere on the board
DB9: U16.11 (IO14); also elsewhere on the board
DB10: U16.12 (IO15); also elsewhere on the board
DB11: U16.13 (IO16); also elsewhere on the board
DB12: U16.14 (IO17); also elsewhere on the board
DB13: U16.15 (IO18); also elsewhere on the board
GND: C4.1, C5.1, J6.1, R14.2, R18.1, U15.7 (GND), U16.20 (GND), U16.34 (IO36), U16.35 (IO37), U17.2 (~CS), U17.7 (GND), U18.2 (~CS), U18.7 (GND), U19.4 (V-), X1.4 (GND); also elsewhere on the board
unnamed: C6.2, R15.2, U19.7
unnamed: C6.1, J6.2, R18.2
unnamed: R15.1, RV1.1, RV1.2
unnamed: U15.3 (C), U15.11 (C), U16.37 (XCLK), X1.5 (OUT)
unnamed: U15.5 (Q), U16.16 (IO19)
unnamed: U15.9 (Q), U16.18 (IO21)
unnamed: U16.19 (IO22), U17.4 (SDI)
unnamed: U16.21 (IO23), U17.5 (~LD), U18.5 (~LD)
unnamed: U16.22 (IO24), U17.3 (CLK), U18.3 (CLK)
unnamed: U16.23 (IO25), U18.4 (SDI)
unnamed: R16.1, U17.8 (Vout)
unnamed: R17.1, U18.8 (Vout)
unnamed: C4.2, R13.2, R14.1, U19.3 (+)
unnamed: R16.2, R17.2, RV1.3, U19.6 (-)
~IOW: U15.2 (D); also elsewhere on the board
~SID_CE: U15.12 (D); also elsewhere on the board



Board: 4 copper layers, 209.6 x 108.5 mm, 113 parts (2 on the bottom side), 189 nets.

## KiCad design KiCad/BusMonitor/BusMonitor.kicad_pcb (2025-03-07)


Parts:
C1: 100nF; C_0805_2012Metric_Pad1.18x1.45mm_HandSolder
C2: 10µF; CP_Radial_D4.0mm_P2.00mm
D1, D2, D3, D4, D5, D6, D7, D8, D9, D10, D11, D12, D13, D14, D15, D16, D17, D18, D19, D20, D21, D22, D23, D24, D25, D26, D27, D28, D29, D30, D31, D32, D33, D34, D35, D36, D37, D38, D39, D40: LED; LED_1206_3216Metric_Pad1.42x1.75mm_HandSolder
J1: TO_BACKPLANE; PinHeader_2x22_P2.54mm_Vertical
R1, R2, R3, R4, R5: 330; R_1206_3216Metric_Pad1.30x1.75mm_HandSolder
U1, U2, U3, U4, U5: 74HCT244; SO-20_12.8x7.5mm_P1.27mm

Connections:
+5V: C1.1, C2.1, J1.2, U1.20 (VCC), U2.20 (VCC), U3.20 (VCC), U4.20 (VCC), U5.20 (VCC)
+6V: J1.42
CLK: J1.40, U5.11 (2A3)
DB0: J1.3, U1.2 (1A0)
DB1: J1.5, U1.4 (1A1)
DB2: J1.7, U1.6 (1A2)
DB3: J1.9, U1.8 (1A3)
DB4: J1.11, U1.17 (2A0)
DB5: J1.13, U1.15 (2A1)
DB6: J1.15, U1.13 (2A2)
DB7: J1.17, U1.11 (2A3)
DB8: J1.19, U2.2 (1A0)
DB9: J1.21, U2.4 (1A1)
DB10: J1.23, U2.6 (1A2)
DB11: J1.25, U2.8 (1A3)
DB12: J1.27, U2.17 (2A0)
DB13: J1.29, U2.15 (2A1)
DB14: J1.31, U2.13 (2A2)
DB15: J1.33, U2.11 (2A3)
DB16: J1.35, U3.2 (1A0)
DB17: J1.37, U3.4 (1A1)
DB18: J1.39, U3.6 (1A2)
DB19: J1.41, U3.8 (1A3)
DB20: J1.43, U3.17 (2A0)
DB21: J1.4, U3.15 (2A1)
DB22: J1.6, U3.13 (2A2)
DB23: J1.8, U3.11 (2A3)
DB24: J1.10, U4.2 (1A0)
DB25: J1.12, U4.4 (1A1)
GND: C1.2, C2.2, J1.1, R1.2, R2.2, R3.2, R4.2, R5.2, U1.1 (1OE), U1.10 (GND), U1.19 (2OE), U2.1 (1OE), U2.10 (GND), U2.19 (2OE), U3.1 (1OE), U3.10 (GND), U3.19 (2OE), U4.1 (1OE), U4.10 (GND), U4.19 (2OE), U5.1 (1OE), U5.10 (GND), U5.19 (2OE)
I0: J1.14, U4.6 (1A2)
I1: J1.16, U4.8 (1A3)
I2: J1.18, U4.17 (2A0)
I3: J1.20, U4.15 (2A1)
I4: J1.22, U4.13 (2A2)
I5: J1.24, U4.11 (2A3)
I6: J1.26, U5.2 (1A0)
I7: J1.28, U5.4 (1A1)
I8: J1.30, U5.6 (1A2)
I9: J1.32, U5.8 (1A3)
I10: J1.34, U5.17 (2A0)
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

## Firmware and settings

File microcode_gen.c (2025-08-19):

#include <stdio.h>
#include <stdlib.h>
#include <string.h>
#include <stdint.h>

#define ALU_SWAPOPS (1 << 0)
#define ALU_OUTPUT (1 << 1)
#define ALU_IS_SHIFT (1 << 2)
#define ACCUM_WRITE (1 << 3)
#define ACCUM_OUTPUT (1 << 4)
#define INC_PC (1 << 5)
#define CDS_EXEC (1 << 6)
#define HOP_WRITE (1 << 7)
#define TRA_EXEC (1 << 8)
#define MEM_WR (1 << 9)
#define FETCH_CYC (1 << 10)
#define MEM_RD (1 << 11)
#define IS_EXM (1 << 12)
#define IS_IOEXEC (1 << 13)
#define MUL_RST ((1 << 14) | (1 << 15))
#define MUL_LDY_AND_START (1 << 15)
#define MUL_LDX_OR_LDZ (1 << 14)

#define STEP_0 0
#define STEP_1 1
#define STEP_2 2
#define STEP_3 3
#define STEP_4 4
#define STEP_5 5
#define STEP_6 6
#define STEP_7 7
#define A9 (1 << 7)
#define A8 (1 << 8)
#define ACCUM_ZERO (1 << 9)
#define ACCUM_NEG (1 << 10)

void wr_string(FILE *outfile, char *str) {
	while(1) {
		if(*str == 0) return;
		fwrite(str, 1, 1, outfile);
		str++;
	}
}

static uint16_t res[2048];

void instr_simple(uint8_t opcode, uint8_t step, uint16_t signals) {
	res[step + (opcode << 3)] = signals;
	res[step + (opcode << 3) + A9] = signals;
	res[step + (opcode << 3) + A8] = signals;
	res[step + (opcode << 3) + A8 + A9] = signals;
	res[step + (opcode << 3) + ACCUM_ZERO] = signals;
	res[step + (opcode << 3) + ACCUM_ZERO + A9] = signals;
	res[step + (opcode << 3) + ACCUM_ZERO + A8] = signals;
	res[step + (opcode << 3) + ACCUM_ZERO + A8 + A9] = signals;
	res[step + (opcode << 3) + ACCUM_NEG] = signals;
	res[step + (opcode << 3) + ACCUM_NEG + A9] = signals;
	res[step + (opcode << 3) + ACCUM_NEG + A8] = signals;
	res[step + (opcode << 3) + ACCUM_NEG + A8 + A9] = signals;
	res[step + (opcode << 3) + ACCUM_NEG + ACCUM_ZERO] = signals;
	res[step + (opcode << 3) + ACCUM_NEG + ACCUM_ZERO + A9] = signals;
	res[step + (opcode << 3) + ACCUM_NEG + ACCUM_ZERO + A8] = signals;
	res[step + (opcode << 3) + ACCUM_NEG + ACCUM_ZERO + A8 + A9] = signals;
}

void instr_pio(uint8_t opcode, uint8_t is_read, uint8_t step, uint16_t signals) {
	uint16_t o = is_read ? A9 : 0;
	res[step + (opcode << 3) + o] = signals;
	res[step + (opcode << 3) + A8 + o] = signals;
	res[step + (opcode << 3) + ACCUM_ZERO + o] = signals;
	res[step + (opcode << 3) + ACCUM_ZERO + A8 + o] = signals;
	res[step + (opcode << 3) + ACCUM_NEG + o] = signals;
	res[step + (opcode << 3) + ACCUM_NEG + A8 + o] = signals;
	res[step + (opcode << 3) + ACCUM_NEG + ACCUM_ZERO + A8 + o] = signals;
}

void instr_shift(uint8_t step, uint16_t signals) {
	res[step + (0xE << 3) + A9] = signals;
	res[step + (0xE << 3) + A9 + ACCUM_ZERO] = signals;
	res[step + (0xE << 3) + A9 + ACCUM_NEG] = signals;
	res[step + (0xE << 3) + A9 + ACCUM_ZERO + ACCUM_NEG] = signals;
}

void instr_cds(uint8_t step, uint16_t signals) {
	res[step + (0xE << 3) + A8] = signals;
	res[step + (0xE << 3) + A8 + ACCUM_ZERO] = signals;
	res[step + (0xE << 3) + A8 + ACCUM_NEG] = signals;
	res[step + (0xE << 3) + A8 + ACCUM_ZERO + ACCUM_NEG] = signals;
	res[step + (0xE << 3)] = signals;
	res[step + (0xE << 3) + ACCUM_ZERO] = signals;
	res[step + (0xE << 3) + ACCUM_NEG] = signals;
	res[step + (0xE << 3) + ACCUM_ZERO + ACCUM_NEG] = signals;
}

void instr_exm(uint8_t step, uint16_t signals) {
	res[step + (0xE << 3) + A8 + A9] = signals;
	res[step + (0xE << 3) + A8 + A9 + ACCUM_ZERO] = signals;
	res[step + (0xE << 3) + A8 + A9 + ACCUM_NEG] = signals;
	res[step + (0xE << 3) + A8 + A9 + ACCUM_ZERO + ACCUM_NEG] = signals;
}

int main(void) {
	memset(res, 0, 2048 * sizeof(uint16_t));
	
	for(uint8_t i = 0; i < 16; i++) {
		instr_simple(i, STEP_0, FETCH_CYC);
		instr_simple(i, STEP_1, INC_PC);
	}
	
	//HOP
	instr_simple(0x0, STEP_1, MEM_RD | HOP_WRITE);
	instr_simple(0x0, STEP_2, INC_PC);
	
	//SUB
	instr_simple(0x2, STEP_1, MEM_RD);
	instr_simple(0x2, STEP_2, ALU_OUTPUT | ACCUM_WRITE);
	instr_simple(0x2, STEP_3, INC_PC);
	
	//AND
	instr_simple(0x6, STEP_1, MEM_RD);
	instr_simple(0x6, STEP_2, ALU_OUTPUT | ACCUM_WRITE);
	instr_simple(0x6, STEP_3, INC_PC);
	
	//ADD
	instr_simple(0x7, STEP_1, MEM_RD);
	instr_simple(0x7, STEP_2, ALU_OUTPUT | ACCUM_WRITE);
	instr_simple(0x7, STEP_3, INC_PC);
	
	//XOR
	instr_simple(0x9, STEP_1, MEM_RD);
	instr_simple(0x9, STEP_2, ALU_OUTPUT | ACCUM_WRITE);
	instr_simple(0x9, STEP_3, INC_PC);
	
	//RSU
	instr_simple(0xD, STEP_1, MEM_RD | ALU_SWAPOPS);
	instr_simple(0xD, STEP_2, ALU_OUTPUT | ACCUM_WRITE | ALU_SWAPOPS);
	instr_simple(0xD, STEP_3, INC_PC | ALU_SWAPOPS);
	
	//CLA
	instr_simple(0xF, STEP_1, MEM_RD);
	instr_simple(0xF, STEP_2, ALU_OUTPUT | ACCUM_WRITE);
	instr_simple(0xF, STEP_3, INC_PC);
	
	//SHF
	instr_shift(STEP_1, ALU_IS_SHIFT);
	instr_shift(STEP_2, ALU_OUTPUT | ACCUM_WRITE);
	instr_shift(STEP_3, INC_PC);
	
	//CDS
	instr_cds(STEP_1, CDS_EXEC);
	instr_cds(STEP_2, INC_PC);
	
	//TRA
	instr_simple(0x8, STEP_1, TRA_EXEC);
	instr_simple(0x8, STEP_2, INC_PC);
	
	//TNZ
	instr_simple(0x4, STEP_1, TRA_EXEC);
	instr_simple(0x4, STEP_2, INC_PC);
	res[STEP_1 + (0x4 << 3) + ACCUM_ZERO] = 0;
	res[STEP_1 + (0x4 << 3) + ACCUM_ZERO + A9] = 0;
	res[STEP_1 + (0x4 << 3) + ACCUM_ZERO + A8] = 0;
	res[STEP_1 + (0x4 << 3) + ACCUM_ZERO + A8 + A9] = 0;
	res[STEP_1 + (0x4 << 3) + ACCUM_ZERO + ACCUM_NEG] = 0;
	res[STEP_1 + (0x4 << 3) + ACCUM_ZERO + ACCUM_NEG + A9] = 0;
	res[STEP_1 + (0x4 << 3) + ACCUM_ZERO + ACCUM_NEG + A8] = 0;
	res[STEP_1 + (0x4 << 3) + ACCUM_ZERO + ACCUM_NEG + A8 + A9] = 0;
	
	//TMI
	instr_simple(0xC, STEP_1, TRA_EXEC);
	instr_simple(0xC, STEP_2, INC_PC);
	res[STEP_1 + (0xC << 3) + ACCUM_ZERO] = 0;
	res[STEP_1 + (0xC << 3) + ACCUM_ZERO + A9] = 0;
	res[STEP_1 + (0xC << 3) + ACCUM_ZERO + A8] = 0;
	res[STEP_1 + (0xC << 3) + ACCUM_ZERO + A8 + A9] = 0;
	res[STEP_1 + (0xC << 3)] = 0;
	res[STEP_1 + (0xC << 3) + A9] = 0;
	res[STEP_1 + (0xC << 3) + A8] = 0;
	res[STEP_1 + (0xC << 3) + A8 + A9] = 0;
	
	//STO
	instr_simple(0xB, STEP_1, ACCUM_OUTPUT);
	instr_simple(0xB, STEP_2, ACCUM_OUTPUT | MEM_WR);
	instr_simple(0xB, STEP_3, INC_PC);
	
	//DIV
	instr_simple(0x3, STEP_1, 0);
	instr_simple(0x3, STEP_2, MUL_RST);
	instr_simple(0x3, STEP_3, ACCUM_OUTPUT | MUL_LDX_OR_LDZ);
	instr_simple(0x3, STEP_4, MEM_RD | MUL_LDY_AND_START);
	instr_simple(0x3, STEP_5, INC_PC);
	
	//MPY
	instr_simple(0x1, STEP_1, 0);
	instr_simple(0x1, STEP_2, MUL_RST);
	instr_simple(0x1, STEP_3, ACCUM_OUTPUT | MUL_LDX_OR_LDZ);
	instr_simple(0x1, STEP_4, MEM_RD | MUL_LDY_AND_START);
	instr_simple(0x1, STEP_5, INC_PC);
	
	//MPH
	instr_simple(0x5, STEP_1, 0);
	instr_simple(0x5, STEP_2, MUL_RST);
	instr_simple(0x5, STEP_3, ACCUM_OUTPUT | MUL_LDX_OR_LDZ);
	instr_simple(0x5, STEP_4, MEM_RD | MUL_LDY_AND_START);
	instr_simple(0x5, STEP_5, 0);
	instr_simple(0x5, STEP_6, MUL_RST | ACCUM_WRITE);
	instr_simple(0x5, STEP_7, INC_PC);
	
	//IS_EXM line
	for(int i = 0; i < 2048; i++) {
		if(((i >> 3) & 15) != 0xE) continue;
		if((i & A9) == 0) continue;
		if((i & A8) == 0) continue;
		res[i] |= IS_EXM;
	}
	
	//PIO
	instr_pio(0xA, 0, STEP_1, ACCUM_OUTPUT);
	instr_pio(0xA, 0, STEP_2, IS_IOEXEC | ACCUM_OUTPUT);
	instr_pio(0xA, 0, STEP_3, ACCUM_OUTPUT);
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

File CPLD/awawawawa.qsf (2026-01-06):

# -------------------------------------------------------------------------- #
#
# Copyright (C) 2025  Altera Corporation. All rights reserved.
# Your use of Altera Corporation's design tools, logic functions 
# and other software and tools, and any partner logic 
# functions, and any output files from any of the foregoing 
# (including device programming or simulation files), and any 
# associated documentation or information are expressly subject 
# to the terms and conditions of the Altera Program License 
# Subscription Agreement, the Altera Quartus Prime License Agreement,
# the Altera IP License Agreement, or other applicable license
# agreement, including, without limitation, that your use is for
# the sole purpose of programming logic devices manufactured by
# Altera and sold by Altera or its authorized distributors.  Please
# refer to the Altera Software License Subscription Agreements 
# on the Quartus Prime software download page.
#
# -------------------------------------------------------------------------- #
#
# Quartus Prime
# Version 24.1std.0 Build 1077 03/04/2025 SC Lite Edition
# Date created = 00:18:12  Mai 22, 2025
#
# -------------------------------------------------------------------------- #
#
# Notes:
#
# 1) The default values for assignments are stored in the file:
#		awawawawa_assignment_defaults.qdf
#    If this file doesn't exist, see file:
#		assignment_defaults.qdf
#
# 2) Intel recommends that you do not modify this file. This
#    file is updated automatically by the Quartus Prime software
#    and any changes you make may be lost or overwritten.
#
# -------------------------------------------------------------------------- #


set_global_assignment -name FAMILY "MAX II"
set_global_assignment -name DEVICE EPM240T100C5
set_global_assignment -name TOP_LEVEL_ENTITY awawawawa
set_global_assignment -name ORIGINAL_QUARTUS_VERSION 24.1STD.0
set_global_assignment -name PROJECT_CREATION_TIME_DATE "00:18:12  MAI 22, 2025"
set_global_assignment -name LAST_QUARTUS_VERSION "24.1std.0 Lite Edition"
set_global_assignment -name PROJECT_OUTPUT_DIRECTORY output_files
set_global_assignment -name MIN_CORE_JUNCTION_TEMP 0
set_global_assignment -name MAX_CORE_JUNCTION_TEMP 85
set_global_assignment -name DEVICE_FILTER_PACKAGE TQFP
set_global_assignment -name DEVICE_FILTER_PIN_COUNT 100
set_global_assignment -name ERROR_CHECK_FREQUENCY_DIVISOR "-1"
set_global_assignment -name POWER_EXT_SUPPLY_VOLTAGE_TO_REGULATOR 3.3V
set_global_assignment -name VERILOG_FILE awawawawa.v
set_location_assignment PIN_14 -to BDIR
set_location_assignment PIN_38 -to GPIO_LOAD
set_location_assignment PIN_39 -to GPIO_READb
set_location_assignment PIN_50 -to I[3]
set_location_assignment PIN_49 -to I[2]
set_location_assignment PIN_48 -to I[1]
set_location_assignment PIN_47 -to I[0]
set_location_assignment PIN_95 -to INTERRUPT
set_location_assignment PIN_40 -to INT_INHIBIT
set_location_assignment PIN_2 -to IORb
set_location_assignment PIN_3 -to IOWb
set_location_assignment PIN_37 -to KEY_CLEARb
set_location_assignment PIN_41 -to LED
set_location_assignment PIN_69 -to R1_SEGS[7]
set_location_assignment PIN_68 -to R1_SEGS[6]
set_location_assignment PIN_67 -to R1_SEGS[5]
set_location_assignment PIN_66 -to R1_SEGS[4]
set_location_assignment PIN_64 -to R1_SEGS[3]
set_location_assignment PIN_62 -to R1_SEGS[2]
set_location_assignment PIN_61 -to R1_SEGS[1]
set_location_assignment PIN_58 -to R1_SEGS[0]
set_location_assignment PIN_77 -to R2_SEGS[7]
set_location_assignment PIN_76 -to R2_SEGS[6]
set_location_assignment PIN_75 -to R2_SEGS[5]
set_location_assignment PIN_74 -to R2_SEGS[4]
set_location_assignment PIN_73 -to R2_SEGS[3]
set_location_assignment PIN_72 -to R2_SEGS[2]
set_location_assignment PIN_71 -to R2_SEGS[1]
set_location_assignment PIN_70 -to R2_SEGS[0]
set_location_assignment PIN_8 -to RCHECK
set_location_assignment PIN_6 -to RD0
set_location_assignment PIN_7 -to RD1
set_location_assignment PIN_57 -to RD0_OUT
set_location_assignment PIN_55 -to RD1_OUT
set_location_assignment PIN_5 -to RPULSE
set_location_assignment PIN_82 -to RPULSE_OUT
set_location_assignment PIN_100 -to SCK_FLASH
set_location_assignment PIN_97 -to SCK_LED1
set_location_assignment PIN_99 -to SDI
set_location_assignment PIN_98 -to SDO
set_location_assignment PIN_1 -to SID_CEb
set_location_assignment PIN_54 -to SSEL_R1[2]
set_location_assignment PIN_53 -to SSEL_R1[1]
set_location_assignment PIN_52 -to SSEL_R1[0]
set_location_assignment PIN_12 -to clk
set_location_assignment PIN_15 -to bus[15]
set_location_assignment PIN_16 -to bus[14]
set_location_assignment PIN_17 -to bus[13]
set_location_assignment PIN_18 -to bus[12]
set_location_assignment PIN_19 -to bus[11]
set_location_assignment PIN_20 -to bus[10]
set_location_assignment PIN_21 -to bus[9]
set_location_assignment PIN_26 -to bus[8]
set_location_assignment PIN_27 -to bus[7]
set_location_assignment PIN_28 -to bus[6]
set_location_assignment PIN_29 -to bus[5]
set_location_assignment PIN_30 -to bus[4]
set_location_assignment PIN_33 -to bus[3]
set_location_assignment PIN_34 -to bus[2]
set_location_assignment PIN_35 -to bus[1]
set_location_assignment PIN_36 -to bus[0]
set_global_assignment -name AUTO_RESTART_CONFIGURATION OFF
set_global_assignment -name ENABLE_OCT_DONE OFF
set_global_assignment -name ENABLE_CONFIGURATION_PINS OFF
set_global_assignment -name ENABLE_BOOT_SEL_PIN OFF
set_global_assignment -name USE_CONFIGURATION_DEVICE ON
set_global_assignment -name RESERVE_ALL_UNUSED_PINS "AS INPUT TRI-STATED WITH WEAK PULL-UP"
set_global_assignment -name ENABLE_DEVICE_WIDE_RESET ON
set_location_assignment PIN_86 -to BODGE0
set_location_assignment PIN_96 -to BODGE1
set_location_assignment PIN_83 -to TEMP
set_location_assignment PIN_91 -to SDA
set_location_assignment PIN_90 -to SCL

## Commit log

2025-03-12 Simple bootloader program.
    [Registers.kicad_sch, accumulator.kicad_sch, hop.kicad_sch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]
2025-05-24 Prepare for bring-up
    [BOM.ods, Backplane.kicad_pcb, FrontPanel.kicad_pcb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]
2025-08-15 Update schematics with fixes.
    [ALU.kicad_sch, Control.kicad_pcb, Control.kicad_sch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]
2025-08-19 Fix R2 display CPLD bug
    [awawawawa.qsf, awawawawa.v]
2025-08-19 Command handler done
    [GPIO.kicad_sch]
